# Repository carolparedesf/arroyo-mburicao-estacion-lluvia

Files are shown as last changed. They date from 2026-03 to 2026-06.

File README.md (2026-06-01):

# Sistema de adquisición y visualización de datos de sensores de lluvia
### Estaciones meteorológicas distribuidas — Arroyo Mburicao

---

## Descripción

Sistema de monitoreo pluviométrico distribuido a lo largo del arroyo Mburicao. Cada estación integra un sensor óptico de lluvia con comunicación RS485, una PCB propia basada en ESP32-S3 con componentes SMD, y transmisión de datos vía DTU con respaldo local en MicroSD. Los datos se visualizan en tiempo real a través de un dashboard web.

---

## Imágenes del hardware

| Render 3D | PCB | Placa soldada |
|---|---|---|
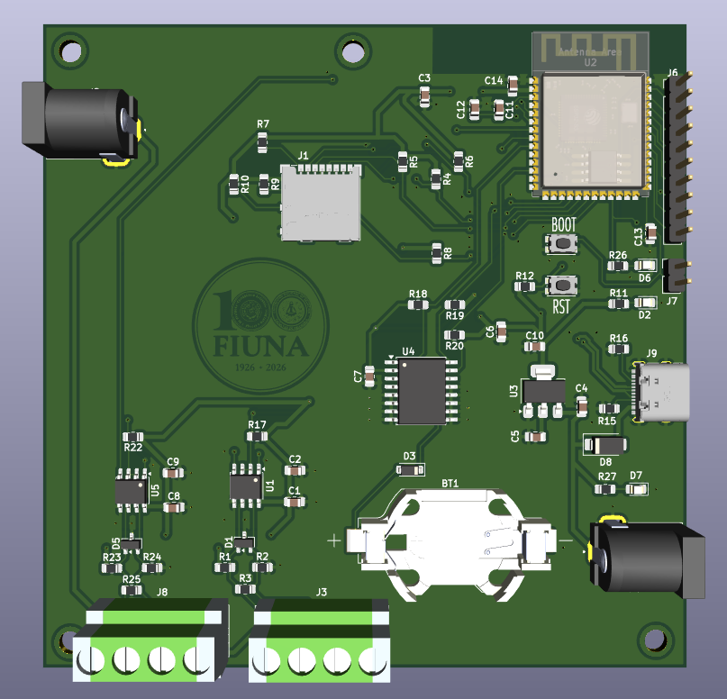
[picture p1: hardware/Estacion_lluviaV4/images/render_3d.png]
Render 3D
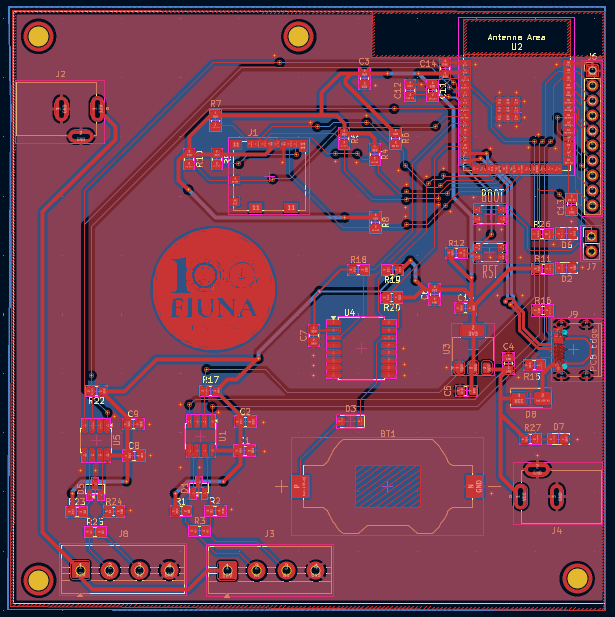
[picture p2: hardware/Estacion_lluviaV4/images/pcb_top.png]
PCB
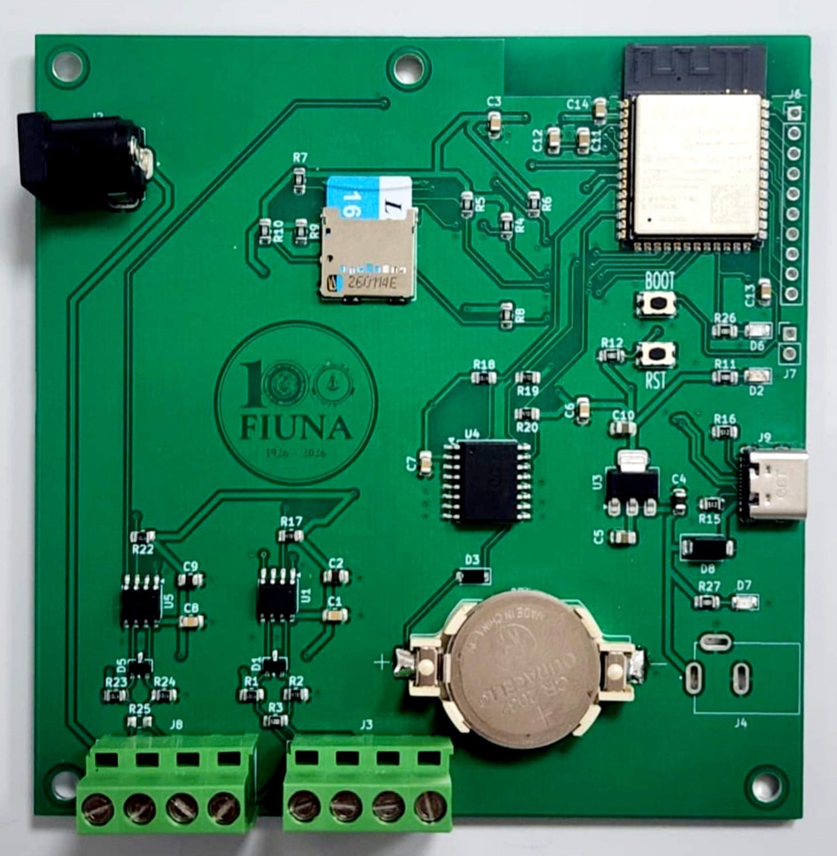
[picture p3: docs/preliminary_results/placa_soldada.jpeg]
Placa soldada
|  |  |  |

## Características principales

- Microcontrolador ESP32-S3 con componentes de montaje superficial (SMD)
- Sensor óptico de lluvia con interfaz RS485 / Modbus RTU
- Transmisión de datos vía DTU (RS485 canal 2)
- Almacenamiento local en MicroSD (`datalog.csv`) con cola de reintentos (`temp.csv`)
- RTC DS3231M para sincronización de slots de medición cada 60 segundos
- Alimentación con reductor a 3.3V
- Caja para intemperie compatible con la estructura de la estación meteorológica
- Dashboard web en tiempo real

---

## Estructura del repositorio

```
arroyo-mburicao-estacion-lluvia/
│
├── hardware/
│   └── Estacion_lluviaV4/
│       ├── BOM/                           # Lista de materiales
│       ├── images/                        # Renders 3D y fotos del PCB
│       ├── planos/                        # Planos técnicos 2D con cotas
│       ├── step/                          # Modelos 3D STEP
│       ├── Estacion_lluviaV4.kicad_pcb    # PCB
│       ├── Estacion_lluviaV4.kicad_sch    # Esquemático principal
│       ├── conector_USB.kicad_sch         # Sub-esquemático USB
│       ├── DS3231.kicad_sch               # Sub-esquemático RTC
│       ├── esp32_modulo.kicad_sch         # Sub-esquemático ESP32-S3
│       ├── sd_to_esp32.kicad_sch          # Sub-esquemático MicroSD
│       ├── ttl_to_rs485.kicad_sch         # Sub-esquemático RS485
│       └── vcc_to_3v3.kicad_sch           # Sub-esquemático alimentación
│
├── software/
│   ├── esp32s3_lluvia/                    # Proyecto principal ESP-IDF
│   │   ├── main/                          # Loop principal y pipeline
│   │   ├── components/                    # Drivers por módulo
│   │   │   ├── config/                    # Configuración de pines
│   │   │   ├── rtc/                       # Driver DS3231M (I2C)
│   │   │   ├── sdcard/                    # MicroSD (SPI + FAT)
│   │   │   ├── modbus_rtu/                # Modbus RTU (RS485 canal 1)
│   │   │   ├── dtu/                       # DTU (RS485 canal 2)
│   │   │   └── rs485/                     # Driver RS485 genérico
│   │   ├── CMakeLists.txt
│   │   └── sdkconfig                      # Configuración del proyecto
│   │
│   └── tests/                             # Pruebas aisladas por componente
│       ├── test_led/                      # Prueba LED debug
│       ├── test_rtc/                      # Prueba DS3231M
│       ├── test_sdcard/                   # Prueba MicroSD
│       └── test_modbus/                   # Prueba sensor lluvia Modbus RTU
│
├── mechanical/
│   ├── caja_tapa/                         # Modelo de la caja para intemperie
│   ├── ensamblaje/                        # Ensamblaje completo
│   └── soporte_sensor/                    # Estructura soporte del sensor
│
├── dashboard/
│   └── README.md                          # Link al repositorio del dashboard
│
└── docs/
    ├── report/                            # Informes de proceso y final
    └── photos/                            # Fotos del prototipo
```
---

## Hardware

### Diagrama de bloques

```
Sensor de lluvia (RS485/Modbus RTU)
            │
            ▼
        ESP32-S3
            ├── RTC DS3231M  (I2C)
            ├── MicroSD      (SPI)
            ├── RS485 canal 1 → Sensor de lluvia
            └── RS485 canal 2 → DTU → Base de datos en la nube
```

### Versiones del PCB

| Versión | Fecha | Estado |
|---|---|---|
| v1.0 | — | Fabricación inicial |
| v2.0 | — | Fabricación inicial |
| v3.0 | — | Fabricación inicial |
| v4.0 | — | En desarrollo |

Los archivos de fabricación se encuentran en `hardware/Estacion_lluviaV4/planos/`.

---

## Software

El código fuente del ESP32-S3 está desarrollado en **ESP-IDF (CMake)** e incluye drivers para RS485, Modbus RTU, DTU, RTC DS3231M y MicroSD.

| Módulo | Descripción |
|---|---|
| `esp32s3_lluvia` | Pipeline completo de medición y transmisión |
| `tests/test_led` | Prueba de LED de debug |
| `tests/test_rtc` | Prueba del RTC DS3231M |
| `tests/test_sdcard` | Prueba de MicroSD |
| `tests/test_modbus` | Prueba del sensor de lluvia vía Modbus RTU |

Ver descripción completa del flujo de operación en [`software/esp32s3_lluvia/README.md`](software/esp32s3_lluvia/README.md).

---

## Dashboard

El dashboard de visualización en línea está desarrollado en Next.js y desplegado en Vercel.

- 🔗 Repositorio: [hydromet-dashboard](https://github.com/carolparedesf/hydromet-dashboard)
- 🌐 Demo en vivo: [hydromet-dashboard.vercel.app](https://hydromet-dashboard.vercel.app)

---

## Costos

Ver lista de materiales completa en [`hardware/Estacion_lluviaV4/BOM/BOM_Estacion_lluviaV4.xlsx`](hardware/Estacion_lluviaV4/BOM/BOM_Estacion_lluviaV4.xlsx).

---

## Resultados

Las mediciones, pruebas y gráficas obtenidas se encuentran en [`docs/preiminary_results/`](docs/results_preiminary/).

---

## Equipo

| Integrante | Contacto |
|---|---|
| Victoria Paredes | carolparedesf@fiuna.edu.py |
| Francisco Gonzalez | frgonzalez@fiuna.edu.py  |
| Melissa Olmedo |  meliolmedo@fiuna.edu.py |

**Institución:** Universidad Nacional de Asunción — Facultad de Ingeniería
**Cátedra:** Proyecto 3 y 4

---

## Licencia

- Hardware: [CERN-OHL-P v2](LICENSE)
- Firmware: MIT
- Dashboard: MIT

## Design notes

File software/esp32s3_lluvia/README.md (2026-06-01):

|# Firmware ESP32-S3 — Estación de Lluvia

Firmware desarrollado en **ESP-IDF v6.1** para el ESP32-S3-WROOM-1.
Captura lluvia acumulada vía Modbus RTU, la almacena en MicroSD y la envía al servidor mediante DTU/RS485.

---

## Hardware

| Componente | Interfaz | GPIOs |
|---|---|---|
| Sensor de lluvia | RS485 / Modbus RTU | TX:IO1, RX:IO2, DE/RE:IO4 |
| DTU / Modem | RS485 | TX:IO5, RX:IO6, DE/RE:IO7 |
| RTC DS3231M | I2C | SDA:IO8, SCL:IO9, SQW:IO16 |
| MicroSD | SPI | CS:IO10, MOSI:IO11, CLK:IO12, MISO:IO13, DET:IO15 |
| LED debug | GPIO | IO21 |

---

## Estructura del proyecto
---
esp32s3_lluvia/
├── main/
│   ├── main.c              # Pipeline principal
│   └── CMakeLists.txt
├── components/
│   ├── config/             # Pines y parámetros centralizados (rs485_config.h)
│   ├── rtc/                # Driver DS3231 por I2C
│   ├── sdcard/             # MicroSD vía SPI + FATFS
│   ├── modbus_rtu/         # Modbus RTU manual (CRC16, FC03, FC06)
│   ├── dtu/                # Comunicación con DTU por RS485
│   └── rs485/              # Driver RS485 genérico
├── CMakeLists.txt
└── sdkconfig
## Configuración rápida

| Parámetro | Valor | Archivo |
|---|---|---|
| Período de medición | 60 segundos | `main.c` → `MEASUREMENT_PERIOD_SEC` |
| Offset horario | UTC-3 (Paraguay) | `main.c` → `SERVER_TIME_OFFSET_SEC` |
| Slave ID sensor | 1 | `rs485_config.h` → `RAIN_SLAVE_ID` |
| Registro lluvia | 0x006F | `rs485_config.h` → `RAIN_REGISTER_ACCUMULATED` |
| Baudrate sensor | 9600 | `rs485_config.h` → `SENSOR_BAUD_RATE` |
| Baudrate DTU | 9600 | `rs485_config.h` → `DTU_BAUD_RATE` |

---

## Flujo de operación
### Secuencia de arranque
Al encender, el sistema inicializa todos los periféricos en orden:

1. **DS3231 RTC** (I2C) — referencia de tiempo para los slots de medición
2. **MicroSD** (SPI) — almacenamiento local de `datalog.csv` y `temp.csv`
3. **Modbus RTU** (UART1) — comunicación con el sensor de lluvia
4. **DTU** (UART2) — transmisión remota de datos

### Loop principal (cada 50 ms)

**Slot de medición (cada 60 s, sincronizado con RTC)**

1. Leer lluvia acumulada del sensor (Modbus FC03, registro `0x006F`)
2. Guardar lectura en `/datalog.csv` (siempre, como registro permanente)
3. Verificar cola pendiente en `/temp.csv`:
   - **Cola vacía** → intentar transmisión por DTU
     - Éxito → listo
     - Fallo → guardar en `/temp.csv`
   - **Cola con pendientes** → guardar en `/temp.csv` (DTU ocupado/no disponible)
4. Resetear registro de lluvia en el sensor (Modbus FC06)

**Entre slots de medición (cada 10 s)**

- Reintentar entradas pendientes en `/temp.csv` vía DTU
- Si tiene éxito → entrada eliminada de la cola

### Resumen del flujo de datos

```
Sensor de lluvia (RS485)
        │
        ▼
    ESP32-S3
        ├──→ /datalog.csv   (registro local permanente)
        └──→ DTU (RS485)
                 ├── OK   → base de datos en la nube
                 └── FAIL → /temp.csv → reintento cada 10s
```
---

## Archivos en MicroSD

| Archivo | Contenido |
|---|---|
| `/datalog.csv` | Registro histórico completo de mediciones |
| `/temp.csv` | Cola FIFO de mediciones pendientes de envío |

Formato CSV:
Timestamp,Lluvia_mm
2026-05-22 17:41:00,1.5
---

## Compilar y flashear

```bash
# Activar entorno IDF
get_idf

# Entrar al proyecto
cd placa/firmware/esp32s3_lluvia

# Compilar
idf.py build

# Flashear y monitorear
idf.py -p /dev/ttyACM0 flash monitor
```

---

## Dependencias IDF

- `driver`, `esp_driver_uart`, `esp_driver_gpio`, `esp_driver_i2c`
- `fatfs`, `sdmmc`, `esp_driver_sdspi`
- `freertos`, `log`, `esp_common`

---

*PCB fabricado en JLCPCB — ESP32-S3-WROOM-1 — Mayo 2025*

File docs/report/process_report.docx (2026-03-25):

1. Resumen ejecutivo

Este trabajo consiste en el diseño e implementación de un sistema de adquisición y visualización de datos provenientes de sensores de lluvia instalados en estaciones meteorológicas distribuidas a lo largo del arroyo Mburicao. La propuesta surge ante la necesidad de contar con información local y distribuida sobre precipitaciones, que permita un mejor monitoreo del comportamiento pluviométrico en la zona.

El sistema desarrollado se basa en un sensor óptico de lluvia con comunicación RS485, el cual es integrado a una placa de circuito impreso con componentes de montaje superficial, incluyendo un microcontrolador ESP32. La placa incorpora la etapa de alimentación para reducir el voltaje a 3,3V, el circuito de interfaz RS485 y los elementos necesarios para la transmisión de datos mediante conexión inalámbrica (Wifi y GSM) y almacenamiento local (MicroSD).

Además del diseño electrónico, el proyecto contempla el desarrollo de una interfaz gráfica que permite visualizar en línea los datos adquiridos. Se incluye también el diseño de una estructura mecánica de soporte para el sensor, así como la selección de una caja adecuada para intemperie que garantice la protección del sistema electrónico.

2. Abstract

This work consists of the design and implementation of a data acquisition and visualization system for rainfall sensors installed at meteorological stations distributed along the Mburicao stream. The proposal arises from the need for local and distributed rainfall information to allow for better monitoring of pluviometric behavior in the area.

The developed system is based on an optical rain sensor with RS485 communication, which is integrated into a printed circuit board (PCB) with surface-mount components, including an ESP32 microcontroller. The board incorporates a power stage to reduce the voltage to 3.3V, an RS485 interface circuit, and the necessary elements for data transmission via wireless connection (Wi-Fi and GSM) and local storage (MicroSD).

In addition to the electronic design, the project covers the development of a graphical interface that allows for the online visualization of the acquired data. It also includes the design of a mechanical support structure for the sensor, as well as the selection of a suitable weatherproof enclosure to ensure the protection of the electronic system.

3. Estado del arte

Buscar al menos 4 referencias de proyecto o trabajo lo más similar posible, ya sea en Revistas científicas, de Ciencias y Tecnología o Universitarias, en tesis, en otros trabajos de grado, en artículos científicos, en catálogos comerciales, sitios web respaldados, etc. Nacionales y/o internacionales.

No son válidas referencias de foros o videos de YouTube que NO pertenezcan a alguna universidad, empresa o asociación formal y reconocida.

Citar la referencia con el estilo IEEE, y hablar sobre cada una.

Las referencias pueden ser sobre una parte del proyecto o de su totalidad.

4. Descripción

Describir la propuesta del proyecto y el foco que tendrá, los cuales pueden ser:

- Resolver un problema existente
- Responder a una pregunta de investigación
- Crear un prototipo de producto comercial
- Proponer un proceso para resolver un problema o mejorar una situación existente.

Mencionar la motivación que llevó a elegir el tema.

5. Objetivos
  a. General

Obtener datos de sensores de lluvia de estaciones meteorológicas distribuidas a lo largo del arroyo Mburicao.

  b. Específicos

Desarrollar una PCB propia para almacenamiento de datos e interfaz entre el sensor de lluvia y una base de datos en línea

Utilizar una caja apropiada para intemperie como medio de protección para la PCB compatible con la estructura de la estación meteorológica

Desarrollar una interfaz gráfica que permita visualizar en linea los datos adquiridos

Construir la estructura soporte para el sensor de lluvia compatible con la estación meteorológica

6. Esquema general del proyecto

Diagrama en bloques de interconexión de las partes: computador, electrónica, interfaces, sensores actuadores. Indicar los tipos de comunicación entre los componentes del sistema y niveles de alimentación (3.3V, 5V, 12V, u otros).

Describir cada una de las partes.

También se pueden incluir diagrama de flujo de datos o de programa.

6.1. Product Breakdown Structure (Estructura de desglose del producto)

7. Diseños
  a. Electrónico

Placas, esquemas, pinout (mapeo de pines).

Descripciones. Explicar si se aplica algún sistema de control.

  b. Mecánico [OBLIGATORIO PARA PROYECTO 4]

Boceto de la mecánica, por partes. Sus piezas. Uniones. Articulaciones. Accionamientos. Rodamientos.

Descripciones de las partes.

Anexar dibujo técnico que contenga una lámina rotulada por pieza independiente. Vistas alámbricas en 2D con cotas.

  c. Interfaz [OBLIGATORIO PARA PROYECTO 4]

Captura de pantalla de la interfaz de usuario.

Descripciones. Explicar si se aplica algún sistema de control.

8. Costos
  a. Materiales y herramientas compradas/incremental

Una tabla con descripción de los ítems, cantidades y montos.

  b. Materiales y herramientas prestadas/existentes

Una tabla sin montos, solo con descripción y cantidad.

9. Resultados parciales y finales

De las pruebas realizadas. Debe contener datos numéricos de mediciones. Puede estar discriminado por sus partes: Mecánica, Electrónica, Interfaz de usuario.

Pruebas realizadas (funcionales, unitarias, de estrés, etc.). Resultados cuantificables (tablas, gráficas). Análisis de los resultados: ¿cumplió con los objetivos?

Guardar las pruebas y resultados obtenidos en una carpeta compartida.

10. Conclusiones y recomendaciones finales

Lecciones aprendidas, qué funcionó y qué no, lista de recomendaciones para alguien que quiera continuar su proyecto, y mejoras futuras

11. Bibliografía
12. Anexos

Alumno 1, número de teléfono, email Alumno 2, número de teléfono, email Alumno 3, número de teléfono, email

Proyecto MCT - 2026 SISTEMA DE ADQUISICIÓN Y VISUALIZACIÓN DE DATOS DE SENSORES DE LLUVIA PARA ESTACIONES METEOROLÓGICAS DISTRIBUIDAS A LO LARGO DEL ARROYO MBURICAO

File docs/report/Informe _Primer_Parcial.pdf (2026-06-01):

Proyecto MCT - 2026
SISTEMA DE ADQUISICIÓN Y VISUALIZACIÓN DE DATOS DE SENSORES DE LLUVIA PARA ESTACIONES METEOROLÓGICAS DISTRIBUIDAS A LO LARGO DEL ARROYO MBURICAO

### 1. Resumen ejecutivo

El presente trabajo describe el diseño e implementación de un sistema de adquisición y visualización de datos pluviométricos distribuidos a lo largo del arroyo Mburicao. El sistema integra un sensor óptico de lluvia con una PCB propia basada en el microcontrolador ESP32, con transmisión de datos vía GSM y almacenamiento local en MicroSD. Los datos recolectados son accesibles en línea mediante una interfaz gráfica, y servirán como base para el desarrollo futuro de modelos de predicción de lluvia en la zona.

### 2. Abstract

This work presents the design and implementation of a distributed rainfall data acquisition and visualization system deployed along the Mburicao stream. The system integrates an optical rain sensor with a custom-designed PCB based on the ESP32 microcontroller, enabling data transmission via GSM and local storage on a MicroSD card. The collected data is accessible online through a graphical interface and will serve as a foundation for the future development of rainfall prediction models in the area.

### 3. Estado del arte

[1] M. Aguilar, H. Velázquez, D. H. Stalder, A. Wehrle, J. Ojeda y L. B. L. Santos, "Machine Learning Models for Water Level Prediction in Rapid Urban Streams: Case of Mburicaó, Asunción, Paraguay," 2025 LI Latin American Computer Conference (CLEI), Valparaíso, Chile, 2025, pp. 1-8, doi: 10.1109/CLEI67442.2025.11420547.

Este trabajo presenta modelos de aprendizaje automático para la predicción del nivel de agua en el arroyo Mburicaó, Asunción, Paraguay. Los autores evalúan distintos modelos predictivos — incluyendo máquinas de soporte vectorial — utilizando datos meteorológicos y de nivel de agua en tiempo real. El trabajo es directamente relevante al presente proyecto, ya que el arroyo Mburicaó es el mismo cuerpo de agua monitoreado y evidencia la necesidad de contar con datos pluviométricos locales y distribuidos como los que provee el sistema desarrollado, los cuales pueden servir como insumo para este tipo de modelos predictivos.

[2] S. C. Santos, R. M. Firmino, D. M. F. Mattos et al., "An IoT rainfall monitoring application based on wireless communication technologies," 2020 IEEE International Conference on

Ivan David Arias Acosta, 0971695762, ivanarias@fiuna.edu.py
Francisco Ramón Gónzalez Galeano, 0971735147, frgonzalez@fiuna.edu.py Melissa Olmedo Britos, 0991404102, meliolmedo@fiuna.edu.py
Victoria Carolina Paredes Frutos, 0981440425, carolparedesf@fiuna.edu.py

Proyecto MCT - 2026
SISTEMA DE ADQUISICIÓN Y VISUALIZACIÓN DE DATOS DE SENSORES DE LLUVIA PARA ESTACIONES METEOROLÓGICAS DISTRIBUIDAS A LO LARGO DEL ARROYO MBURICAO
Internet | of | Things | (iThings), | 2020. | doi:
10.1109/iThings-GreenCom-CPSCom-SmartData-Cybermatics50389.2020.9244293.

Este trabajo presenta un sistema de monitoreo de lluvia basado en IoT con transmisión inalámbrica de datos, compartiendo con el presente proyecto el enfoque de adquisición remota de precipitaciones mediante sensores conectados a microcontroladores y comunicación inalámbrica hacia una plataforma en línea.

[3] A. Musarat, H. Ismail et al., "Internet of Things Based Rainfall Monitoring System in Intelligent Agricultural System," International Journal of Scientific and Engineering Studies (IJSES), vol. 6, no. 10, pp. 1–6, 2022.

Este trabajo desarrolla un sistema de monitoreo de lluvia basado en IoT para agricultura inteligente, integrando sensores de lluvia, RTC y módem para la transmisión de datos. Su arquitectura de hardware es similar a la del presente proyecto, incluyendo el uso de un RTC para marcado temporal y almacenamiento local de los datos adquiridos.

[4] F. Colli, M. Stagnaro et al., "Advanced Real-Time Monitoring of Rainfall Using IoT Sensor Networks," Sensors, vol. 21, no. 3, p. 1108, 2021. doi: 10.3390/s21031108.

Este artículo presenta una red distribuida de sensores de lluvia bajo el paradigma IoT, orientada al monitoreo en tiempo real de precipitaciones en zonas no cubiertas por estaciones meteorológicas tradicionales. Es relevante porque aborda el mismo problema de cobertura distribuida que motiva el presente proyecto, destacando la importancia de contar con estaciones locales para mejorar la precisión del monitoreo pluviométrico.

### 4. Descripción

Este trabajo consiste en el diseño e implementación de un sistema de adquisición y visualización de datos provenientes de sensores de lluvia instalados en estaciones meteorológicas distribuidas a lo largo del arroyo Mburicao. La propuesta surge ante la necesidad de contar con información local y distribuida sobre precipitaciones, que permita un mejor monitoreo del comportamiento pluviométrico en la zona.

El sistema desarrollado se basa en un sensor óptico de lluvia con comunicación RS485, el cual es integrado a una placa de circuito impreso con componentes de montaje superficial, incluyendo un microcontrolador ESP32. La placa incorpora la etapa de alimentación para

Ivan David Arias Acosta, 0971695762, ivanarias@fiuna.edu.py
Francisco Ramón Gónzalez Galeano, 0971735147, frgonzalez@fiuna.edu.py

Proyecto MCT - 2026
SISTEMA DE ADQUISICIÓN Y VISUALIZACIÓN DE DATOS DE SENSORES DE LLUVIA PARA ESTACIONES METEOROLÓGICAS DISTRIBUIDAS A LO LARGO DEL ARROYO MBURICAO

reducir el voltaje a 3,3V, el circuito de interfaz RS485 y los elementos necesarios para la transmisión de datos mediante conexión inalámbrica (Wifi y GSM) y almacenamiento local (MicroSD).

Además del diseño electrónico, el proyecto contempla el desarrollo de una interfaz gráfica que permite visualizar en línea los datos adquiridos. Se incluye también el diseño de una estructura mecánica de soporte para el sensor, así como la selección de una caja adecuada para intemperie que garantice la protección del sistema electrónico.

### 5. Objetivos

a. General

Obtener datos de sensores de lluvia de estaciones meteorológicas distribuidas a lo largo del arroyo Mburicaó.

b. Específicos
- Desarrollar una PCB propia para almacenamiento de datos e interfaz entre el sensor de lluvia y una base de datos en línea.
- Utilizar una caja apropiada para intemperie como medio de protección para la PCB compatible con la estructura de la estación meteorológica.
- Desarrollar una interfaz gráfica que permita visualizar en línea los datos adquiridos
- Construir la estructura soporte para el sensor de lluvia compatible con la estación meteorológica.

### 6. Esquema general del proyecto

El sistema se compone de una etapa de adquisición de datos distribuida en campo y una etapa de visualización remota. La interconexión entre los bloques se ilustra en el diagrama en bloques de la Figura 1, donde se distinguen los componentes integrados en la placa SMD, los periféricos externos y la infraestructura remota.

Tipos de comunicación y niveles de alimentación

La red eléctrica de 220V alimenta la UPS, la cual entrega 5V al regulador AMS1117-3.3 y 12V directamente al sensor de precipitación y al módulo GSM. El regulador reduce la tensión a 3,3V para alimentar todos los componentes de la placa SMD. La comunicación

Ivan David Arias Acosta, 0971695762, ivanarias@fiuna.edu.py
Francisco Ramón Gónzalez Galeano, 0971735147, frgonzalez@fiuna.edu.py

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

entre el ESP32 y los transceptores SP3485EN se realiza mediante UART a 3,3V, siendo estos los encargados de convertir la señal al protocolo diferencial RS485. El RTC DS3231M se comunica con el ESP32 mediante I2C y la MicroSD mediante SPI, ambos a 3,3V.

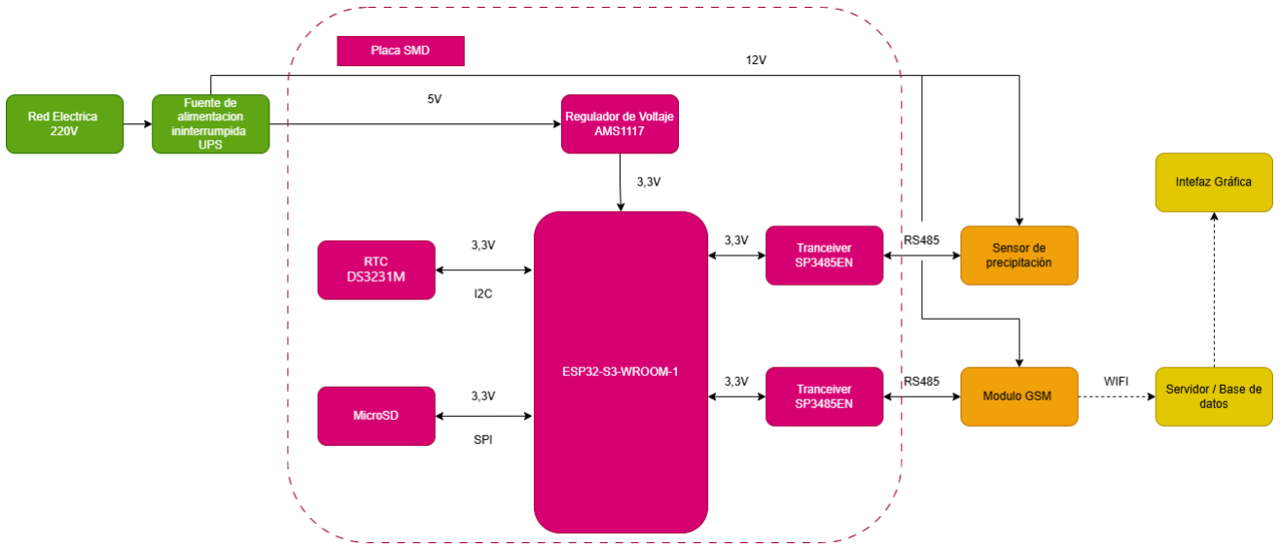
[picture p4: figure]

Figura 1: Diagrama en bloques del sistema

Descripción de cada bloque

Red eléctrica (220V): Fuente de alimentación principal que provee tensión a la UPS.

UPS: Garantiza la continuidad operativa ante cortes de energía. Entrega 5V a la placa SMD y 12V al sensor y al módulo GSM.

Placa SMD: Placa de circuito impreso con componentes de montaje superficial desarrollada en este proyecto. Integra el regulador de voltaje, el microcontrolador, los transceptores RS485, el RTC y la MicroSD.

Regulador AMS1117-3.3: Reduce los 5V de la UPS a 3,3V para alimentar los componentes de la placa.

Microcontrolador ESP32-S3-WROOM-1: Núcleo del sistema. Gestiona la adquisición de datos del sensor, el almacenamiento local y la transmisión remota, coordinando la comunicación con todos los periféricos.

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

Transceptor SP3485EN #1: Convierte las señales UART del ESP32 al protocolo RS485 para la comunicación con el sensor de precipitación.

Sensor de precipitación: Sensor óptico infrarrojo con salida RS485 y resolución de 0,1 mm. Mide la intensidad de lluvia y transmite los datos al ESP32. Se alimenta a 12V.

RTC DS3231M: Reloj de tiempo real de alta precisión que provee la marca temporal a cada registro de datos mediante I2C.

MicroSD: Almacenamiento local de los datos adquiridos mediante SPI. Actúa como respaldo ante pérdidas de conectividad.

Transceptor SP3485EN #2: Convierte las señales UART del ESP32 al protocolo RS485 para la comunicación con el módulo GSM.

Módulo GSM / DTU GPRS: Recibe los datos del ESP32 vía RS485 y los transmite mediante GPRS hacia el servidor remoto. Se alimenta a 12V.

Servidor / Base de datos: Recibe y almacena los datos enviados por el módulo GSM para su posterior visualización.

Interfaz gráfica: Dashboard web que permite visualizar en línea los datos de todas las estaciones meteorológicas.

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

### 6.1. Product Breakdown Structure (Estructura de desglose del producto)

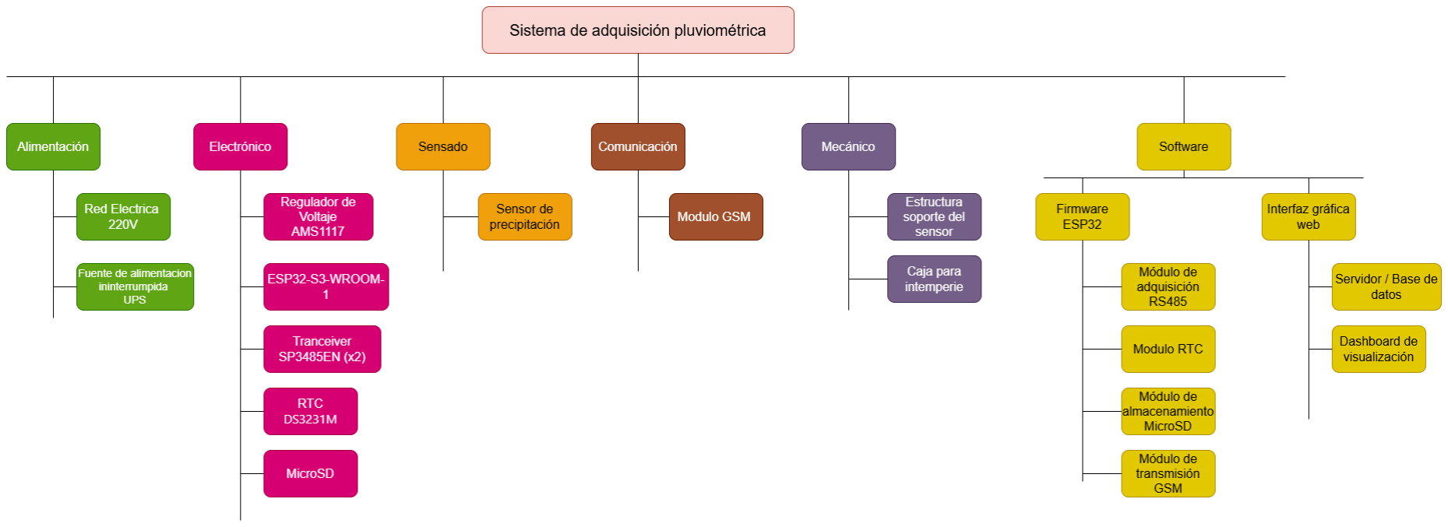
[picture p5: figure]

Figura 2: Estructura de desglose del producto

### 7. Diseños

a. Electrónico

Etapa de alimentación

Recibe 12V desde la UPS a través del conector de tornillo J3. La tensión es distribuida directamente al sensor de precipitación y al módulo GSM, y reducida a 3,3V mediante el regulador lineal AMS1117-3.3 (U3) para alimentar los componentes de la placa. Cuenta con capacitores de filtro de 10µF a la entrada y 22µF a la salida. La distribución de 12V hacia periféricos externos se realiza a través del conector J8.

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

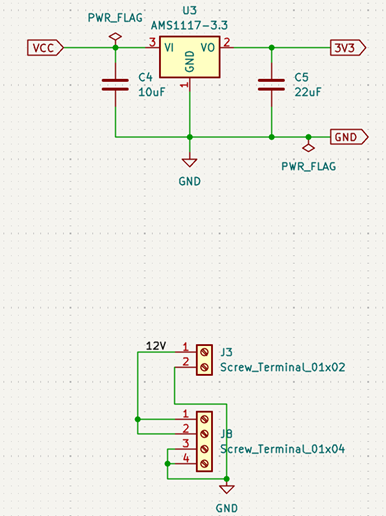
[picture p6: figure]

Figura 3: Circuito de alimentación del sistema

Microcontrolador ESP32-S3-WROOM-1 (U2)

Núcleo del sistema. Funciona a 3,3V y gestiona la comunicación con todos los periféricos. Incorpora un circuito de reset con resistencia de pull-up de 10kΩ y capacitor de 1µF, pulsador de reset manual (SW1) y pulsador de modo de programación (SW2 - BOOT). Cuenta con tres LEDs indicadores de estado: rojo (alimentación), verde (3,3V) y azul (GPIO21, controlado por firmware). La placa expone un conector de expansión de 20 pines (J6) con acceso a las señales principales del sistema.

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

Mapeo de pines:

GPIO (ESP32) | Componente conectado
GPIO1 | RO — RS485 canal #1
GPIO2 | DI — RS485 canal #1
GPIO4 | DE/RE — RS485 canal #1
GPIO5 | RO — RS485 canal #2
GPIO6 | DI — RS485 canal #2
GPIO7 | DE/RE — RS485 canal #2
GPIO17 | SDA — I2C
GPIO18 | SCL — I2C
GPIO16 | SQW — interrupción RTC
GPIO9 | SD CS
GPIO11 | SD MOSI
GPIO12 | SD CLK
GPIO13 | SD MISO
GPIO8 | SD DET
GPIO21 | LED azul

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

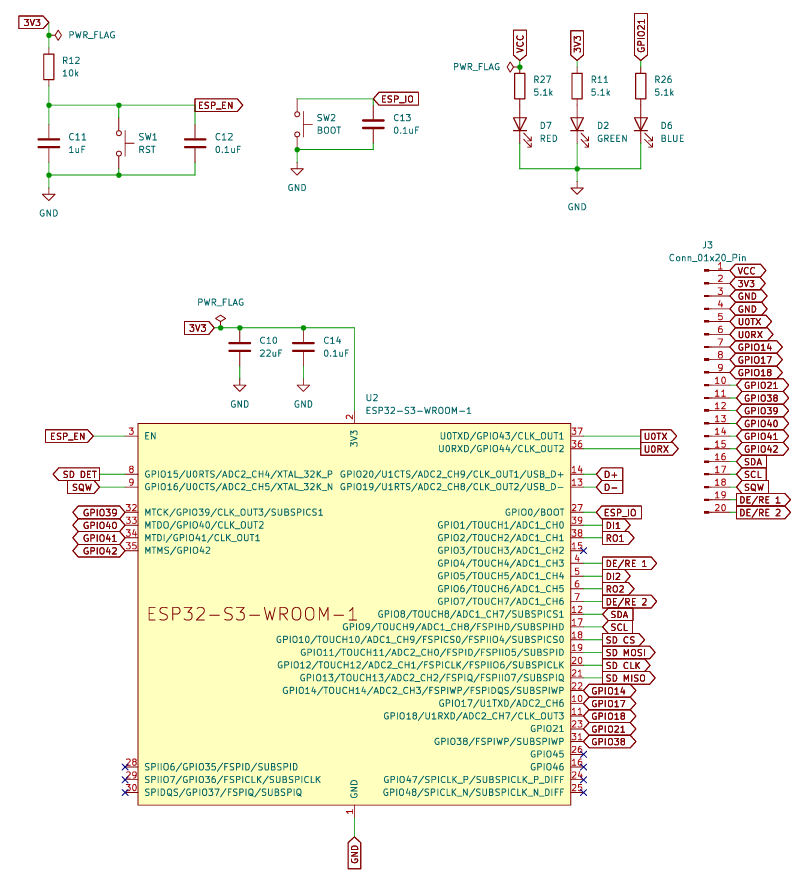
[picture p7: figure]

Figura 4: Pinout del ESP32 S3

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

Puerto USB-C (J9)

Permite la programación y depuración del ESP32 mediante las líneas D+ y D−. La tensión VBUS es conducida a través del diodo Schottky SS14 hacia el net VCC. Las resistencias de 5,1kΩ en las líneas CC1 y CC2 identifican el dispositivo como consumidor USB estándar.

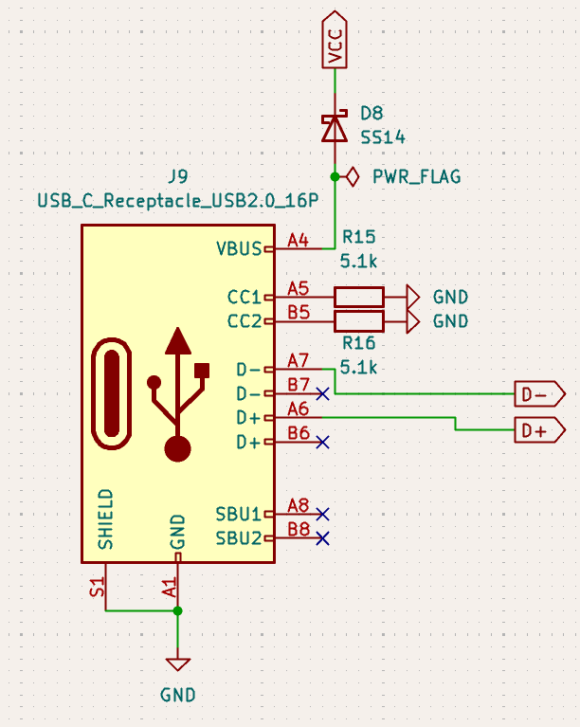
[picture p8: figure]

Figura 5: USB C utilizado

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

Transceptores RS485 — SP3485EN (U1 y U5)

Se integran dos canales RS485 independientes: el canal #1 para la comunicación con el sensor de precipitación (conector J4) y el canal #2 para la comunicación con el módulo GSM (conector J5). Cada canal incluye resistencias de polarización de 4,7kΩ en las líneas A y B, resistencia de terminación de 120Ω y protección contra transitorios mediante diodo TVS SM712. El control de dirección se realiza mediante las señales DE/RE del ESP32.

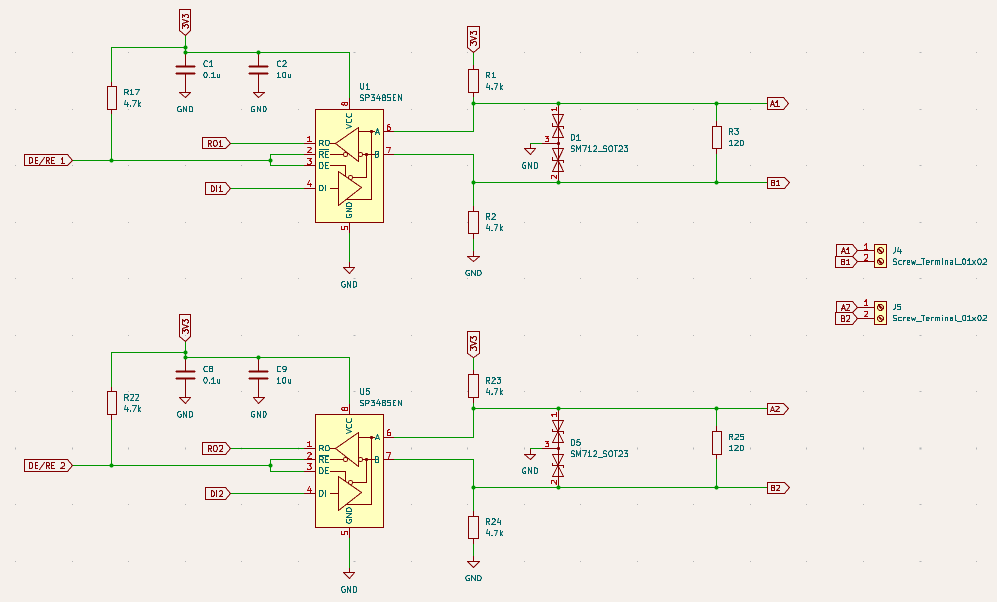
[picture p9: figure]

Figura 6:Transreceptores RS485

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

RTC DS3231M (U4)

Reloj de tiempo real de alta precisión con oscilador compensado por temperatura integrado. Se comunica con el ESP32 mediante I2C, con resistencias de pull-up de 4,7kΩ en las líneas SDA y SCL. Cuenta con batería de respaldo SMTU2032-LF conectada a través del diodo 1N4148, que mantiene el funcionamiento del reloj ante cortes de energía. La salida SQW se conecta al GPIO16 del ESP32 para generar interrupciones periódicas.

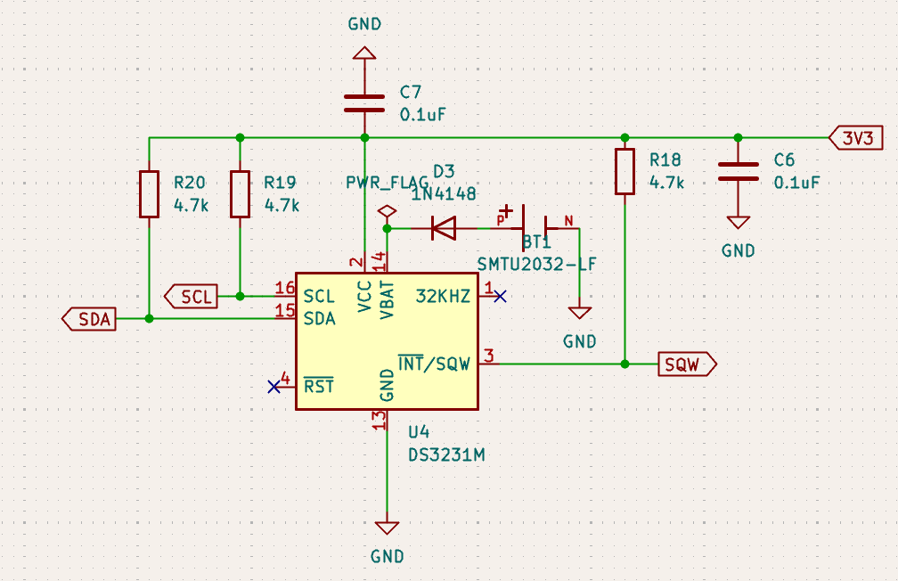
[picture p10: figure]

Figura 7:Reloj de tiempo real

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

Módulo MicroSD (J1)

Conectado al ESP32 mediante interfaz SPI. Todas las líneas de datos cuentan con resistencias de pull-up de 10kΩ y un pin de detección de tarjeta (SD DET) en GPIO8 que permite verificar por software la presencia de la tarjeta antes de realizar operaciones de lectura o escritura.

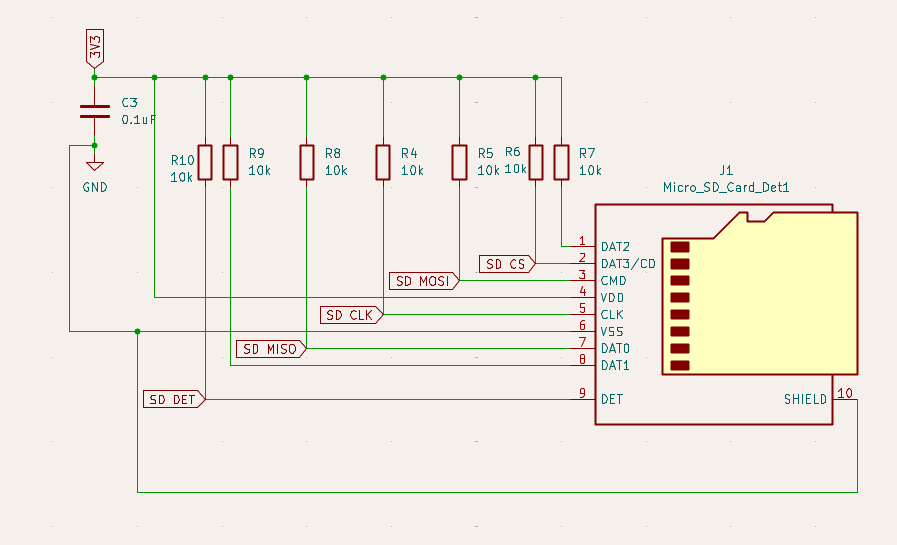
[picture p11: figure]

Figura 8: Módulo MicroSD

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

Proyecto MCT - 2026
SISTEMA DE ADQUISICIÓN Y VISUALIZACIÓN DE DATOS DE SENSORES DE LLUVIA PARA ESTACIONES METEOROLÓGICAS DISTRIBUIDAS A LO LARGO DEL ARROYO MBURICAO
b. Mecánico

El diseño tiene como objetivo principal albergar el sistema de adquisición de datos y garantizar el posicionamiento óptimo del sensor óptico de lluvia. La estructura se divide en tres partes principales: la caja, la tapa y el soporte del sensor.

El diseño de la caja se basa en la caja de paso con certificación ip65, lo que asegura un grado de protección para la electrónica interna. Sus dimensiones de base son de 310 mm x 210 mm y una profundidad de 110 mm, la parte superior se expande a 314 mm x 214 mm. El cuerpo de la caja integra un reborde perimetral que permite un ajuste por encastre con la tapa, lo que refuerza la hermeticidad del conjunto.

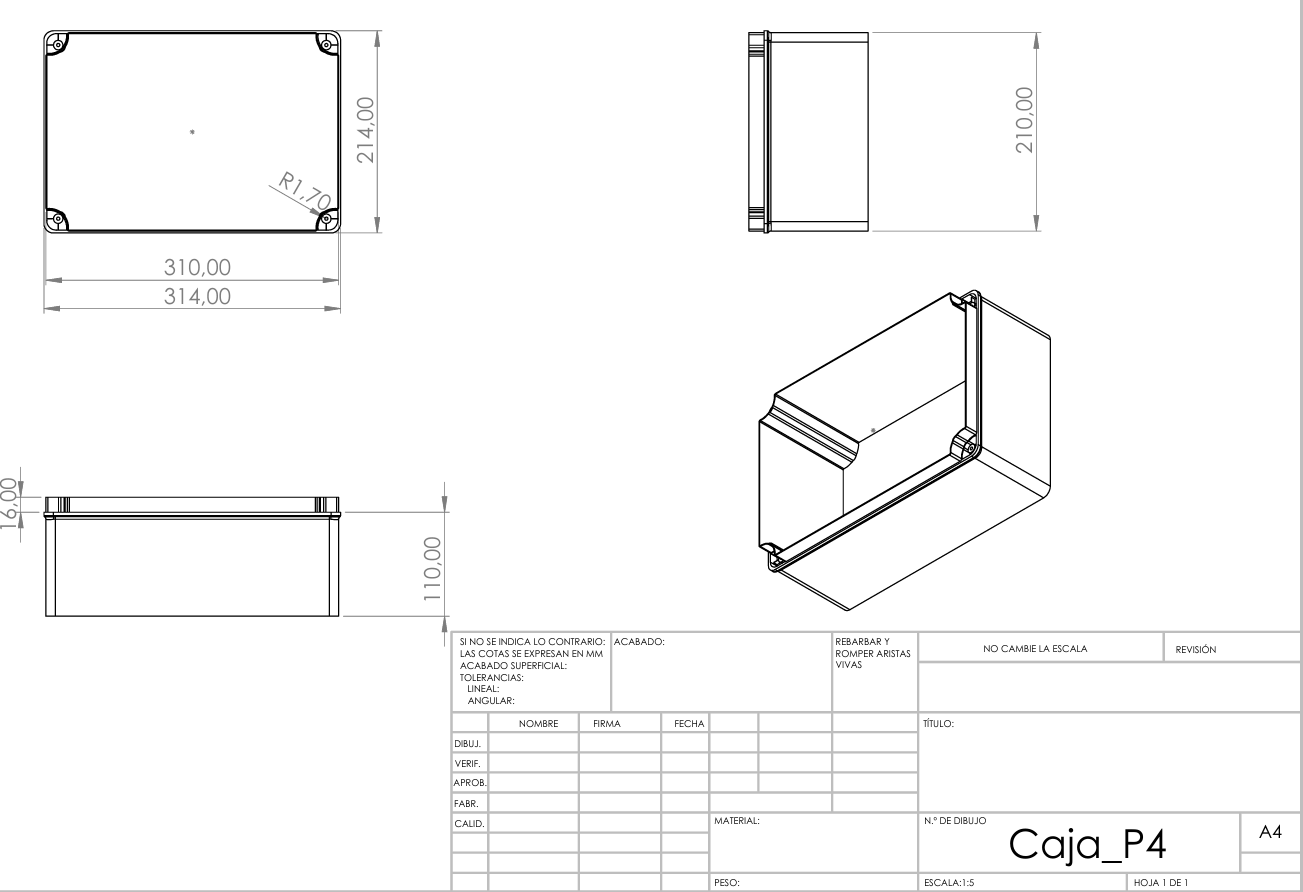
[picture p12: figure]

Figura 9: Diseño de Caja

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

La tapa cuenta con un espesor externo de 17 mm, y se fija mediante cuatro puntos de anclaje en las esquinas.

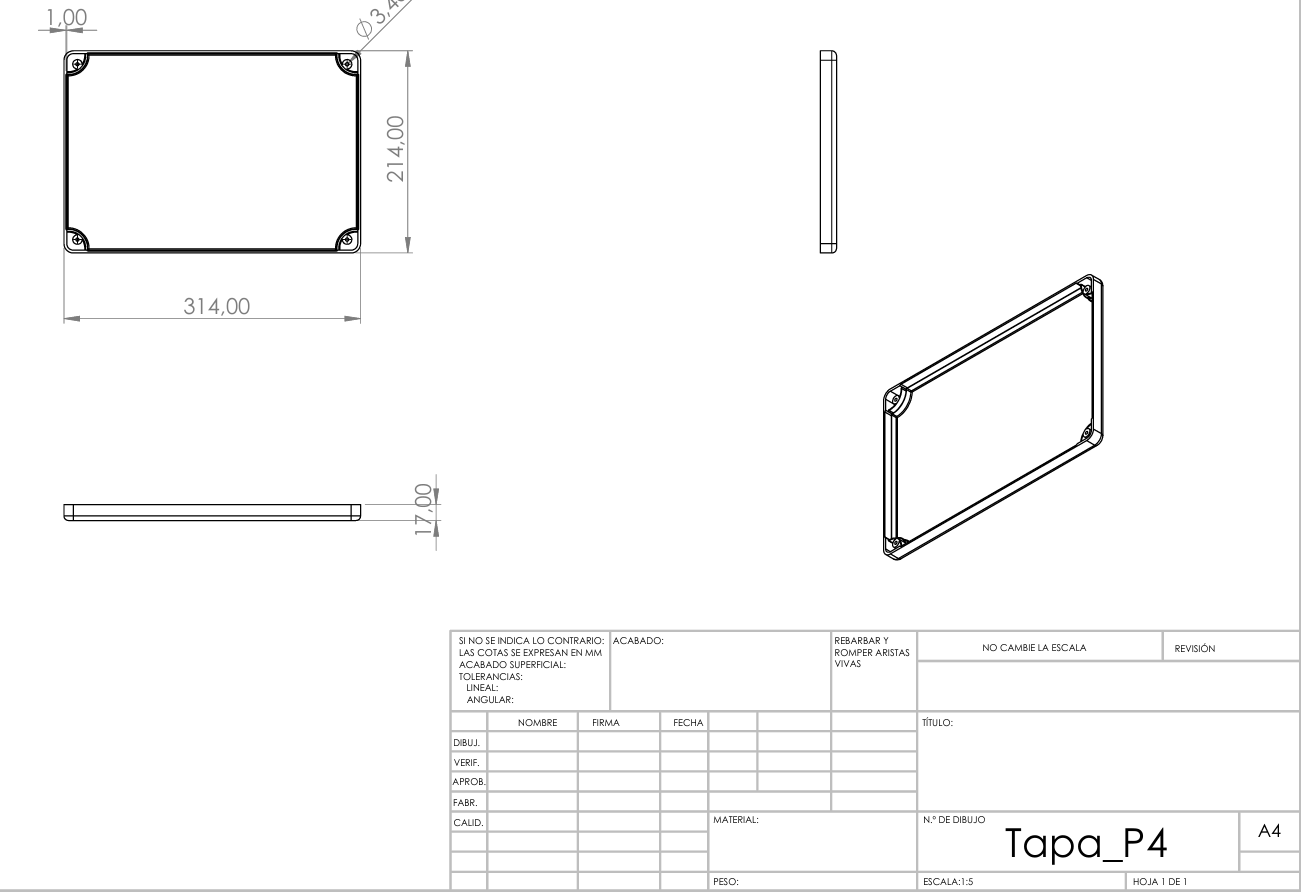
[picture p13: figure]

Figura 10: Diseño de Tapa

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

Para el soporte del sensor se ha diseñado una placa de montaje de 100 mm por 80 mm, este integra una inclinación de 15 grados, esta angulación es muy importante para los sensores de lluvia ópticos, ya que facilita el escurrimiento natural del agua sobre la cúpula del mismo, evitando lecturas falsas. La base del soporte presenta un calado circular de radio 39 mm, que coincide exactamente con el diámetro de la base del sensor, además, este se fija mediante dos orificios de 5 mm de diámetro alineados con los puntos de sujeción del sensor.

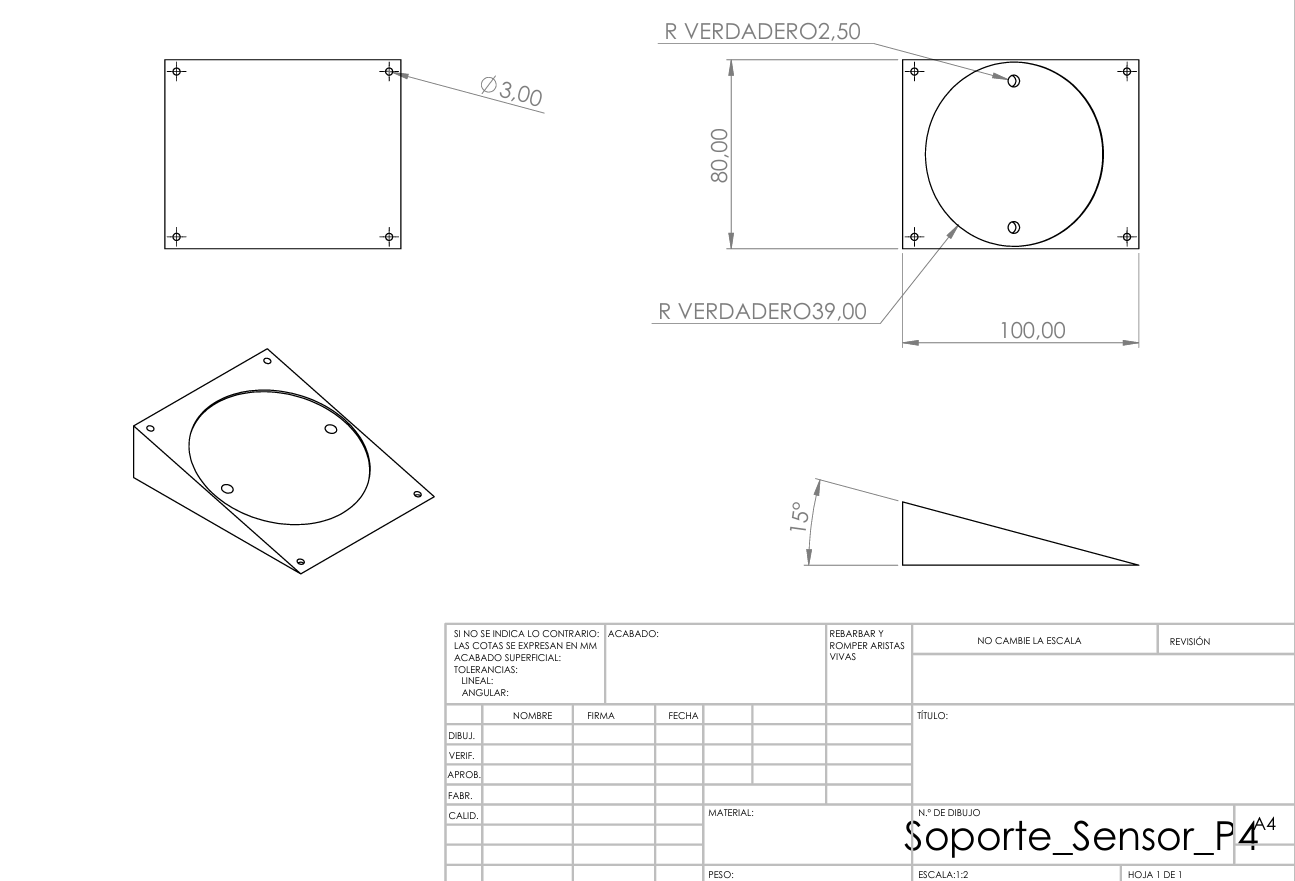
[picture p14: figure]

Figura 11: Diseño de Soporte

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

Proyecto MCT - 2026
SISTEMA DE ADQUISICIÓN Y VISUALIZACIÓN DE DATOS DE SENSORES DE LLUVIA PARA ESTACIONES METEOROLÓGICAS DISTRIBUIDAS A LO LARGO DEL ARROYO MBURICAO
c. Interfaz [OBLIGATORIO PARA PROYECTO 4]

Captura de pantalla de la interfaz de usuario.

Descripciones. Explicar si se aplica algún sistema de control.

### 8. Costos

a. Materiales y herramientas compradas/incremental
Componentes Mfr. | Descripción | Cantidad | Precio (USD) | Precio Total (USD)
SMLD12E3N1WT86 | LED azul SMD 0603 indicador | 1,00 | 0,87 | 0,87
RNAN0603BKE10K 0 | Resistencia 10kΩ 0603 pull-up/pull-down | 8,00 | 0,98 | 7,84
RNAN0603BKE4K7 0 | Resistencia 4.7kΩ 0603 para buses I2C/UART | 9,00 | 0,98 | 8,82
C0603J104K4RACT U | Capacitor cerámico 100nF 0603 | 8,00 | 0,20 | 1,6
RNAN0603BKE120 R | Resistencia 120Ω 0603 terminación CAN/RS485 | 2,00 | 0,98 | 1,96
ESP32-S3-WROOM -1-N16R8 | Módulo WiFi/Bluetooth MCU principal 16MB Flash | 1,00 | 6,71 | 6,71
C0805J224K5RACT U | Capacitor electrolítico 22µF 0805 filtrado de alimentación | 2,00 | 0,34 | 0,68
282856-2 | Bornera tornillo 2 pines 5.0mm conexión externa | 3,00 | 1,38 | 4,14
SMLD12E3N1WT86 | LED rojo SMD 0603 indicador estado | 1,00 | 0,69 | 0,69
SP3485EN-L/TR | Transceptor RS-485/RS-422 3.3V SOIC-8 | 2,00 | 0,80 | 1,6
SM712-02HTG | Diodo protección TVS para RS-485 7V/12V | 2,00 | 0,64 | 1,28
SMLD12E3N1WT86 | LED verde SMD 0603 indicador | 1,00 | 0,69 | 0,69

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

Proyecto MCT - 2026
SISTEMA DE ADQUISICIÓN Y VISUALIZACIÓN DE DATOS DE SENSORES DE LLUVIA PARA ESTACIONES METEOROLÓGICAS DISTRIBUIDAS A LO LARGO DEL ARROYO MBURICAO
| alimentación/estado
KMR223G LFG | Pulsador táctil SMD reset del sistema | 1,00 | 0,80 | 0,8
282856-4 | Bornera tornillo 4 pines 5.0mm alimentación/sensores | 1,00 | 2,58 | 2,58
KMR223G LFG | Pulsador táctil SMD modo bootloader/programación | 1,00 | 0,80 | 0,8
USB4930-00-A | Conector USB-C 2.0 16 pines alimentación/datos | 1,00 | 0,51 | 0,51
VS-MBRA140TRPB F | Diodo Schottky 1A 40V SMA protección polaridad | 1,00 | 0,24 | 0,24
104031-0811 | Slot tarjeta microSD con detección almacenamiento | 1,00 | 2,04 | 2,04
RNAN0603BKE5K1 0 | Resistencia 5.1kΩ 0603 para USB-C CC1/CC2 | 2,00 | 0,98 | 1,96
C0805X106K9RAC TU | Capacitor electrolítico 10µF 0805 filtrado bulk | 3,00 | 0,88 | 2,64
C0603X105J4RAC7 411 | Capacitor cerámico 1µF 0603 filtrado de señal | 1,00 | 0,49 | 0,49
RNAN0603BKE1K0 0 | Resistencia 1kΩ 0603 limitación corriente LED | 3,00 | 0,98 | 2,94
SMTU2032-C.TR | Soporte batería CR2032 SMT para RTC backup | 1,00 | 1,87 | 1,87
1N4148WQ-7-F | Diodo conmutación rápida SOD-123 protección | 1,00 | 0,13 | 0,13
DS3231M+ | RTC (reloj tiempo real) I2C alta precisión ±5ppm | 1,00 | 13,60 | 13,6
LDL1117S33R | Regulador LDO 3.3V SOT-223 alimentación del sistema | 1,00 | 0,74 | 0,74
TOTAL | | | | 68,22

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

Proyecto MCT - 2026
SISTEMA DE ADQUISICIÓN Y VISUALIZACIÓN DE DATOS DE SENSORES DE LLUVIA PARA ESTACIONES METEOROLÓGICAS DISTRIBUIDAS A LO LARGO DEL ARROYO MBURICAO
b. Materiales y herramientas prestadas/existentes
Componente | Descripción | Cantidad
Sensor óptico de lluvia RS485 | Sensor infrarrojo de pulso con salida RS485, resolución 0,1 mm, doble canal, alimentación 5-12V DC | 1
Módulo GSM / DTU GPRS | Unidad terminal de datos RS232/485 a GPRS con antena GSM externa, alimentación 12V | 1
Pin headers | Espadín 1x02 pines, paso 1.00mm, vertical | 1
Pin headers | Espadín 1x10 pines, paso 1.00mm, vertical | 1

### 9. Resultados parciales y finales

De las pruebas realizadas. Debe contener datos numéricos de mediciones. Puede estar discriminado por sus partes: Mecánica, Electrónica, Interfaz de usuario.

Pruebas realizadas (funcionales, unitarias, de estrés, etc.). Resultados cuantificables (tablas, gráficas). Análisis de los resultados: ¿cumplió con los objetivos?

Guardar las pruebas y resultados obtenidos en una carpeta compartida.

### 10. Conclusiones y recomendaciones finales

Lecciones aprendidas, qué funcionó y qué no, lista de recomendaciones para alguien que quiera continuar su proyecto, y mejoras futuras

### 11. Bibliografía 12. Anexos

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

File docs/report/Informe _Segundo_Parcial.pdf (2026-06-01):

Proyecto MCT - 2026
SISTEMA DE ADQUISICIÓN Y VISUALIZACIÓN DE DATOS DE SENSORES DE LLUVIA PARA ESTACIONES METEOROLÓGICAS DISTRIBUIDAS A LO LARGO DEL ARROYO MBURICAO

### 1. Resumen ejecutivo

El presente trabajo describe el diseño e implementación de un sistema de adquisición y visualización de datos pluviométricos distribuidos a lo largo del arroyo Mburicao. El sistema integra un sensor óptico de lluvia con una PCB propia basada en el microcontrolador ESP32, con transmisión de datos vía GSM y almacenamiento local en MicroSD. Los datos recolectados son accesibles en línea mediante una interfaz gráfica, y servirán como base para el desarrollo futuro de modelos de predicción de lluvia en la zona.

### 2. Abstract

This work presents the design and implementation of a distributed rainfall data acquisition and visualization system deployed along the Mburicao stream. The system integrates an optical rain sensor with a custom-designed PCB based on the ESP32 microcontroller, enabling data transmission via GSM and local storage on a MicroSD card. The collected data is accessible online through a graphical interface and will serve as a foundation for the future development of rainfall prediction models in the area.

### 3. Estado del arte

[1] M. Aguilar, H. Velázquez, D. H. Stalder, A. Wehrle, J. Ojeda y L. B. L. Santos, "Machine Learning Models for Water Level Prediction in Rapid Urban Streams: Case of Mburicaó, Asunción, Paraguay," 2025 LI Latin American Computer Conference (CLEI), Valparaíso, Chile, 2025, pp. 1-8, doi: 10.1109/CLEI67442.2025.11420547.

Este trabajo presenta modelos de aprendizaje automático para la predicción del nivel de agua en el arroyo Mburicaó, Asunción, Paraguay. Los autores evalúan distintos modelos predictivos — incluyendo máquinas de soporte vectorial — utilizando datos meteorológicos y de nivel de agua en tiempo real. El trabajo es directamente relevante al presente proyecto, ya que el arroyo Mburicaó es el mismo cuerpo de agua monitoreado y evidencia la necesidad de contar con datos pluviométricos locales y distribuidos como los que provee el sistema desarrollado, los cuales pueden servir como insumo para este tipo de modelos predictivos.

[2] S. C. Santos, R. M. Firmino, D. M. F. Mattos et al., "An IoT rainfall monitoring application based on wireless communication technologies," 2020 IEEE International Conference on

Ivan David Arias Acosta, 0971695762, ivanarias@fiuna.edu.py
Francisco Ramón González Galeano, 0971735147, frgonzalez@fiuna.edu.py Melissa Olmedo Britos, 0991404102, meliolmedo@fiuna.edu.py
Victoria Carolina Paredes Frutos, 0981440425, carolparedesf@fiuna.edu.py

Proyecto MCT - 2026
SISTEMA DE ADQUISICIÓN Y VISUALIZACIÓN DE DATOS DE SENSORES DE LLUVIA PARA ESTACIONES METEOROLÓGICAS DISTRIBUIDAS A LO LARGO DEL ARROYO MBURICAO
Internet | of | Things | (iThings), | 2020. | doi:
10.1109/iThings-GreenCom-CPSCom-SmartData-Cybermatics50389.2020.9244293.

Este trabajo presenta un sistema de monitoreo de lluvia basado en IoT con transmisión inalámbrica de datos, compartiendo con el presente proyecto el enfoque de adquisición remota de precipitaciones mediante sensores conectados a microcontroladores y comunicación inalámbrica hacia una plataforma en línea.

[3] A. Musarat, H. Ismail et al., "Internet of Things Based Rainfall Monitoring System in Intelligent Agricultural System," International Journal of Scientific and Engineering Studies (IJSES), vol. 6, no. 10, pp. 1–6, 2022.

Este trabajo desarrolla un sistema de monitoreo de lluvia basado en IoT para agricultura inteligente, integrando sensores de lluvia, RTC y módem para la transmisión de datos. Su arquitectura de hardware es similar a la del presente proyecto, incluyendo el uso de un RTC para marcado temporal y almacenamiento local de los datos adquiridos.

[4] F. Colli, M. Stagnaro et al., "Advanced Real-Time Monitoring of Rainfall Using IoT Sensor Networks," Sensors, vol. 21, no. 3, p. 1108, 2021. doi: 10.3390/s21031108.

Este artículo presenta una red distribuida de sensores de lluvia bajo el paradigma IoT, orientada al monitoreo en tiempo real de precipitaciones en zonas no cubiertas por estaciones meteorológicas tradicionales. Es relevante porque aborda el mismo problema de cobertura distribuida que motiva el presente proyecto, destacando la importancia de contar con estaciones locales para mejorar la precisión del monitoreo pluviométrico.

### 4. Descripción

Este trabajo consiste en el diseño e implementación de un sistema de adquisición y visualización de datos provenientes de sensores de lluvia instalados en estaciones meteorológicas distribuidas a lo largo del arroyo Mburicao. La propuesta surge ante la necesidad de contar con información local y distribuida sobre precipitaciones, que permita un mejor monitoreo del comportamiento pluviométrico en la zona.

El sistema desarrollado se basa en un sensor óptico de lluvia con comunicación RS485, el cual es integrado a una placa de circuito impreso con componentes de montaje superficial, incluyendo un microcontrolador ESP32. La placa incorpora la etapa de alimentación para

Ivan David Arias Acosta, 0971695762, ivanarias@fiuna.edu.py
Francisco Ramón González Galeano, 0971735147, frgonzalez@fiuna.edu.py

Proyecto MCT - 2026
SISTEMA DE ADQUISICIÓN Y VISUALIZACIÓN DE DATOS DE SENSORES DE LLUVIA PARA ESTACIONES METEOROLÓGICAS DISTRIBUIDAS A LO LARGO DEL ARROYO MBURICAO

reducir el voltaje a 3,3V, el circuito de interfaz RS485 y los elementos necesarios para la transmisión de datos mediante conexión inalámbrica (Wifi y GSM) y almacenamiento local (MicroSD).

Además del diseño electrónico, el proyecto contempla el desarrollo de una interfaz gráfica que permite visualizar en línea los datos adquiridos. Se incluye también el diseño de una estructura mecánica de soporte para el sensor, así como la selección de una caja adecuada para intemperie que garantice la protección del sistema electrónico.

### 5. Objetivos

a. General

Obtener datos de sensores de lluvia de estaciones meteorológicas distribuidas a lo largo del arroyo Mburicaó.

b. Específicos
- Desarrollar una PCB propia para almacenamiento de datos e interfaz entre el sensor de lluvia y una base de datos en línea.
- Utilizar una caja apropiada para intemperie como medio de protección para la PCB compatible con la estructura de la estación meteorológica.
- Desarrollar una interfaz gráfica que permita visualizar en línea los datos adquiridos
- Construir la estructura soporte para el sensor de lluvia compatible con la estación meteorológica.

### 6. Esquema general del proyecto

El sistema se compone de una etapa de adquisición de datos distribuida en campo y una etapa de visualización remota. La interconexión entre los bloques se ilustra en el diagrama en bloques de la Figura 1, donde se distinguen los componentes integrados en la placa SMD, los periféricos externos y la infraestructura remota.

Tipos de comunicación y niveles de alimentación

La red eléctrica de 220V alimenta la UPS, la cual entrega 5V al regulador AMS1117-3.3 y 12V directamente al sensor de precipitación y al módulo GSM. El regulador reduce la tensión a 3,3V para alimentar todos los componentes de la placa SMD. La comunicación

Ivan David Arias Acosta, 0971695762, ivanarias@fiuna.edu.py
Francisco Ramón González Galeano, 0971735147, frgonzalez@fiuna.edu.py

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

entre el ESP32 y los transceptores SP3485EN se realiza mediante UART a 3,3V, siendo estos los encargados de convertir la señal al protocolo diferencial RS485. El RTC DS3231M se comunica con el ESP32 mediante I2C y la MicroSD mediante SPI, ambos a 3,3V.


Figura 1: Diagrama en bloques del sistema

Descripción de cada bloque

Red eléctrica (220V): Fuente de alimentación principal que provee tensión a la UPS.

UPS: Garantiza la continuidad operativa ante cortes de energía. Entrega 5V a la placa SMD y 12V al sensor y al módulo GSM.

Placa SMD: Placa de circuito impreso con componentes de montaje superficial desarrollada en este proyecto. Integra el regulador de voltaje, el microcontrolador, los transceptores RS485, el RTC y la MicroSD.

Regulador AMS1117-3.3: Reduce los 5V de la UPS a 3,3V para alimentar los componentes de la placa.

Microcontrolador ESP32-S3-WROOM-1: Núcleo del sistema. Gestiona la adquisición de datos del sensor, el almacenamiento local y la transmisión remota, coordinando la comunicación con todos los periféricos.

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

Transceptor SP3485EN #1: Convierte las señales UART del ESP32 al protocolo RS485 para la comunicación con el sensor de precipitación.

Sensor de precipitación: Sensor óptico infrarrojo con salida RS485 y resolución de 0,1 mm. Mide la intensidad de lluvia y transmite los datos al ESP32. Se alimenta a 12V.

RTC DS3231M: Reloj de tiempo real de alta precisión que provee la marca temporal a cada registro de datos mediante I2C.

MicroSD: Almacenamiento local de los datos adquiridos mediante SPI. Actúa como respaldo ante pérdidas de conectividad.

Transceptor SP3485EN #2: Convierte las señales UART del ESP32 al protocolo RS485 para la comunicación con el módulo GSM.

Módulo GSM / DTU GPRS: Recibe los datos del ESP32 vía RS485 y los transmite mediante GPRS hacia el servidor remoto. Se alimenta a 12V.

Servidor / Base de datos: Recibe y almacena los datos enviados por el módulo GSM para su posterior visualización.

Interfaz gráfica: Dashboard web que permite visualizar en línea los datos de todas las estaciones meteorológicas.

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

### 6.1. Product Breakdown Structure (Estructura de desglose del producto)


Figura 2: Estructura de desglose del producto

### 7. Diseños

a. Electrónico

Etapa de alimentación

Recibe 12V desde la UPS a través del conector de tornillo J3. La tensión es distribuida directamente al sensor de precipitación y al módulo GSM, y reducida a 3,3V mediante el regulador lineal AMS1117-3.3 (U3) para alimentar los componentes de la placa. Cuenta con capacitores de filtro de 10µF a la entrada y 22µF a la salida. La distribución de 12V hacia periféricos externos se realiza a través del conector J8.

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


Figura 3: Circuito de alimentación del sistema

Microcontrolador ESP32-S3-WROOM-1 (U2)

Núcleo del sistema. Funciona a 3,3V y gestiona la comunicación con todos los periféricos. Incorpora un circuito de reset con resistencia de pull-up de 10kΩ y capacitor de 1µF, pulsador de reset manual (SW1) y pulsador de modo de programación (SW2 - BOOT). Cuenta con tres LEDs indicadores de estado: rojo (alimentación), verde (3,3V) y azul (GPIO21, controlado por firmware). La placa expone un conector de expansión de 20 pines (J6) con acceso a las señales principales del sistema.

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

Mapeo de pines:

GPIO (ESP32) | Componente conectado
GPIO1 | RO — RS485 canal #1
GPIO2 | DI — RS485 canal #1
GPIO4 | DE/RE — RS485 canal #1
GPIO5 | RO — RS485 canal #2
GPIO6 | DI — RS485 canal #2
GPIO7 | DE/RE — RS485 canal #2
GPIO17 | SDA — I2C
GPIO18 | SCL — I2C
GPIO16 | SQW — interrupción RTC
GPIO9 | SD CS
GPIO11 | SD MOSI
GPIO12 | SD CLK
GPIO13 | SD MISO
GPIO8 | SD DET
GPIO21 | LED azul

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


Figura 4: Pinout del ESP32 S3

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

Puerto USB-C (J9)

Permite la programación y depuración del ESP32 mediante las líneas D+ y D−. La tensión VBUS es conducida a través del diodo Schottky SS14 hacia el net VCC. Las resistencias de 5,1kΩ en las líneas CC1 y CC2 identifican el dispositivo como consumidor USB estándar.


Figura 5: USB C utilizado

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

Transceptores RS485 — SP3485EN (U1 y U5)

Se integran dos canales RS485 independientes: el canal #1 para la comunicación con el sensor de precipitación (conector J4) y el canal #2 para la comunicación con el módulo GSM (conector J5). Cada canal incluye resistencias de polarización de 4,7kΩ en las líneas A y B, resistencia de terminación de 120Ω y protección contra transitorios mediante diodo TVS SM712. El control de dirección se realiza mediante las señales DE/RE del ESP32.


Figura 6:Transreceptores RS485

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

RTC DS3231M (U4)

Reloj de tiempo real de alta precisión con oscilador compensado por temperatura integrado. Se comunica con el ESP32 mediante I2C, con resistencias de pull-up de 4,7kΩ en las líneas SDA y SCL. Cuenta con batería de respaldo SMTU2032-LF conectada a través del diodo 1N4148, que mantiene el funcionamiento del reloj ante cortes de energía. La salida SQW se conecta al GPIO16 del ESP32 para generar interrupciones periódicas.


Figura 7:Reloj de tiempo real

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

Módulo MicroSD (J1)

Conectado al ESP32 mediante interfaz SPI. Todas las líneas de datos cuentan con resistencias de pull-up de 10kΩ y un pin de detección de tarjeta (SD DET) en GPIO8 que permite verificar por software la presencia de la tarjeta antes de realizar operaciones de lectura o escritura.


Figura 8: Módulo MicroSD

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

Proyecto MCT - 2026
SISTEMA DE ADQUISICIÓN Y VISUALIZACIÓN DE DATOS DE SENSORES DE LLUVIA PARA ESTACIONES METEOROLÓGICAS DISTRIBUIDAS A LO LARGO DEL ARROYO MBURICAO
b. Mecánico

El diseño tiene como objetivo principal albergar el sistema de adquisición de datos y garantizar el posicionamiento óptimo del sensor óptico de lluvia. La estructura se divide en tres partes principales: la caja, la tapa y el soporte del sensor.

El diseño de la caja se basa en la caja de paso con certificación ip65, lo que asegura un grado de protección para la electrónica interna. Sus dimensiones de base son de 310 mm x 210 mm y una profundidad de 110 mm, la parte superior se expande a 314 mm x 214 mm. El cuerpo de la caja integra un reborde perimetral que permite un ajuste por encastre con la tapa, lo que refuerza la hermeticidad del conjunto.


Figura 9: Diseño de Caja

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

La tapa cuenta con un espesor externo de 17 mm, y se fija mediante cuatro puntos de anclaje en las esquinas.


Figura 10: Diseño de Tapa

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

Para el soporte del sensor se ha diseñado una placa de montaje de 100 mm por 80 mm, este integra una inclinación de 15 grados, esta angulación es muy importante para los sensores de lluvia ópticos, ya que facilita el escurrimiento natural del agua sobre la cúpula del mismo, evitando lecturas falsas. La base del soporte presenta un calado circular de radio 39 mm, que coincide exactamente con el diámetro de la base del sensor, además, este se fija mediante dos orificios de 5 mm de diámetro alineados con los puntos de sujeción del sensor.


Figura 11: Diseño de Soporte

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

Proyecto MCT - 2026
SISTEMA DE ADQUISICIÓN Y VISUALIZACIÓN DE DATOS DE SENSORES DE LLUVIA PARA ESTACIONES METEOROLÓGICAS DISTRIBUIDAS A LO LARGO DEL ARROYO MBURICAO
c. Interfaz [OBLIGATORIO PARA PROYECTO 4]

Captura de pantalla de la interfaz de usuario.

Descripciones. Explicar si se aplica algún sistema de control.

### 8. Costos

a. Materiales y herramientas compradas/incremental
Componentes Mfr. | Descripción | Cantidad | Precio (USD) | Precio Total (USD)
SMLD12E3N1WT86 | LED azul SMD 0603 indicador | 1,00 | 0,87 | 0,87
RNAN0603BKE10K 0 | Resistencia 10kΩ 0603 pull-up/pull-down | 8,00 | 0,98 | 7,84
RNAN0603BKE4K7 0 | Resistencia 4.7kΩ 0603 para buses I2C/UART | 9,00 | 0,98 | 8,82
C0603J104K4RACT U | Capacitor cerámico 100nF 0603 | 8,00 | 0,20 | 1,6
RNAN0603BKE120 R | Resistencia 120Ω 0603 terminación CAN/RS485 | 2,00 | 0,98 | 1,96
ESP32-S3-WROOM -1-N16R8 | Módulo WiFi/Bluetooth MCU principal 16MB Flash | 1,00 | 6,71 | 6,71
C0805J224K5RACT U | Capacitor electrolítico 22µF 0805 filtrado de alimentación | 2,00 | 0,34 | 0,68
282856-2 | Bornera tornillo 2 pines 5.0mm conexión externa | 3,00 | 1,38 | 4,14
SMLD12E3N1WT86 | LED rojo SMD 0603 indicador estado | 1,00 | 0,69 | 0,69
SP3485EN-L/TR | Transceptor RS-485/RS-422 3.3V SOIC-8 | 2,00 | 0,80 | 1,6
SM712-02HTG | Diodo protección TVS para RS-485 7V/12V | 2,00 | 0,64 | 1,28
SMLD12E3N1WT86 | LED verde SMD 0603 indicador | 1,00 | 0,69 | 0,69

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

Proyecto MCT - 2026
SISTEMA DE ADQUISICIÓN Y VISUALIZACIÓN DE DATOS DE SENSORES DE LLUVIA PARA ESTACIONES METEOROLÓGICAS DISTRIBUIDAS A LO LARGO DEL ARROYO MBURICAO
| alimentación/estado
KMR223G LFG | Pulsador táctil SMD reset del sistema | 1,00 | 0,80 | 0,8
282856-4 | Bornera tornillo 4 pines 5.0mm alimentación/sensores | 1,00 | 2,58 | 2,58
KMR223G LFG | Pulsador táctil SMD modo bootloader/programación | 1,00 | 0,80 | 0,8
USB4930-00-A | Conector USB-C 2.0 16 pines alimentación/datos | 1,00 | 0,51 | 0,51
VS-MBRA140TRPB F | Diodo Schottky 1A 40V SMA protección polaridad | 1,00 | 0,24 | 0,24
104031-0811 | Slot tarjeta microSD con detección almacenamiento | 1,00 | 2,04 | 2,04
RNAN0603BKE5K1 0 | Resistencia 5.1kΩ 0603 para USB-C CC1/CC2 | 2,00 | 0,98 | 1,96
C0805X106K9RAC TU | Capacitor electrolítico 10µF 0805 filtrado bulk | 3,00 | 0,88 | 2,64
C0603X105J4RAC7 411 | Capacitor cerámico 1µF 0603 filtrado de señal | 1,00 | 0,49 | 0,49
RNAN0603BKE1K0 0 | Resistencia 1kΩ 0603 limitación corriente LED | 3,00 | 0,98 | 2,94
SMTU2032-C.TR | Soporte batería CR2032 SMT para RTC backup | 1,00 | 1,87 | 1,87
1N4148WQ-7-F | Diodo conmutación rápida SOD-123 protección | 1,00 | 0,13 | 0,13
DS3231M+ | RTC (reloj tiempo real) I2C alta precisión ±5ppm | 1,00 | 13,60 | 13,6
LDL1117S33R | Regulador LDO 3.3V SOT-223 alimentación del sistema | 1,00 | 0,74 | 0,74
TOTAL | | | | 68,22

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

Proyecto MCT - 2026
SISTEMA DE ADQUISICIÓN Y VISUALIZACIÓN DE DATOS DE SENSORES DE LLUVIA PARA ESTACIONES METEOROLÓGICAS DISTRIBUIDAS A LO LARGO DEL ARROYO MBURICAO
b. Materiales y herramientas prestadas/existentes
Componente | Descripción | Cantidad
Sensor óptico de lluvia RS485 | Sensor infrarrojo de pulso con salida RS485, resolución 0,1 mm, doble canal, alimentación 5-12V DC | 1
Módulo GSM / DTU GPRS | Unidad terminal de datos RS232/485 a GPRS con antena GSM externa, alimentación 12V | 1
Pin headers | Espadín 1x02 pines, paso 1.00mm, vertical | 1
Pin headers | Espadín 1x10 pines, paso 1.00mm, vertical | 1

### 9. Resultados parciales y finales

Procedimiento de montaje y horneado de la PCB

1. Se realiza la revisión y etiquetado de componentes a ser colocados en la placa. De esta manera se tienen las resistencias, capacitores, diodos, etc., ordenados y de acuerdo a los nombres asignados en la serigrafía, facilitando la colocación y evitando errores.
2. Una vez terminada la revisión y etiquetado, se procede a colocar la placa sobre una mesa y fijando alrededor de la misma otras tres placas que servirán de soporte fijo a la que se utilizará. Utilizando cinta de papel, se aseguran las placas de soporte a la mesa.
3. Ya colocadas las placas, se limpia con el alcohol isopropílico la superficie de la placa para eliminar suciedad e impurezas, para que el proceso sea uniforme. También se limpia el stencil con el mismo alcohol, ya colocada sobre la placa. Se fija a la misma.
4. Luego se coloca la solder paste Sn63Pb37 que viene en pote sobre la superficie del stencil y se procede a distribuir la pasta sobre la misma con una espátula de metal bajo un ángulo aproximado de 45° con la horizontal, de manera que la pasta ingrese a las cavidades del stencil justo sobre las pistas a soldar.
5. Una vez terminada la colocación de la pasta sobre la superficie, se retira el stencil y se realiza una inspección visual de las pistas (huellas) expuestas; en nuestro caso se utilizó un microscopio para la verificación de las huellas con la pasta sobre la misma.
6. Luego se colocan los componentes sobre las huellas, empezando por las más pequeñas, las resistencias, capacitores, diodos y luego el resto de los componentes a soldar.

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

Proyecto MCT - 2026
SISTEMA DE ADQUISICIÓN Y VISUALIZACIÓN DE DATOS DE SENSORES DE LLUVIA PARA ESTACIONES METEOROLÓGICAS DISTRIBUIDAS A LO LARGO DEL ARROYO MBURICAO
7. Una vez terminada la colocación de los componentes, se verifica que estos estén bien colocados y se procede a precalentar el horno.
8. Se realiza una lectura del manual del horno T962C infrarrojo, luego se sigue el procedimiento del mismo, apretando la tecla “s” para acceder al menú, luego “F4” para seleccionar el idioma inglés. A continuación, se aprieta la tecla “F3” para acceder a los perfiles de temperatura del dispositivo; en nuestro caso se utiliza el perfil de “wave 2” para Sn63Pb37 y luego se procede al precalentamiento. En la pantalla del dispositivo se observa la evolución de la temperatura vs. el tiempo y el perfil deseado.
9. Luego se colocan las placas dentro del horno y se repite el proceso del punto 8 para el calentamiento y soldado de las placas. Aproximadamente a los 10 minutos ya se completa el proceso de soldado y se retiran del horno las placas.
10. Se vuelve a verificar con el microscopio si existen cortos entre las huellas o si no se han soldado correctamente; luego de esta inspección se realizan correcciones de ser necesarias; en nuestro caso, a simple vista no se constataron huellas mal soldadas ni cortos entre las mismas, por lo que se da por terminado el proceso.

A continuación, algunas imágenes del proceso.

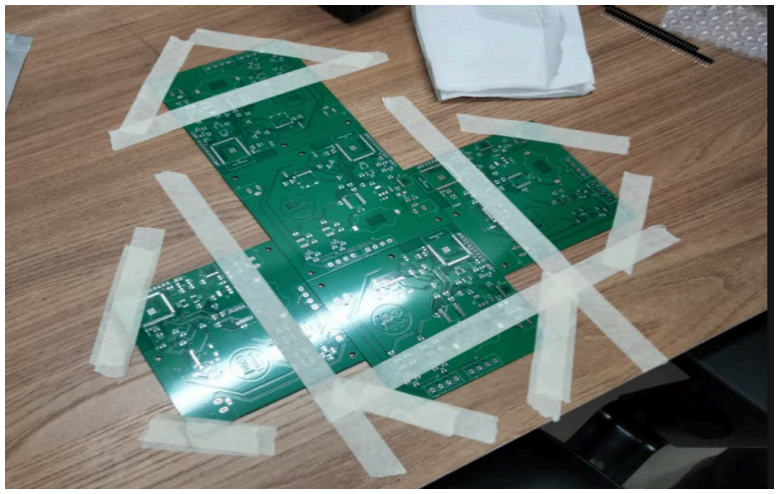
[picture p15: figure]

Figura 12. Colocación de placas.

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

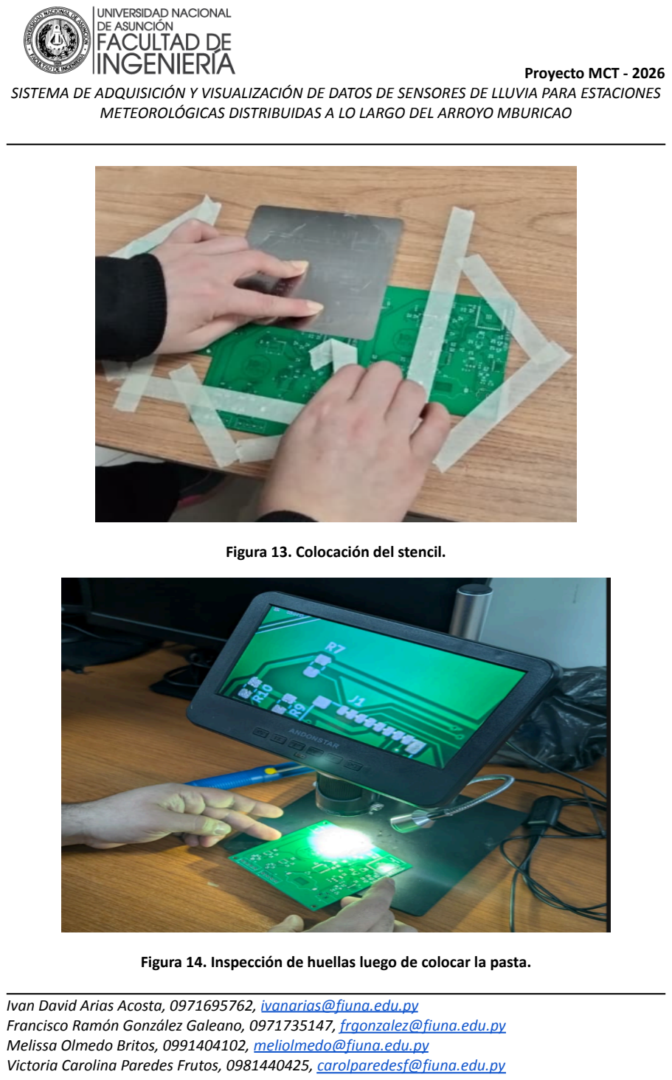
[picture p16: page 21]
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

Figura 13. Colocación del stencil.

Figura 14. Inspección de huellas luego de colocar la pasta.

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

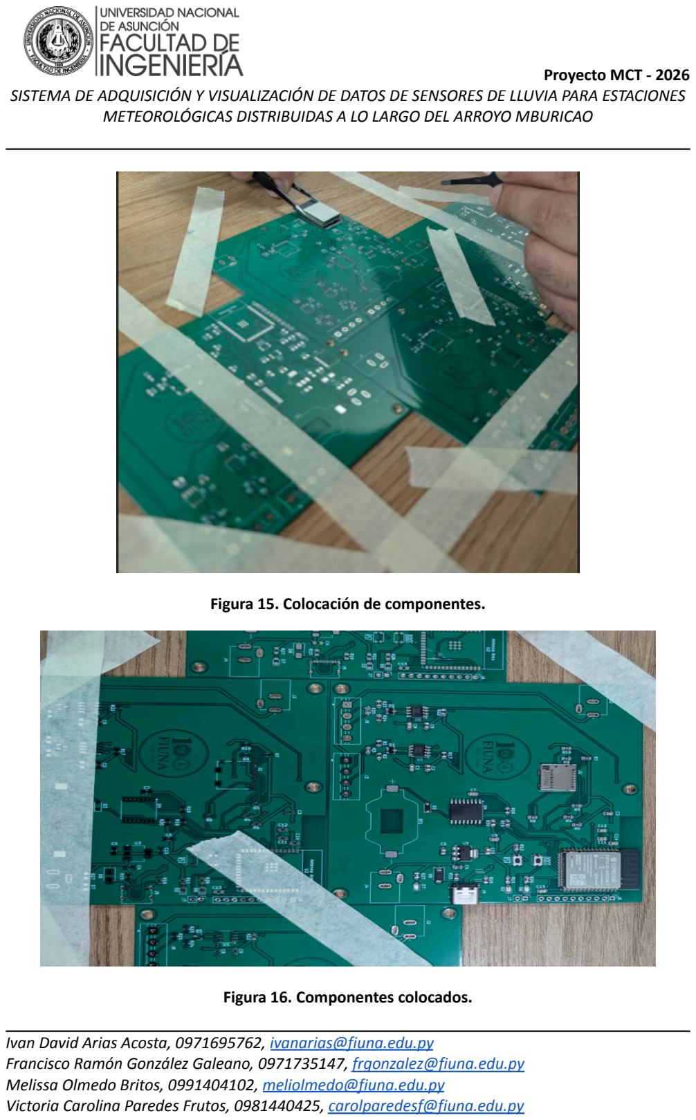
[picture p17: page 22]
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

Figura 15. Colocación de componentes.

Figura 16. Componentes colocados.

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

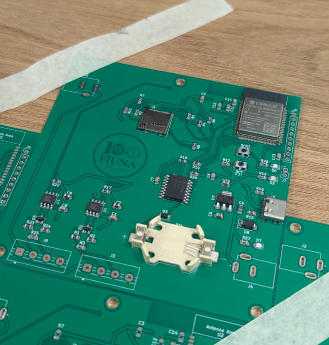
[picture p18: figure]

Figura 17. Placa con componentes a soldar en el T962C.

Pruebas de validación de placa

Con la placa ya totalmente soldada, se realizan pruebas de continuidad, primeramente buscando cortos entre los pines contiguos del ESP32, conector USB-C, IC del RTC, micro-SD holder, ICs del transceiver SP3485EN, líneas de tensión de 5V, 3V3 y GND. Estas pruebas fueron muy satisfactorias, pues no se constataron cortos en la placa.

Luego se procedió a la conexión con la computadora para pruebas de comunicación vía USB. Estas resultaron exitosas, validando así el par diferencial diseñado para el funcionamiento correcto de comunicación vía USB, así como el de la alimentación de 5V, 3V3. Se procede a programar la placa con un código debug de encendido de la LED conectada al GPIO21 de la ESP32, teniendo así tres LEDs conectadas en la placa: 5V, 3V3 y debug, como se observa en la figura 18.

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

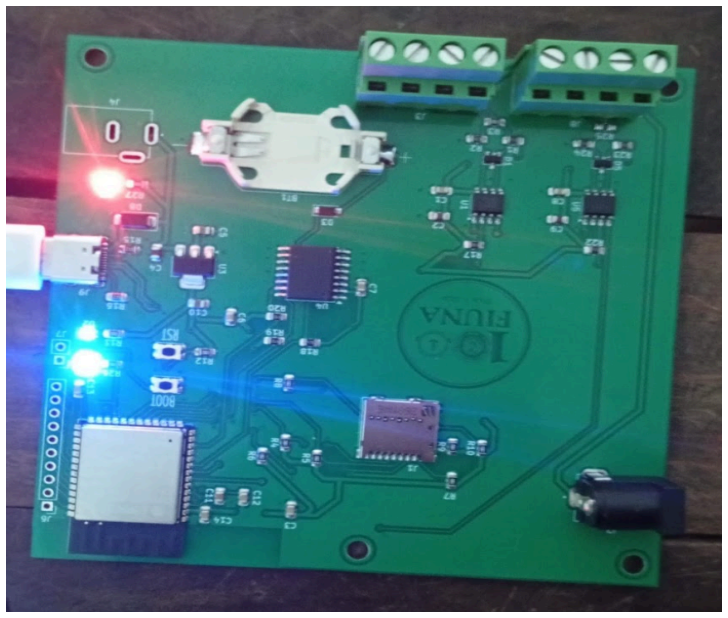
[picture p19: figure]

Figura 18. Prueba debug.

Programación

Con la placa ya probada y totalmente funcional, se procede a la parte de programación de la misma para la tarea de la estación.

Librerías y componentes de software utilizados

El firmware fue desarrollado íntegramente sobre el framework ESP-IDF v6.1 de Espressif Systems, utilizando el lenguaje C estándar con soporte de FreeRTOS para la gestión de tareas en tiempo real. El entorno de desarrollo empleado fue Visual Studio Code con compilación cruzada para la arquitectura del microcontrolador ESP32-S3. No se emplearon librerías de terceros; todos los controladores de hardware fueron implementados como componentes propios del proyecto, siguiendo la arquitectura modular de ESP-IDF.

Los componentes desarrollados son los siguientes:

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

config — Centraliza la definición de pines GPIO y parámetros de comunicación del sistema (baudrates, identificadores de esclavo Modbus, registros de lectura y factores de escala). Actúa como única fuente de verdad para la configuración de hardware.

rtc — Driver para el módulo RTC DS3231M mediante el protocolo I2C. Implementa inicialización del bus, lectura y escritura de fecha/hora en formato BCD, configuración de la salida de onda cuadrada a 1 Hz y lectura de temperatura interna del circuito.

sdcard — Controlador de almacenamiento en tarjeta MicroSD mediante SPI y el sistema de archivos FAT a través de la capa VFS de ESP-IDF. Provee operaciones de creación de archivos con cabecera, escritura de registros en modo append, lectura del primer registro de una cola FIFO y eliminación del mismo mediante reescritura de archivo auxiliar.

modbus_rtu — Implementación manual del protocolo Modbus RTU sobre RS485 half-duplex. Incluye generación y verificación de CRC16, construcción de tramas para las funciones FC03 (lectura de registros holding) y FC06 (escritura de registro único), control del pin DE/RE para conmutación entre transmisión y recepción, y conversión del valor raw a milímetros de lluvia.

dtu — Controlador de comunicación con el módulo DTU (Data Transmission Unit) mediante RS485. Gestiona el envío de payloads al servidor remoto y la recepción de respuestas, con verificación de éxito o error en la respuesta.

Algoritmo desarrollado

Se implementó un pipeline de adquisición, almacenamiento y transmisión de datos que opera en un ciclo continuo con un período de muestreo configurable. El algoritmo central se estructura de la siguiente manera:

Al arranque del sistema, se inicializan secuencialmente todos los periféricos: el RTC para sincronización temporal, la tarjeta MicroSD para almacenamiento persistente, el bus RS485 del sensor de lluvia y el bus RS485 del DTU. Se verifica la existencia de los archivos de registro histórico y cola de pendientes, creándolos con sus respectivas cabeceras en caso de no existir.

Durante la operación continua, el sistema evalúa en cada ciclo de control si se ha cumplido el intervalo de muestreo configurado, comparando el tiempo actual del RTC contra el último slot de medición registrado. Si no corresponde una nueva medición, el sistema verifica si existen

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

mediciones pendientes de envío en la cola FIFO; en caso afirmativo, reintenta el envío al servidor remoto. Si la cola está vacía, el ciclo concluye sin acción adicional.

Cuando se cumple el intervalo de muestreo, el sistema ejecuta la secuencia de medición: lee el registro de lluvia acumulada del sensor mediante Modbus RTU, registra el dato junto con su marca temporal en el archivo de historial local como respaldo permanente, y evalúa si existen envíos pendientes previos. Si la cola de pendientes no está vacía, la nueva medición se encola para preservar el orden cronológico de los datos. De lo contrario, se intenta el envío inmediato al servidor remoto. Ante una falla de comunicación, la medición se almacena en la cola FIFO para su posterior reenvío. Ante un envío exitoso, se reinicia el registro acumulado del sensor mediante escritura Modbus para iniciar un nuevo período de acumulación.

Flujo conceptual del algoritmo final

El flujo conceptual del algoritmo implementado se presenta en la figura adjunta. El diagrama describe el comportamiento lógico del sistema de forma independiente a la tecnología subyacente, mostrando las dos rutas de ejecución principales del bucle de control.

Cuando el intervalo de muestreo no se ha cumplido, el sistema evalúa si existen mediciones pendientes de envío. En caso afirmativo, reintenta el envío y, según el resultado, elimina el registro de la cola o la mantiene intacta para el siguiente ciclo. Cuando el intervalo de muestreo se cumple, el sistema lee el sensor de lluvia, registra la medición localmente como respaldo permanente, y evalúa si existen pendientes previos. De no haberlos, intenta el envío inmediato al servidor remoto; ante éxito reinicia el acumulado, ante falla encola la medición. En ambos casos el sistema retorna al bucle principal para iniciar un nuevo ciclo de control.

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

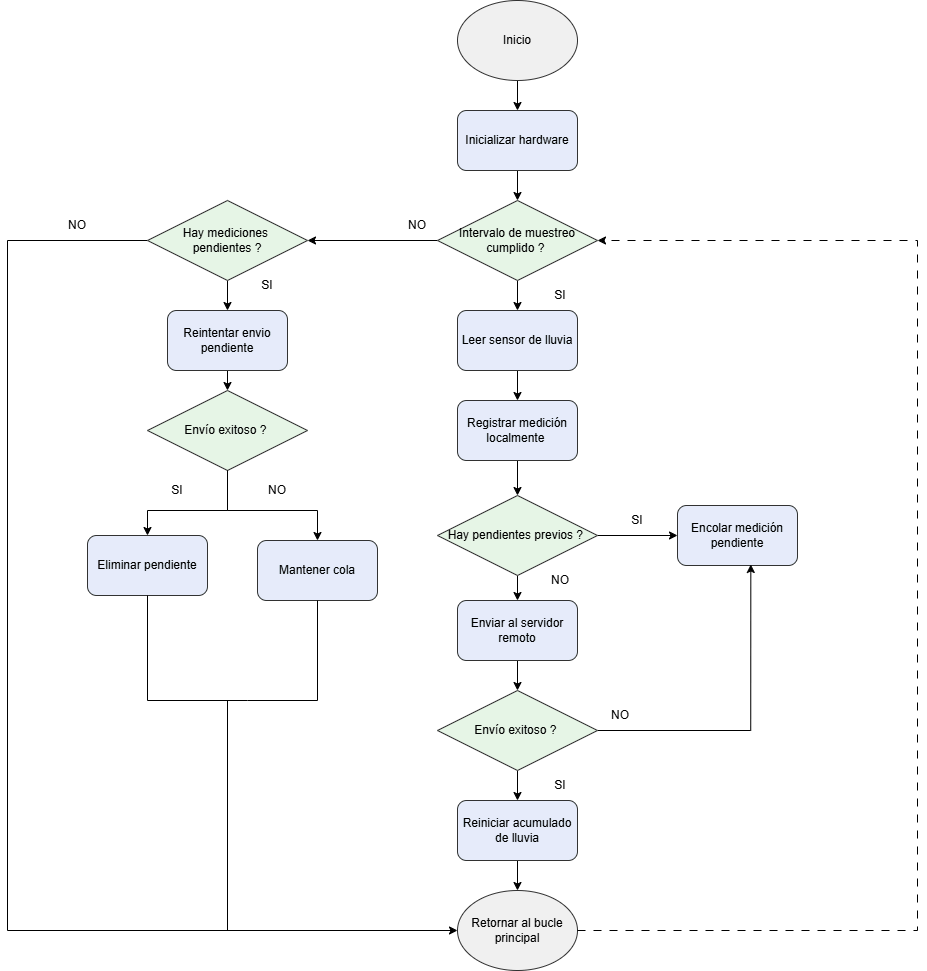
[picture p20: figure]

Figura 19. Diagrama de funcionamiento lógico del sistema.

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

Pruebas de sensores y actuadores

Se realiza la conexión del sensor con la placa para la prueba, como se muestra en la figura 20. Se conecta la salida de alimentación del UPS al conector de entrada de alimentación de los sensores en la placa. Luego se realizan las conexiones de VCC, A, B y GND del sensor a las borneras correspondientes; además, se conecta el osciloscopio para visualizar las señales de salida diferencial de A y B.

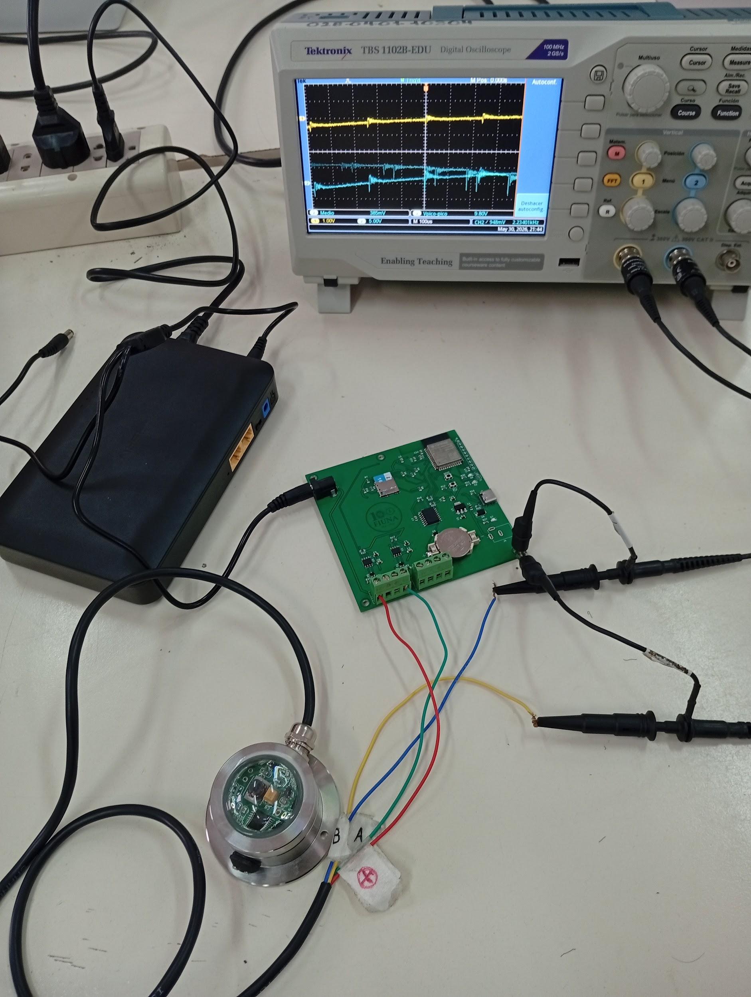
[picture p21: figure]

Figura 20. Conexión del sensor a placa y osciloscopio.

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

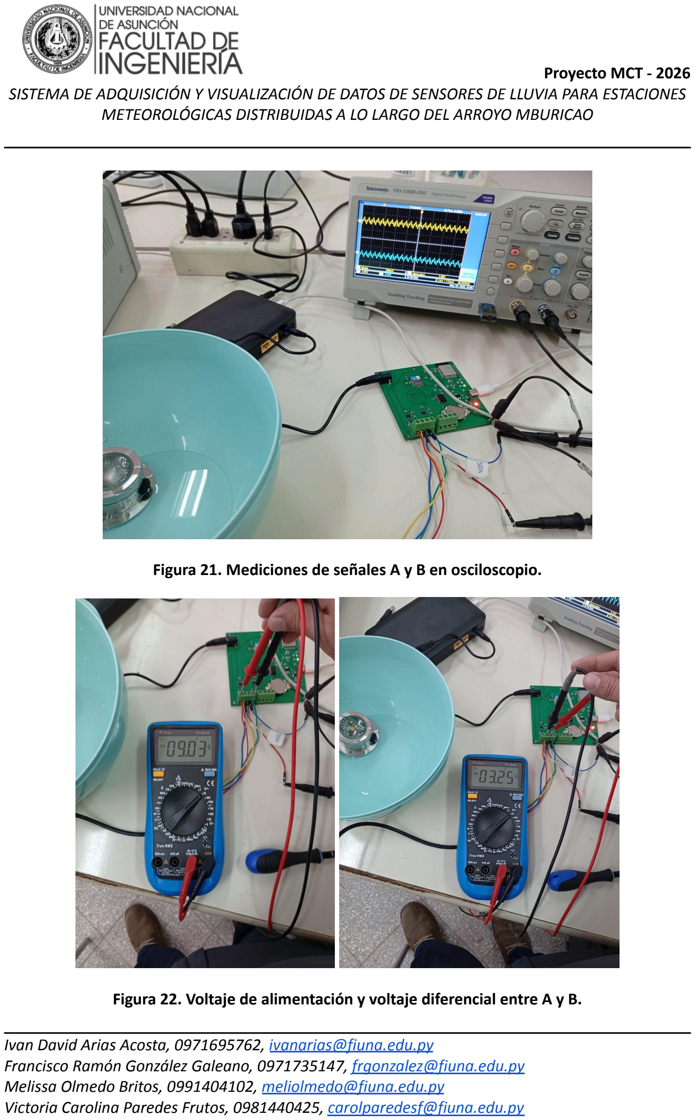
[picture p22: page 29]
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

Figura 21. Mediciones de señales A y B en osciloscopio.

Figura 22. Voltaje de alimentación y voltaje diferencial entre A y B.

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

Interfaz GUI

Dashboard de Monitoreo Hidrometeorológico: Sistema HydroMET Mburicaó

El dashboard de monitoreo presentado forma parte de un proyecto de investigación del Laboratorio de Mecánica y Energía de la FIUNA, a pesar de que para la materia solo se contempla la adquisición de de datos de lluvia el dashboard presentado, cuenta tanto con la visualización de datos de lluvia como de nivel de agua ya que la placa desarrollada funciona para ambos sensores conectados en un mismo bus de campo.

Arquitectura General

El sistema se compone de cinco capas funcionales:

Capa 1 : Campo Estaciones físicas que posteriormente serán instaladas a lo largo de la cuenca del Arroyo Mburicaó. Cada estación cuenta con sensores de nivel de agua y/o precipitación y un módulo de comunicación para la transmisión de datos.

Capa 2: Ingesta Servicio de procesamiento que recibe los datos provenientes de las estaciones, los valida, normaliza y carga en la base de datos centralizada en la nube.

Capa 3: Datos Los datos se almacenan en una base de datos PostgreSQL en la nube, estructurada para gestionar la información de las estaciones, los registros hidrometeorológicos y los archivos multimedia asociados a eventos de campo.

Capa 4: API Capa de servicios que expone los datos almacenados hacia el frontend y recibe datos entrantes desde los dispositivos de campo mediante interfaces REST.

Capa 5: Presentación Dashboard web accesible desde cualquier navegador o dispositivo móvil, que permite la visualización interactiva de los datos hidrometeorológicos en tiempo real mediante gráficos, mapas y tablas.

Tecnologías utilizadas

El frontend del sistema fue desarrollado con Next.js 14 y React, utilizando TailwindCSS para el diseño responsivo de la interfaz. La visualización de datos se implementó con Recharts para los gráficos de series temporales y análisis estadístico, y con Leaflet sobre mapas base de OpenStreetMap para la visualización geoespacial de las estaciones y los límites de la cuenca.

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

La base de datos utilizada es Supabase, una plataforma cloud basada en PostgreSQL que centraliza los registros hidrometeorológicos y el almacenamiento de archivos multimedia. El pipeline de ingesta de datos fue desarrollado en Python 3 con la librería Pandas para el procesamiento y normalización de los archivos CSV provenientes de las estaciones.

Para el despliegue de la aplicación se utilizó Vercel, plataforma de hosting cloud que permite el acceso público al dashboard desde cualquier dispositivo. El código fuente del proyecto se gestiona con Git y GitHub como sistema de control de versiones.

Funcionalidades del dashboard

El dashboard presenta los datos hidrometeorológicos a través de componentes visuales interactivos que incluyen series temporales de nivel y lluvia, gráficos de barras de acumulado diario, análisis de correlación entre variables y comparación entre estaciones. Cuenta con filtros de rango de fechas integrados y tarjetas de indicadores clave que muestran el nivel máximo histórico, el nivel promedio del período y la lluvia máxima registrada. El mapa interactivo permite visualizar la ubicación geográfica de las estaciones sobre la cartografía de la cuenca.

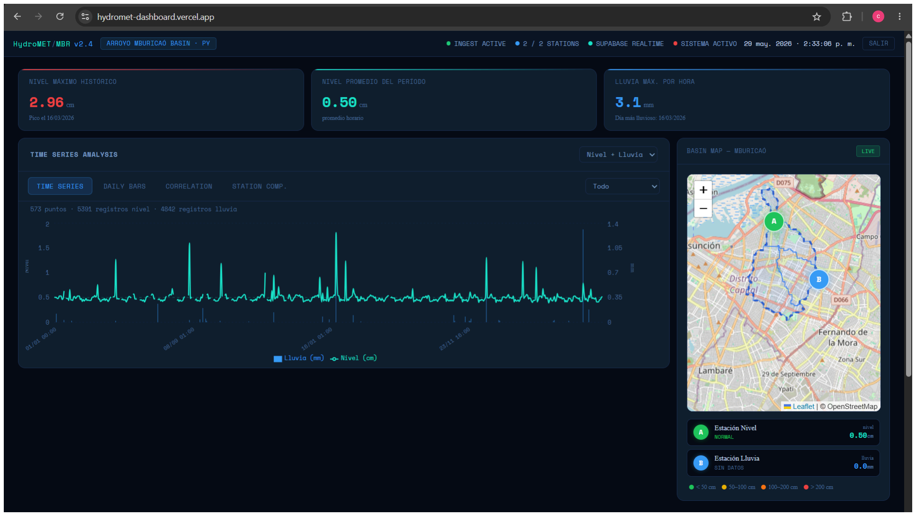
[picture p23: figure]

Figura 23. Dashboard de monitoreo.

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

El dashboard se encuentra disponible públicamente a través del siguiente enlace: https://hydromet-dashboard.vercel.app. El código fuente del proyecto se encuentra disponible en el repositorio de GitHub: https://github.com/carolparedesf/hydromet-dashboard.

Una vez terminado el trabajo se prevé la visualización en tiempo real de los datos, para ello está aún en proceso establecer una conexión segura entre el servidor local y la plataforma en nube.

Parte Mecánica

Para el proceso de montaje y disposición de los componentes del sistema, se contempla el montaje de la placa, la UPS y el módulo GPRS dentro de la caja de paso IP65. Con el fin de optimizar el espacio disponible y previendo el espacio que ocuparán el cableado y la antena del módulo, se diseñó un soporte interno a medida para la placa. Por otro lado, la antena del módulo se colocará en la parte superior de la caja, mientras que el sensor se instalará sobre un soporte externo diseñado específicamente para el mismo.

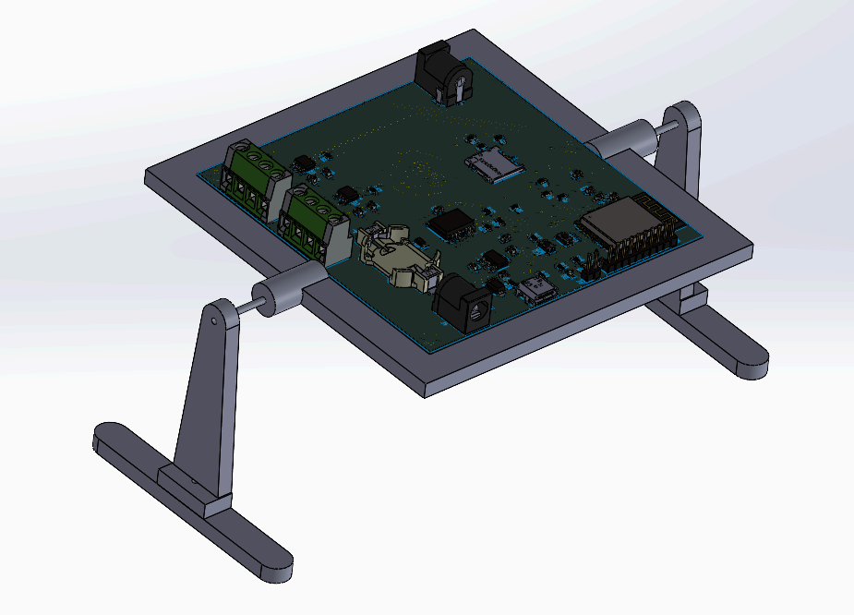
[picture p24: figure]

Figura 23. Diseño de soporte para placa.

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

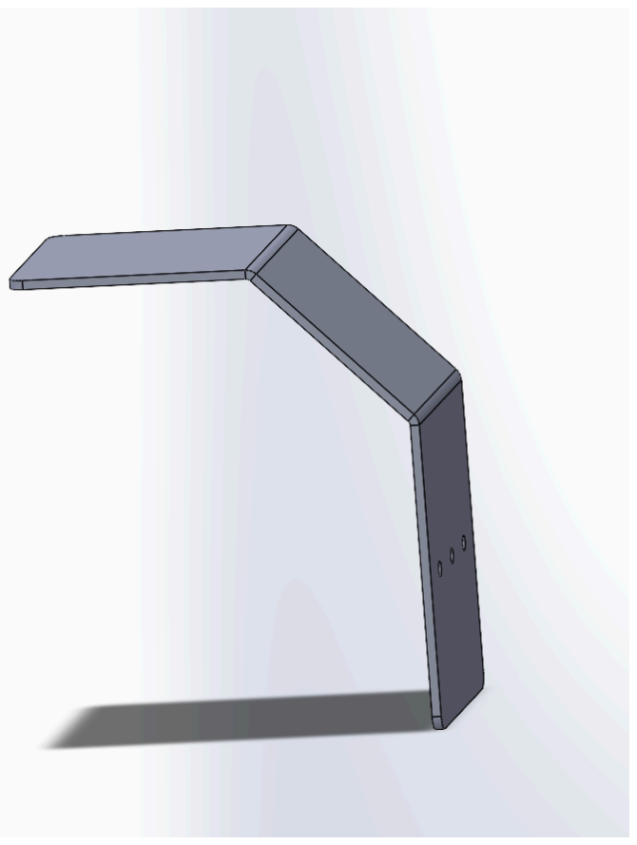
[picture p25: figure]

Figura 24. Diseño de soporte para sensor.

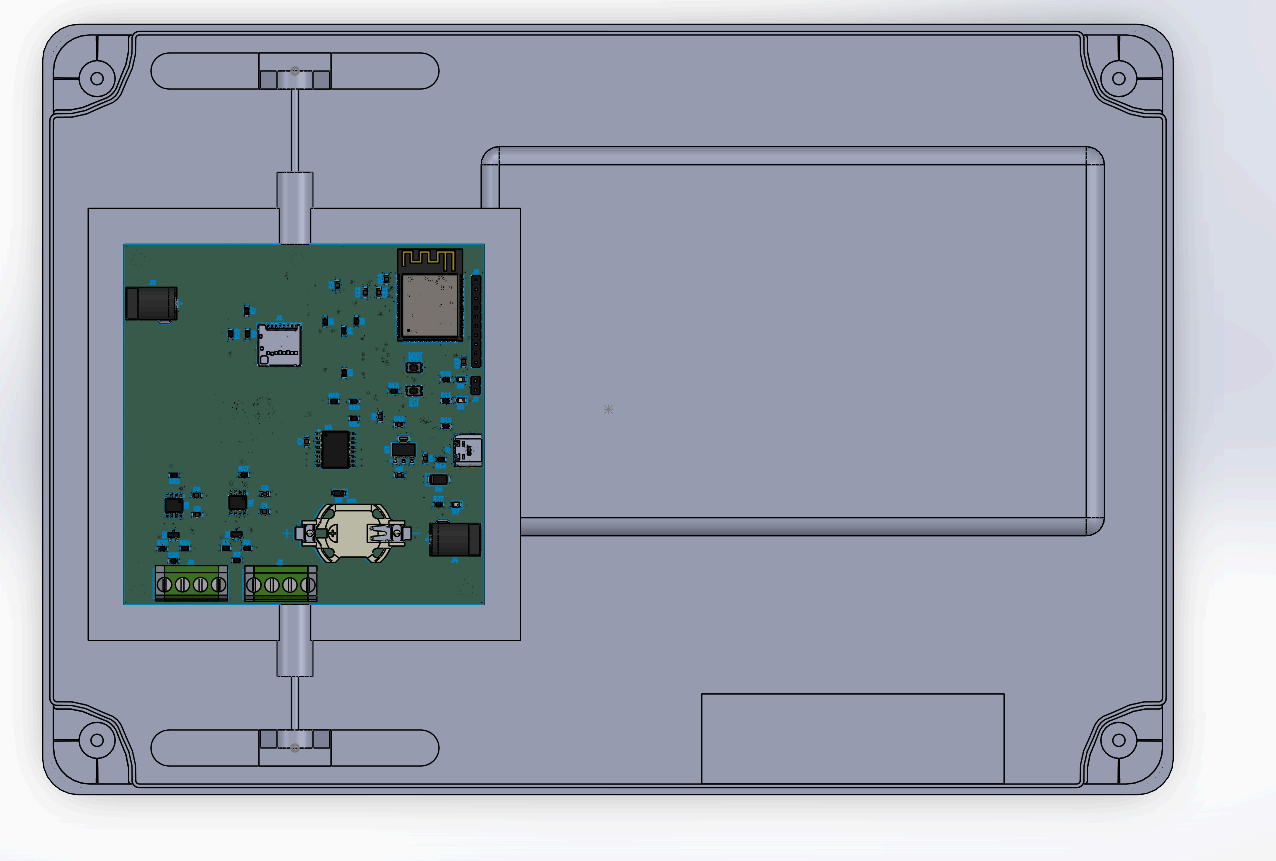
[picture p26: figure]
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

Figura 25. Ensamblaje de la estación.

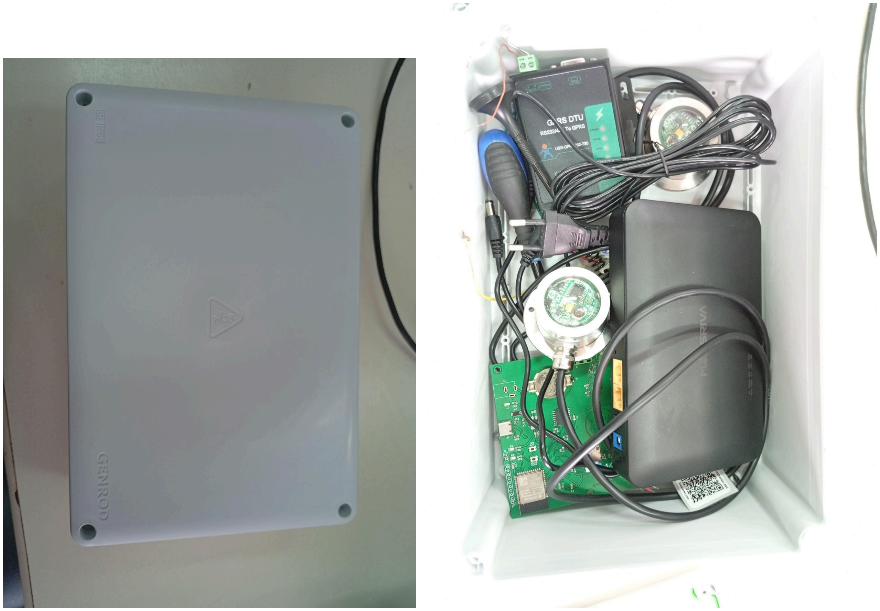
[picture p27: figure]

Figura 26. Caja contenedora.

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

### 10. Conclusiones y recomendaciones finales

El presente trabajo permitió diseñar e implementar una estación de adquisición de datos de precipitación basada en tecnologías IoT para su futura integración dentro de la red de monitoreo hidrometeorológico del Arroyo Mburicaó. El sistema desarrollado integra una placa electrónica propia basada en el microcontrolador ESP32-S3, almacenamiento local mediante tarjeta MicroSD, sincronización temporal mediante RTC, comunicación con sensores industriales con comunicación RS485 y transmisión remota de datos mediante un módulo DTU GPRS.

Los objetivos planteados al inicio del presente trabajo fueron cumplidos satisfactoriamente. Se logró el diseño esquemático y layout de una PCB de dos capas, considerando criterios de integridad de señal, alimentación y manufacturabilidad. Asimismo, se realizó la fabricación, ensamblaje y validación funcional de la placa, verificando el correcto funcionamiento de las líneas de alimentación, comunicación USB para programación y depuración, y la comunicación RS485 utilizada por el sensor de lluvia.

A nivel de software, se desarrolló un firmware modular utilizando ESP-IDF que implementa la adquisición periódica de datos, el almacenamiento persistente, gestiones de cola pendiente y de transmisión remota de la información con un formato compacto. Además, se desarrolló una interfaz web para la visualización de los datos, permitiendo la integración futura de múltiples estaciones distribuidas a lo largo de la cuenca e inclusive en otras locaciones.

Los resultados obtenidos demuestran la viabilidad de la solución para el monitoreo hidrometeorológico distribuido. Si bien aún quedan etapas de validación en campo y ensayos prolongados de funcionamiento, pues las pruebas presentadas corresponden a la validación funcional inicial del sistema. Las pruebas cuantitativas de largo plazo, calibración de sensores y evaluación en condiciones reales de operación no fueron desarrolladas hasta el momento, pero el sistema desarrollado constituye una base sólida para futuras implementaciones destinadas al monitoreo ambiental.

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

Lecciones aprendidas

Durante el desarrollo del proyecto se identificaron diversos aspectos técnicos relevantes. En primer lugar, se comprobó la importancia de considerar desde las etapas iniciales del diseño los requisitos de manufactura de la PCB, especialmente en lo referente al ruteo de señales diferenciales USB, desacoplo de alimentación y distribución de planos de tierra. También se aprendió sobre los procesos de montaje y horneado de la placa PCB, las herramientas y precauciones necesarias para la misma.

Asimismo, se observó que la integración entre hardware y software representa una de las etapas más críticas del desarrollo, requiriendo múltiples iteraciones de prueba para validar la comunicación entre sensores, buses industriales y dispositivos de almacenamiento.

Otro aspecto relevante fue la necesidad de implementar mecanismos de tolerancia a fallos en los sistemas de adquisición remota, debido a que la disponibilidad de la red de comunicación no puede garantizarse permanentemente en entornos de campo. Esto motivó la incorporación de almacenamiento local y mecanismos de retransmisión de datos.

Finalmente, se comprobó que la modularidad tanto del hardware como del firmware facilita significativamente las tareas de depuración, mantenimiento y futuras ampliaciones del sistema.

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

Recomendaciones para futuros desarrollos

Para futuros trabajos, se recomienda realizar campañas de validación en campo durante períodos prolongados y bajo diferentes condiciones climáticas, con el fin de evaluar el comportamiento del sistema en escenarios reales de operación.

Se recomienda además incorporar procedimientos formales de calibración y validación de los sensores mediante comparación con instrumentos de referencia certificados. Esto permitirá cuantificar el error de medición y mejorar la confiabilidad de los datos obtenidos.

Desde el punto de vista del desarrollo electrónico, se recomienda mantener la arquitectura modular implementada en este proyecto, facilitando la incorporación de nuevos sensores ambientales mediante el mismo bus de comunicación RS485. Asimismo, se sugiere documentar exhaustivamente las configuraciones de comunicación, direccionamiento Modbus y procedimientos de mantenimiento para simplificar futuras intervenciones sobre el sistema.

Finalmente, se recomienda continuar el desarrollo de la infraestructura de comunicaciones y de la plataforma web para lograr una integración completa de las estaciones de monitoreo dentro de una red hidrometeorológica distribuida.

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

### 11. Bibliografía

[1] M. Aguilar, H. Velázquez, D. H. Stalder, A. Wehrle, J. Ojeda y L. B. L. Santos, "Machine Learning Models for Water Level Prediction in Rapid Urban Streams: Case of Mburicaó, Asunción, Paraguay," 2025 LI Latin American Computer Conference (CLEI), Valparaíso, Chile, 2025, pp. 1-8, doi: 10.1109/CLEI67442.2025.11420547.
[2] S. C. Santos, R. M. Firmino, D. M. F. Mattos et al., "An IoT rainfall monitoring application based on wireless communication technologies," 2020 IEEE International Conference on
Internet | of | Things | (iThings), | 2020. | doi:
10.1109/iThings-GreenCom-CPSCom-SmartData-Cybermatics50389.2020.9244293.
[3] A. Musarat, H. Ismail et al., "Internet of Things Based Rainfall Monitoring System in Intelligent Agricultural System," International Journal of Scientific and Engineering Studies (IJSES), vol. 6, no. 10, pp. 1–6, 2022.
[4] F. Colli, M. Stagnaro et al., "Advanced Real-Time Monitoring of Rainfall Using IoT Sensor Networks," Sensors, vol. 21, no. 3, p. 1108, 2021. doi: 10.3390/s21031108.
[5] Espressif Systems, ESP32-S3-WROOM-1 / ESP32-S3-WROOM-1U Datasheet, Version 2.6, 2025.
https://documentation.espressif.com/esp32-s3-wroom-1_wroom-1u_datasheet_en.pdf.
[6] | Espressif | Systems, | ESP32-S3-DevKitC-1 | User | Guide.
https://docs.espressif.com/projects/esp-dev-kits/en/latest/esp32s3/esp32-s3-devkitc-1/.
[7] | Espressif | Systems, | ESP32-S3 | Hardware | Design | Guidelines.
https://docs.espressif.com/projects/esp-hardware-design-guidelines/en/latest/esp32s3/.
[8] Peterson, Z., "Routing Differential Pairs in a PCB Layout with Altium Designer," Altium
Resources, | 2018 | (actualizado | en | 2024).
https://resources.altium.com/p/routing-differential-pairs-altium-designer.
[9] Peterson, Z., "Routing Requirements for a USB Interface on a 2-Layer PCB," Altium
Resources, | 2021 | (actualizado | en | 2025).
https://resources.altium.com/p/routing-requirements-usb-20-2-layer-pcb.

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

### 12. Anexos

- Carpeta con fotos y videos de la estación: Anexos (https://drive.google.com/drive/folders/1nY6VeySgnKlgQACuuCmw7uL_CkgnpAoc?usp=sharing)

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

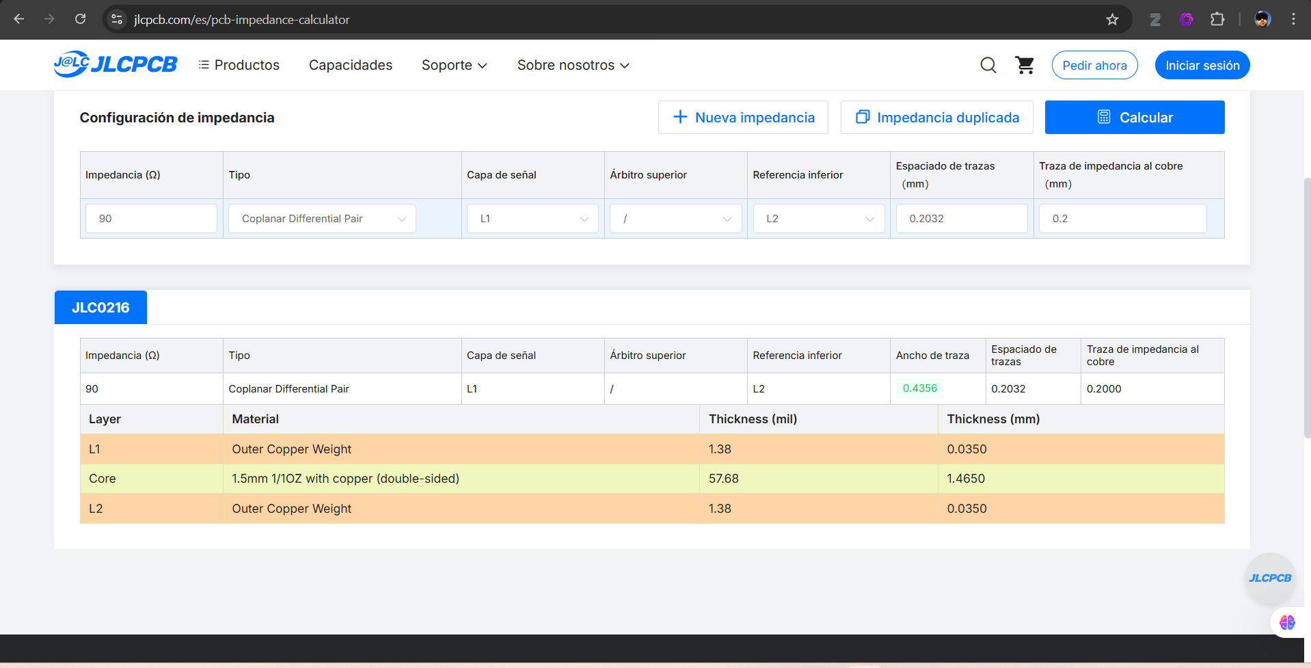
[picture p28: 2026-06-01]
hardware/Estacion_lluviaV4/images/parDiferencial.png

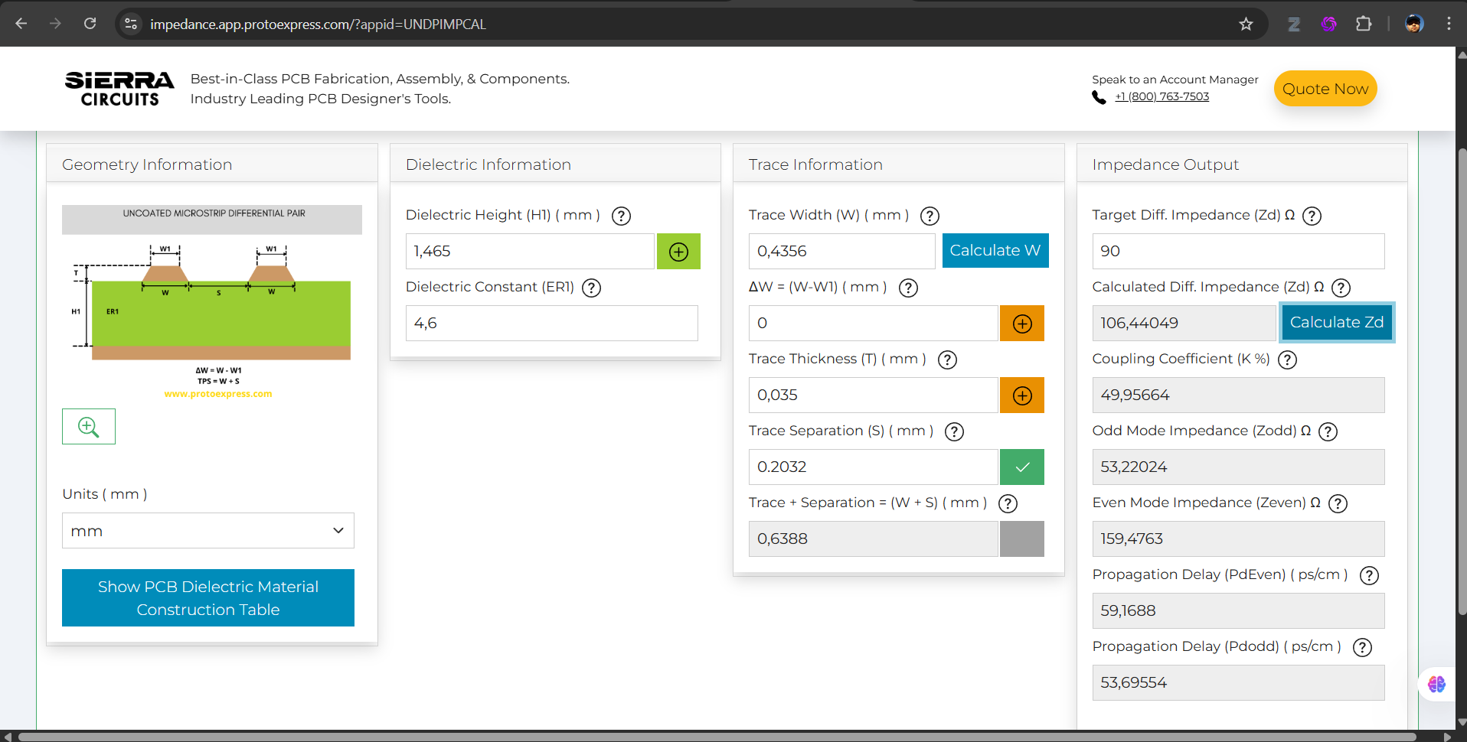
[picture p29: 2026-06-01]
hardware/Estacion_lluviaV4/images/parDiferencial2.png

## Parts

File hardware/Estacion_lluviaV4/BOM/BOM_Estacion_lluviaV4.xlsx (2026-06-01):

Id | Identificador | Identificación | Huella | Cantidad | URL pedido | Mfr. No | Obs
1 | D6 | BLUE | LED_0805_2012Metric_Pad1.15x1.40mm_HandSolder | 1 | https://mou.sr/4caFJC0 | LSM0805463V
2 | R4,R9,R12,R5,R8,R7,R10,R6 | 10k | R_0805_2012Metric_Pad1.20x1.40mm_HandSolder | 8 | https://mou.sr/4bZL6VQ | RE0805FRE1010KL
3 | R23,R19,R17,R22,R20,R18,R24,R1,R2 | 4.7k | R_0805_2012Metric_Pad1.20x1.40mm_HandSolder | 9 | https://mou.sr/3O9f3K0 | AT0805FRE074K7L
4 | C14,C7,C13,C3,C6,C12,C1,C8 | 0.1uF | C_0805_2012Metric_Pad1.18x1.45mm_HandSolder | 8 | https://mou.sr/3O7dfRJ | AS0805KKX7R9BB104
5 | R3,R25 | 0.12k | R_0805_2012Metric_Pad1.20x1.40mm_HandSolder | 2 | https://mou.sr/4vq4YJq | AF0805FR-07120RL | solo r3
6 | U2 | ESP32-S3-WROOM-1 | ESP32-S3-WROOM-1 | 1 | https://mou.sr/4vmADew | ESP32-S3-WROOM-1-N8R8
7 | C5,C10 | 22uF | C_0805_2012Metric_Pad1.18x1.45mm_HandSolder | 2 | https://mou.sr/4t9MpaY | CC0805MKX5R7BB226
8 | J3,J4,J5 | Screw_Terminal_01x02 | TerminalBlock_MaiXu_MX126-5.0-02P_1x02_P5.00mm | 3 | https://mou.sr/4vie9vi | 282856-2
9 | D7 | RED | LED_0805_2012Metric_Pad1.15x1.40mm_HandSolder | 1 | https://mou.sr/4cyCo0N | LSM0805412V
10 | U1,U5 | SP3485EN | SOIC-8_3.9x4.9mm_P1.27mm | 2 | https://mou.sr/4dETco8 | SP3485EN-L/TR
11 | D1,D5 | SM712_SOT23 | SOT-23 | 2 | https://mou.sr/3Q1NYsH | SM712-TP
12 | J7 | Conn_01x02_Pin | PinHeader_1x02_P1.00mm_Vertical | 1 | local | - | proveedor local
13 | D2 | GREEN | LED_0805_2012Metric_Pad1.15x1.40mm_HandSolder | 1 | https://mou.sr/4sqT539 | LSM0805452V
14 | SW1 | RST | SW_Push_1P1T_NO_CK_KMR2 | 1 | https://mou.sr/4srFPeF | KMR223G LFG
15 | J8 | Screw_Terminal_01x04 | TerminalBlock_MaiXu_MX126-5.0-04P_1x04_P5.00mm | 1 | https://mou.sr/3OypUx7 | 282856-4
16 | SW2 | BOOT | SW_Push_1P1T_NO_CK_KMR2 | 1 | https://mou.sr/4srFPeF | KMR223G LFG
17 | J9 | USB_C_Receptacle_USB2.0_16P | USB_C_Receptacle_Palconn_UTC16-G | 1 | https://mou.sr/4vrddFc | USB4930-00-A
18 | D8 | SS14 | D_SMA | 1 | https://mou.sr/4eaQiHI | VS-MBRA140TRPBF
19 | J1 | Micro_SD_Card_Det1 | microSD_HC_Molex_104031-0811 | 1 | https://mou.sr/41WAL70 | 104031-0811
20 | R15,R16 | 5.1k | R_0805_2012Metric_Pad1.20x1.40mm_HandSolder | 2 | https://mou.sr/47RTEvu | RC0805JR-105K1L
21 | C4,C9,C2 | 10uF | C_0805_2012Metric_Pad1.18x1.45mm_HandSolder | 3 | https://mou.sr/4tH0cWg | C0805X106K9RACTU
22 | C11 | 1uF | C_0805_2012Metric_Pad1.18x1.45mm_HandSolder | 1 | https://mou.sr/4t2ahx1 | C0805C105J4RAC7210
23 | R27,R26,R11 | 1k | R_0805_2012Metric_Pad1.20x1.40mm_HandSolder | 3 | https://mou.sr/3O9mlgQ | AC0805FR-131KL
24 | BT1 | SMTU2032-LF | BAT_SMTU2032-LF | 1 | https://mou.sr/4cb3Rpv | SMTU2032-C.TR
25 | D3 | 1N4148 | D_SOD-123 | 1 | https://mou.sr/4dESVBC | 1N4148W-HG3-08
26 | J6 | Conn_01x10_Pin | PinHeader_1x10_P1.00mm_Vertical | 1 | local | - | proveedor local
27 | U4 | DS3231M | SOIC-16W_7.5x10.3mm_P1.27mm | 1 | https://mou.sr/4mnJYPk | DS3231M+TRL
28 | U3 | AMS1117-3.3 | SOT-223-3_TabPin2 | 1 | https://mou.sr/41t8jcS | LDL1117S33R

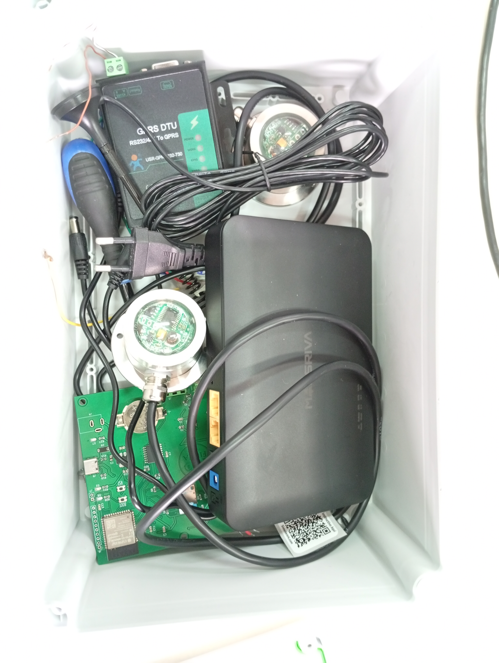
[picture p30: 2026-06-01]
docs/preliminary_results/Componentes_Estacion.jpg

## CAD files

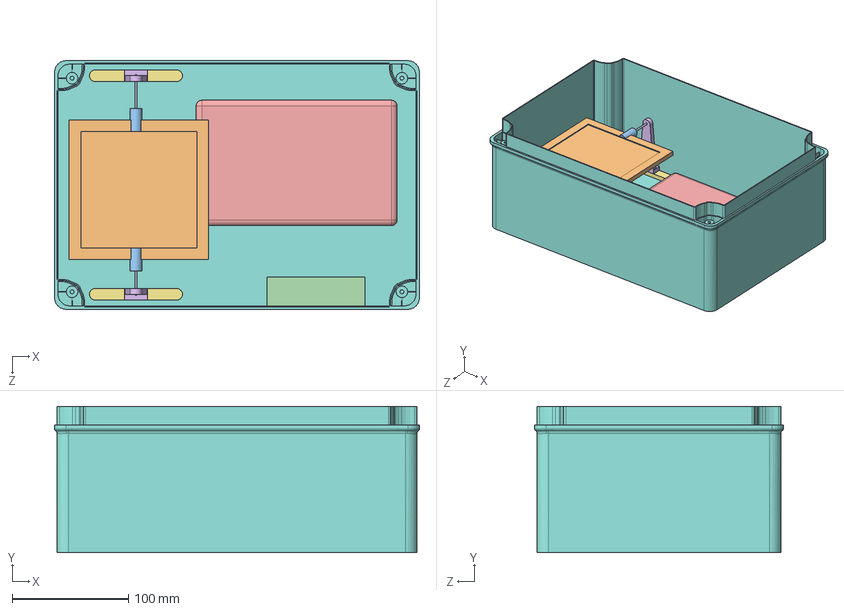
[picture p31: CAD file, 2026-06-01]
mechanical/ensamblaje/Ensamblaje.SLDASM
314.0 x 126.0 x 214.0 mm
Caja_P4
base x 2
soporte_lateral x 2
UPS
modem
Pieza4 x 2
base_placa
tornillo x 2

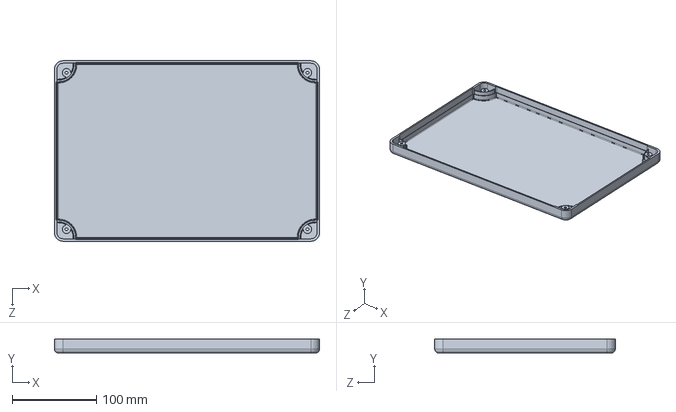
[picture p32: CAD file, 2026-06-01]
mechanical/caja_tapa/Tapa_P4.SLDPRT
314.0 x 17.0 x 214.0 mm

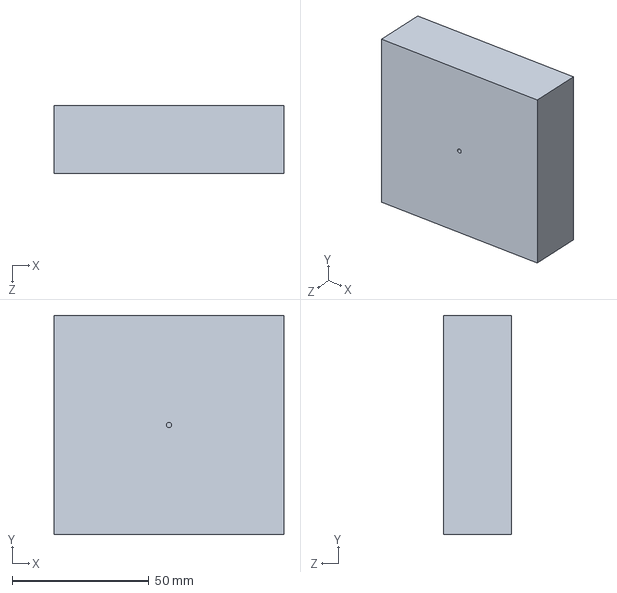
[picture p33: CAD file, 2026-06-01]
mechanical/ensamblaje/modem.SLDPRT
84.0 x 80.0 x 25.0 mm

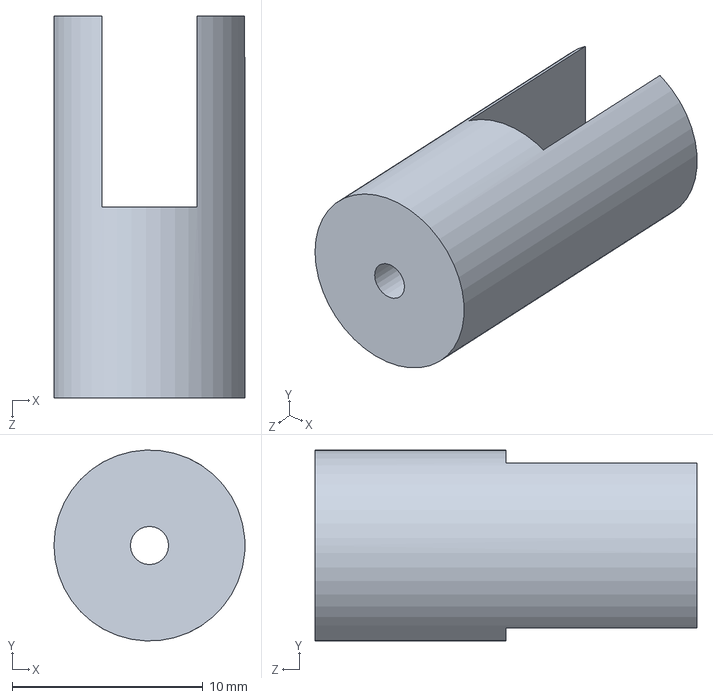
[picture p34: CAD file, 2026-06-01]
mechanical/ensamblaje/PCB holder/Pieza4.SLDPRT
10.0 x 9.99 x 20.0 mm

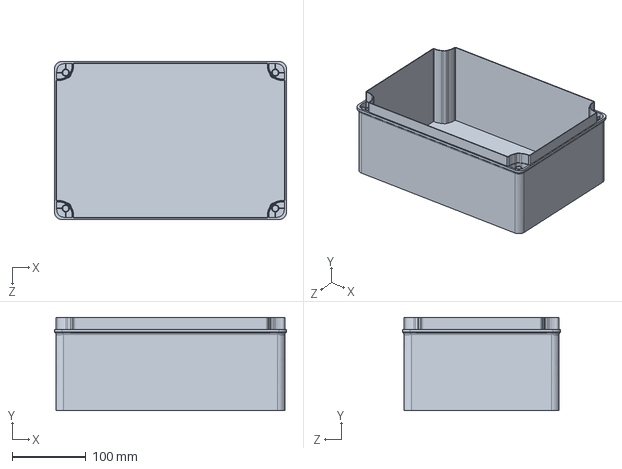
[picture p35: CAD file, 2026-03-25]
mechanical/modeloCaja.SLDPRT
314.0 x 126.0 x 214.0 mm

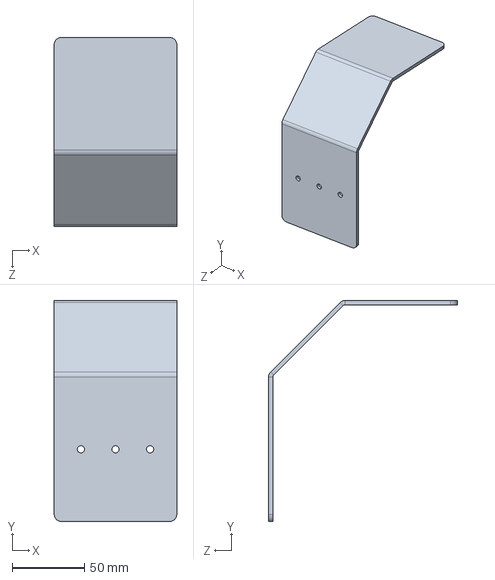
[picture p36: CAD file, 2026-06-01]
mechanical/soporte_sensor/Soporte_Sensor_P4_Actualizado.SLDPRT
85.0 x 153.0 x 131.0 mm

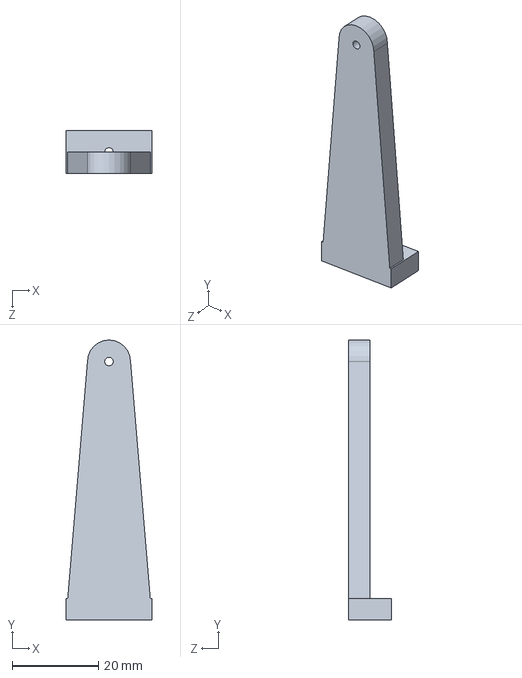
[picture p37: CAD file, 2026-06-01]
mechanical/ensamblaje/PCB holder/soporte_lateral.SLDPRT
20.0 x 65.0 x 10.0 mm

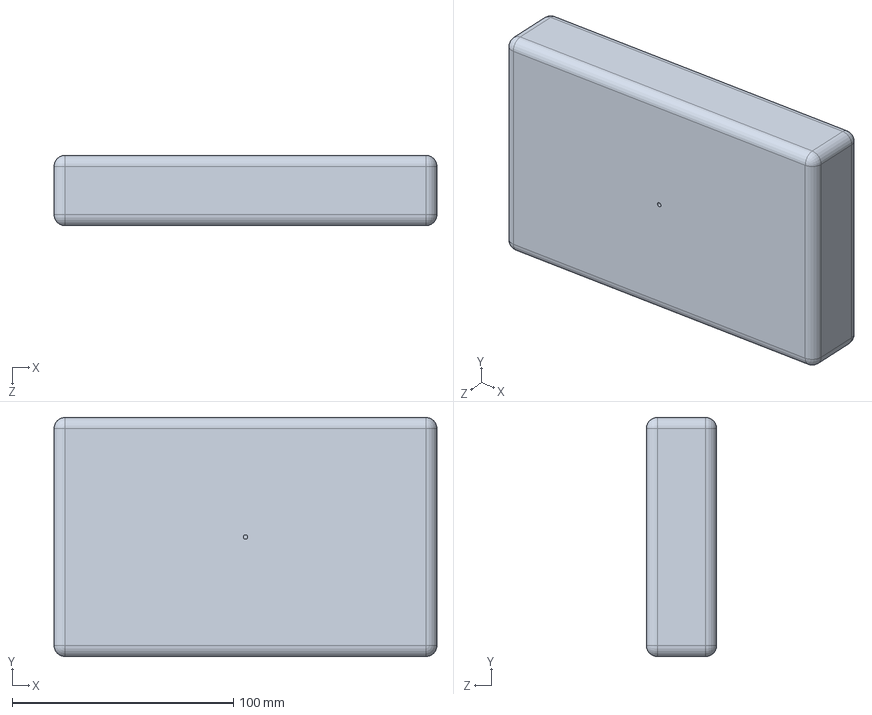
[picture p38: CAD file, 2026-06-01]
mechanical/ensamblaje/UPS.SLDPRT
173.0 x 108.0 x 31.8 mm

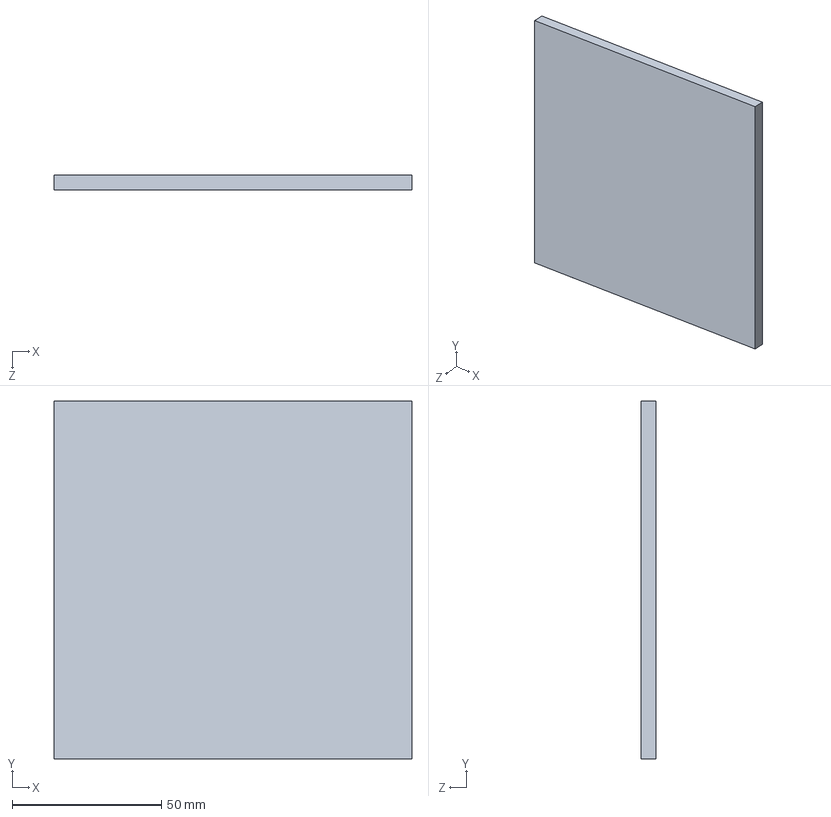
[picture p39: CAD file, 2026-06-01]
mechanical/ensamblaje/PCB holder/base_placa.SLDPRT
120.0 x 120.0 x 5.00 mm

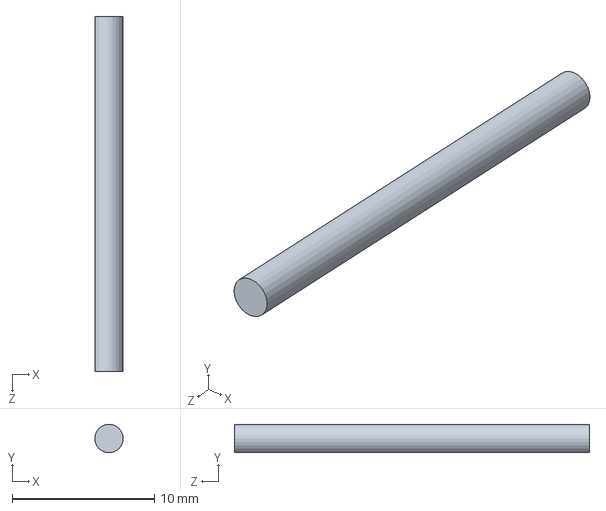
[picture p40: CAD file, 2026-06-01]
mechanical/ensamblaje/PCB holder/tornillo.SLDPRT
2.00 x 2.00 x 25.0 mm

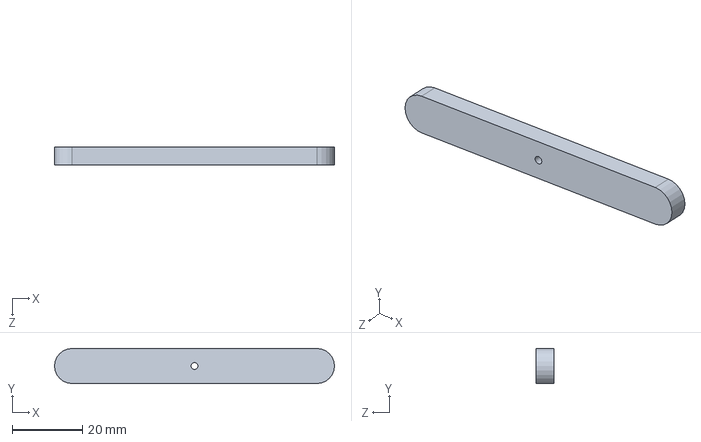
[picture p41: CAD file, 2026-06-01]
mechanical/ensamblaje/PCB holder/base.SLDPRT
80.0 x 10.0 x 5.00 mm

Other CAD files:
mechanical/caja_tapa/Caja_P4.SLDPRT
mechanical/ensamblaje/Caja_P4.SLDPRT

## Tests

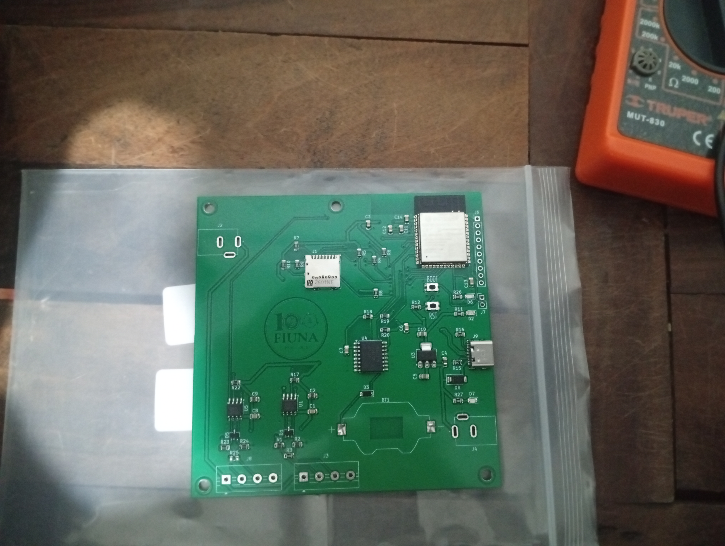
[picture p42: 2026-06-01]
docs/preliminary_results/placa_Estacion_lluvia.jpg

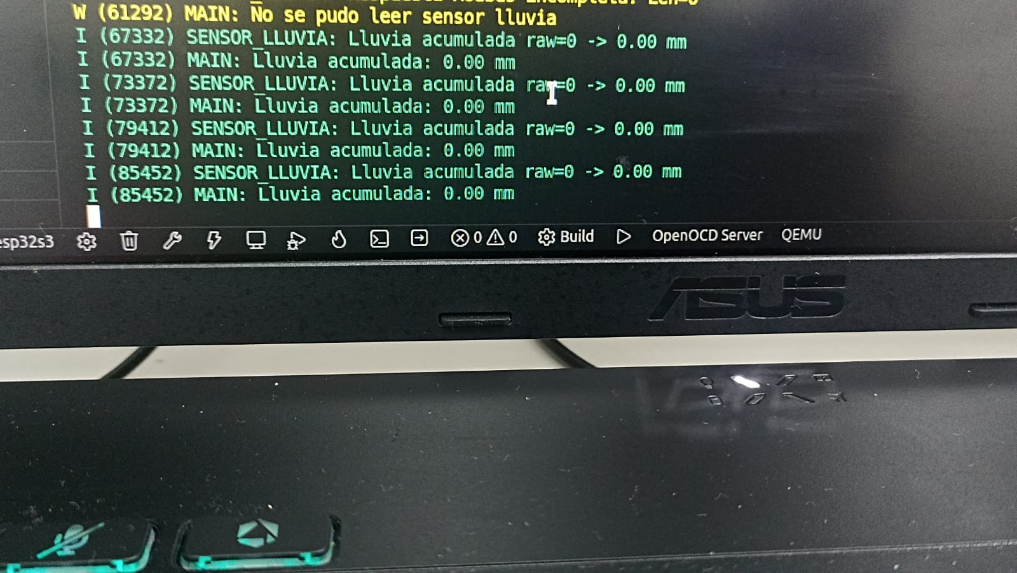
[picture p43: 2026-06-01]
docs/preliminary_results/Prueba_Sensor.jpg

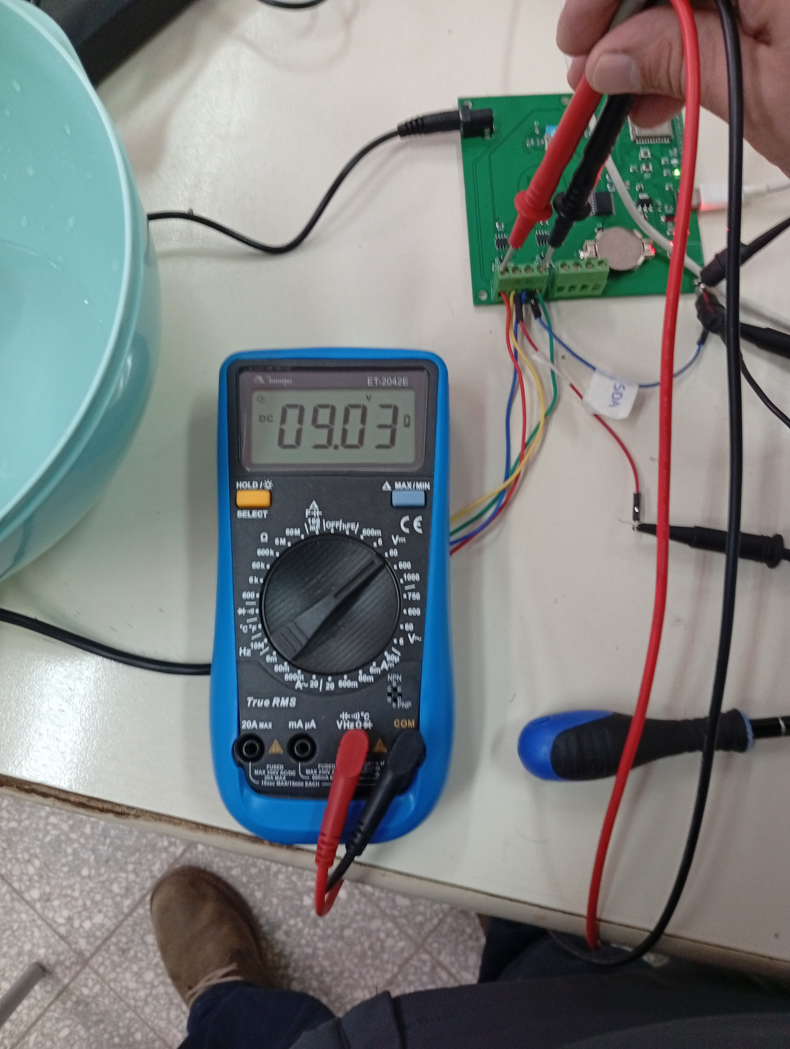
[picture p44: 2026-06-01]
docs/preliminary_results/Voltaje_Alimentacion_sensor.jpg

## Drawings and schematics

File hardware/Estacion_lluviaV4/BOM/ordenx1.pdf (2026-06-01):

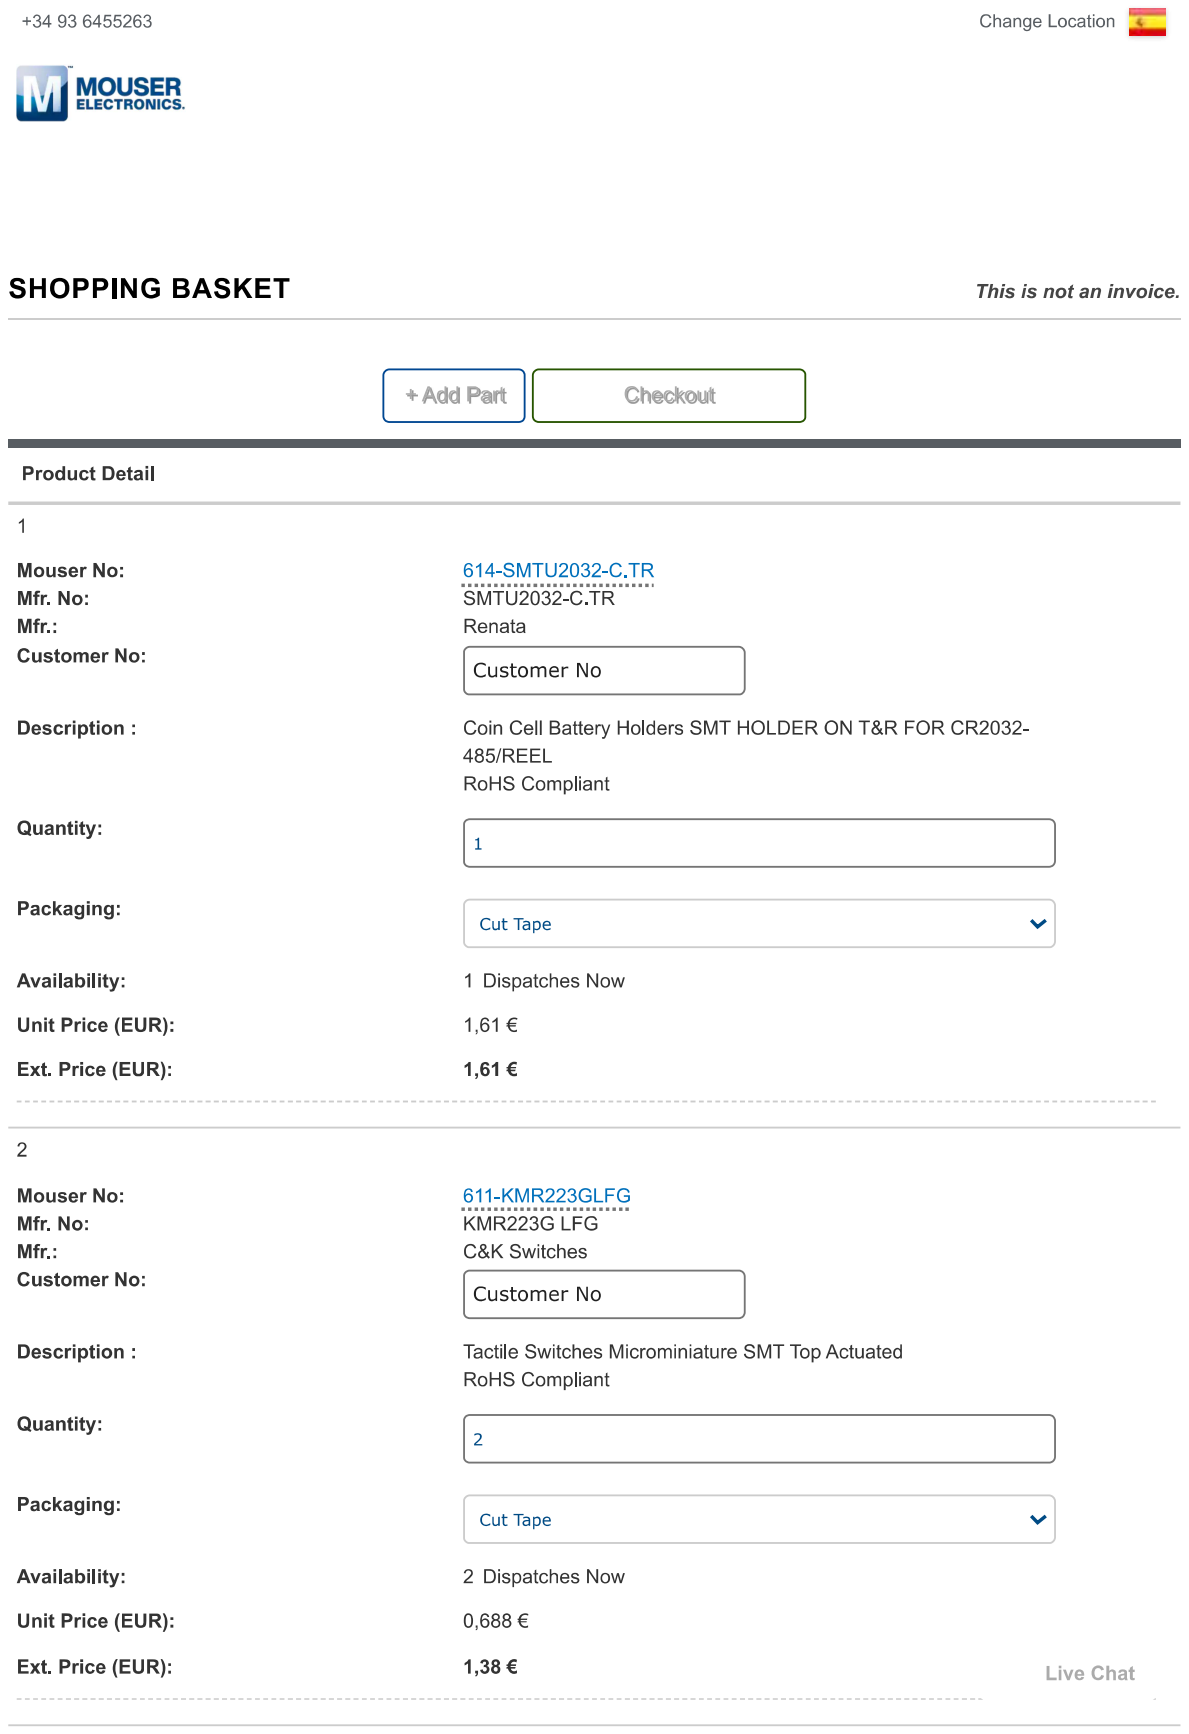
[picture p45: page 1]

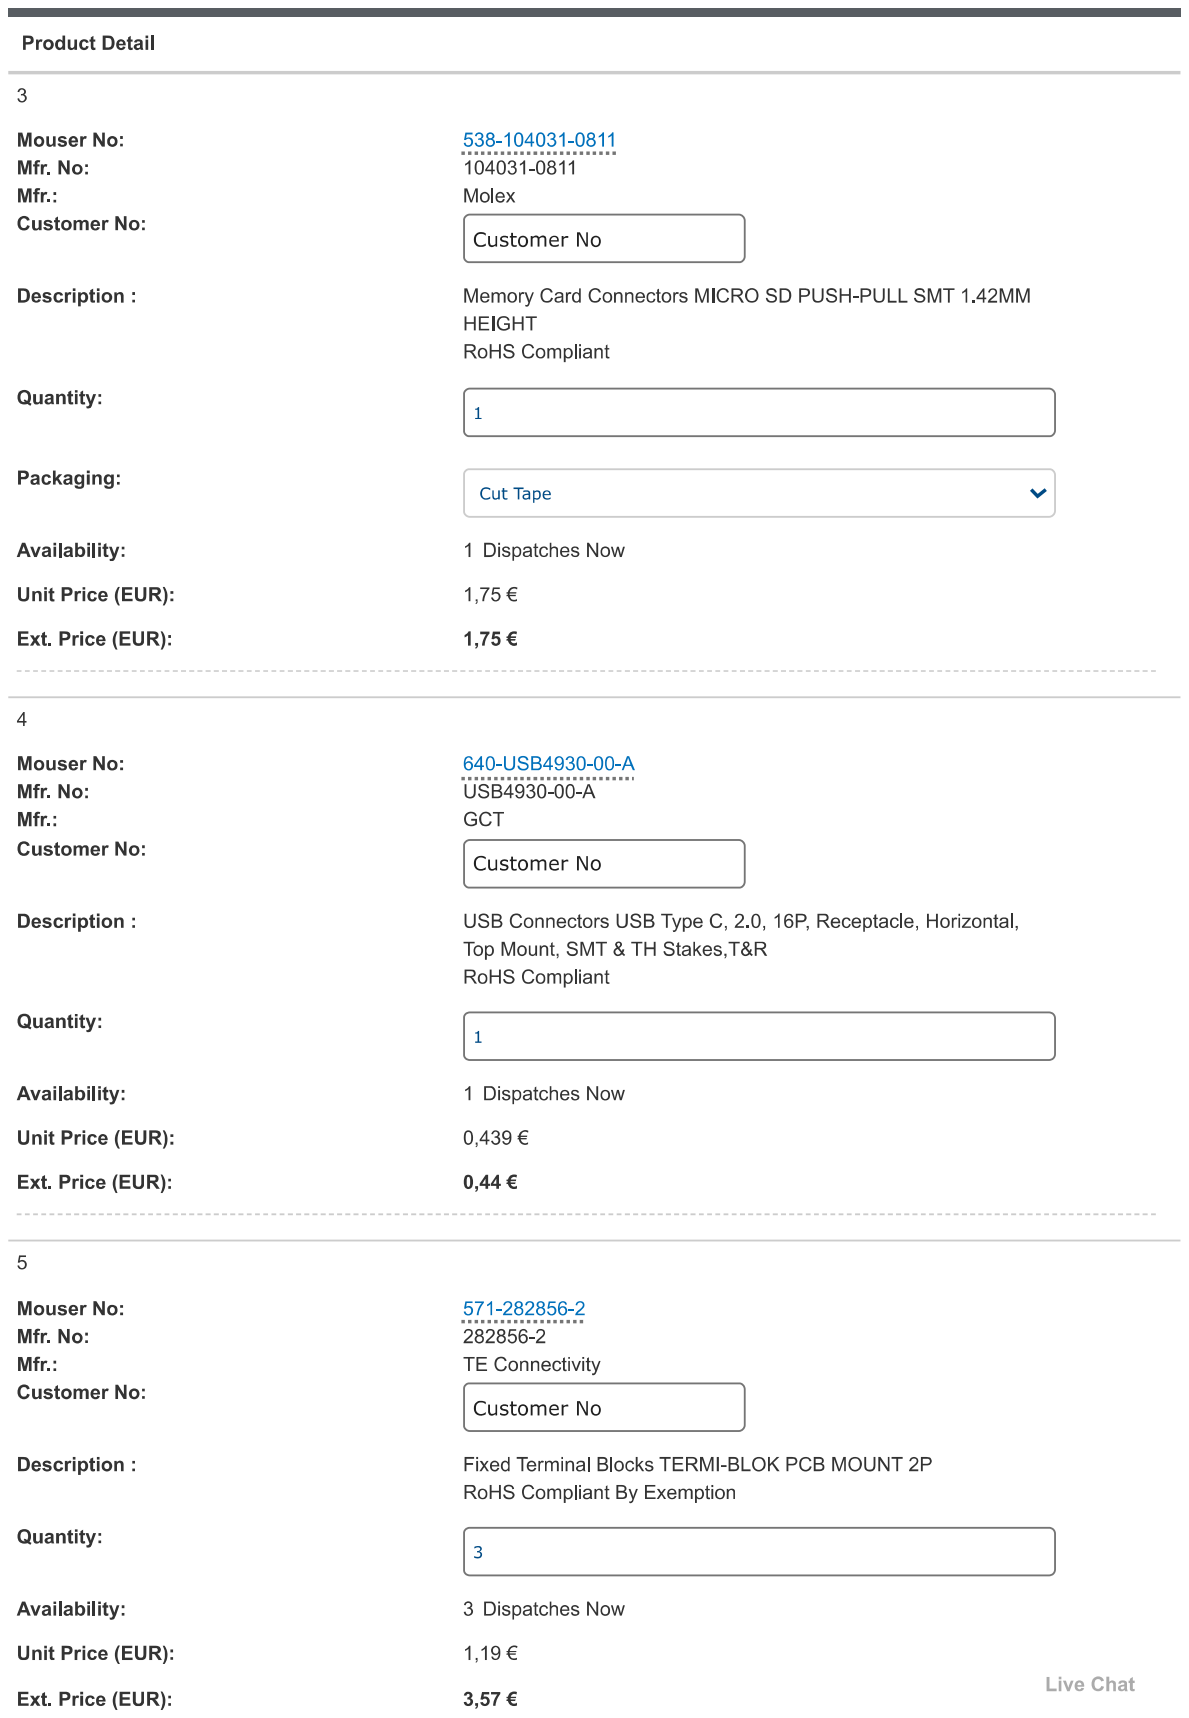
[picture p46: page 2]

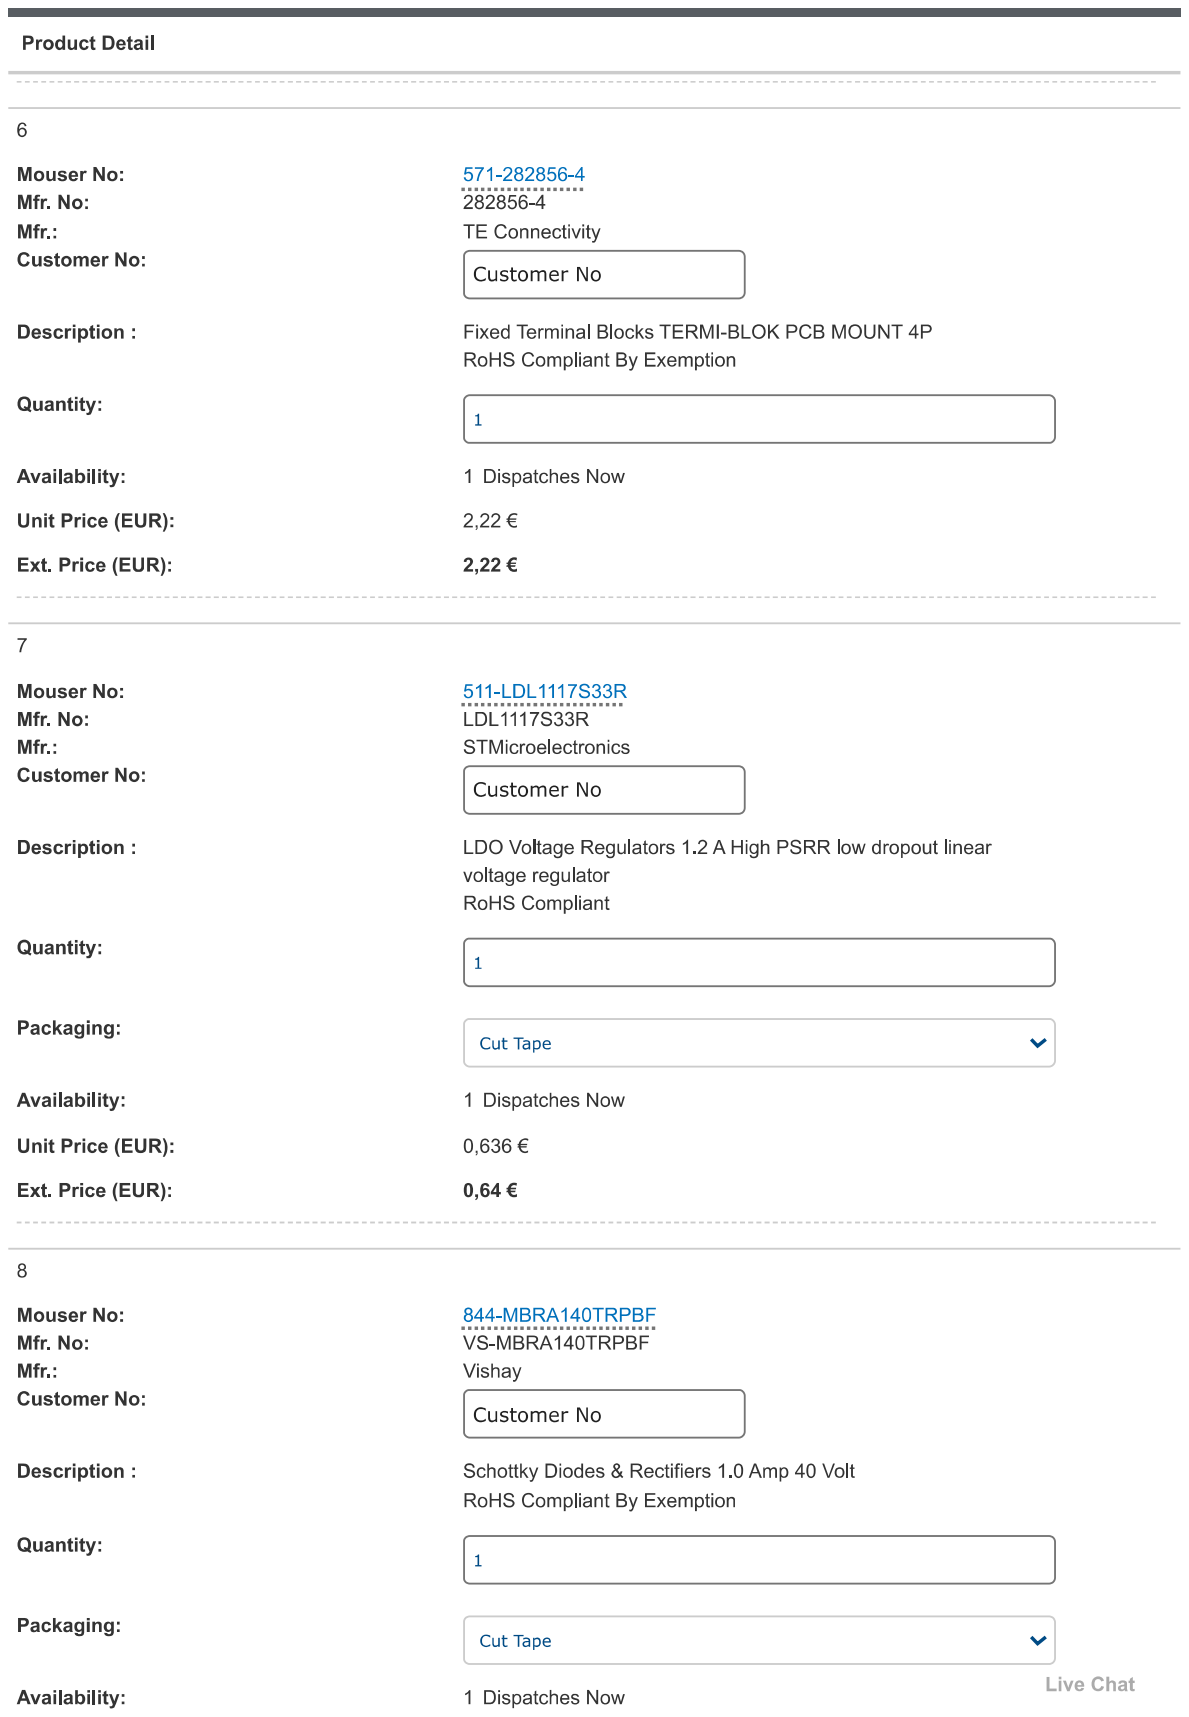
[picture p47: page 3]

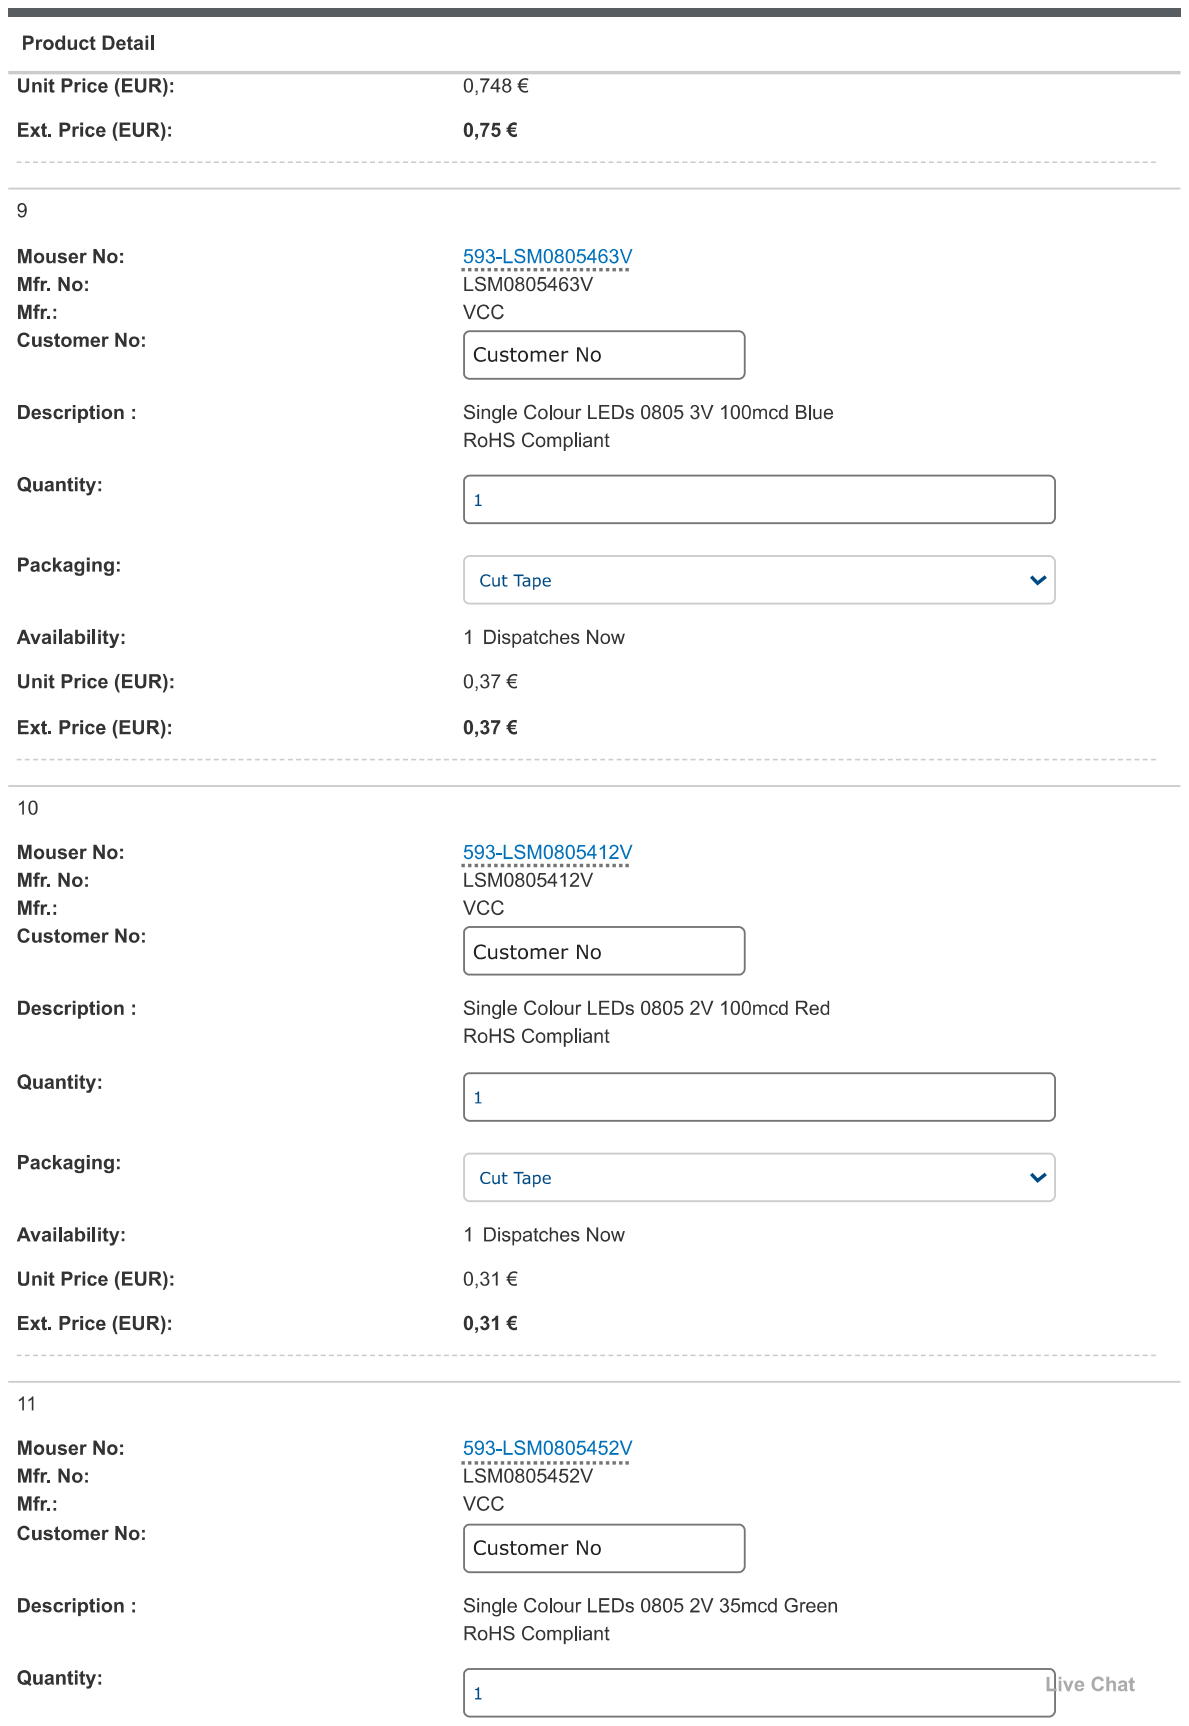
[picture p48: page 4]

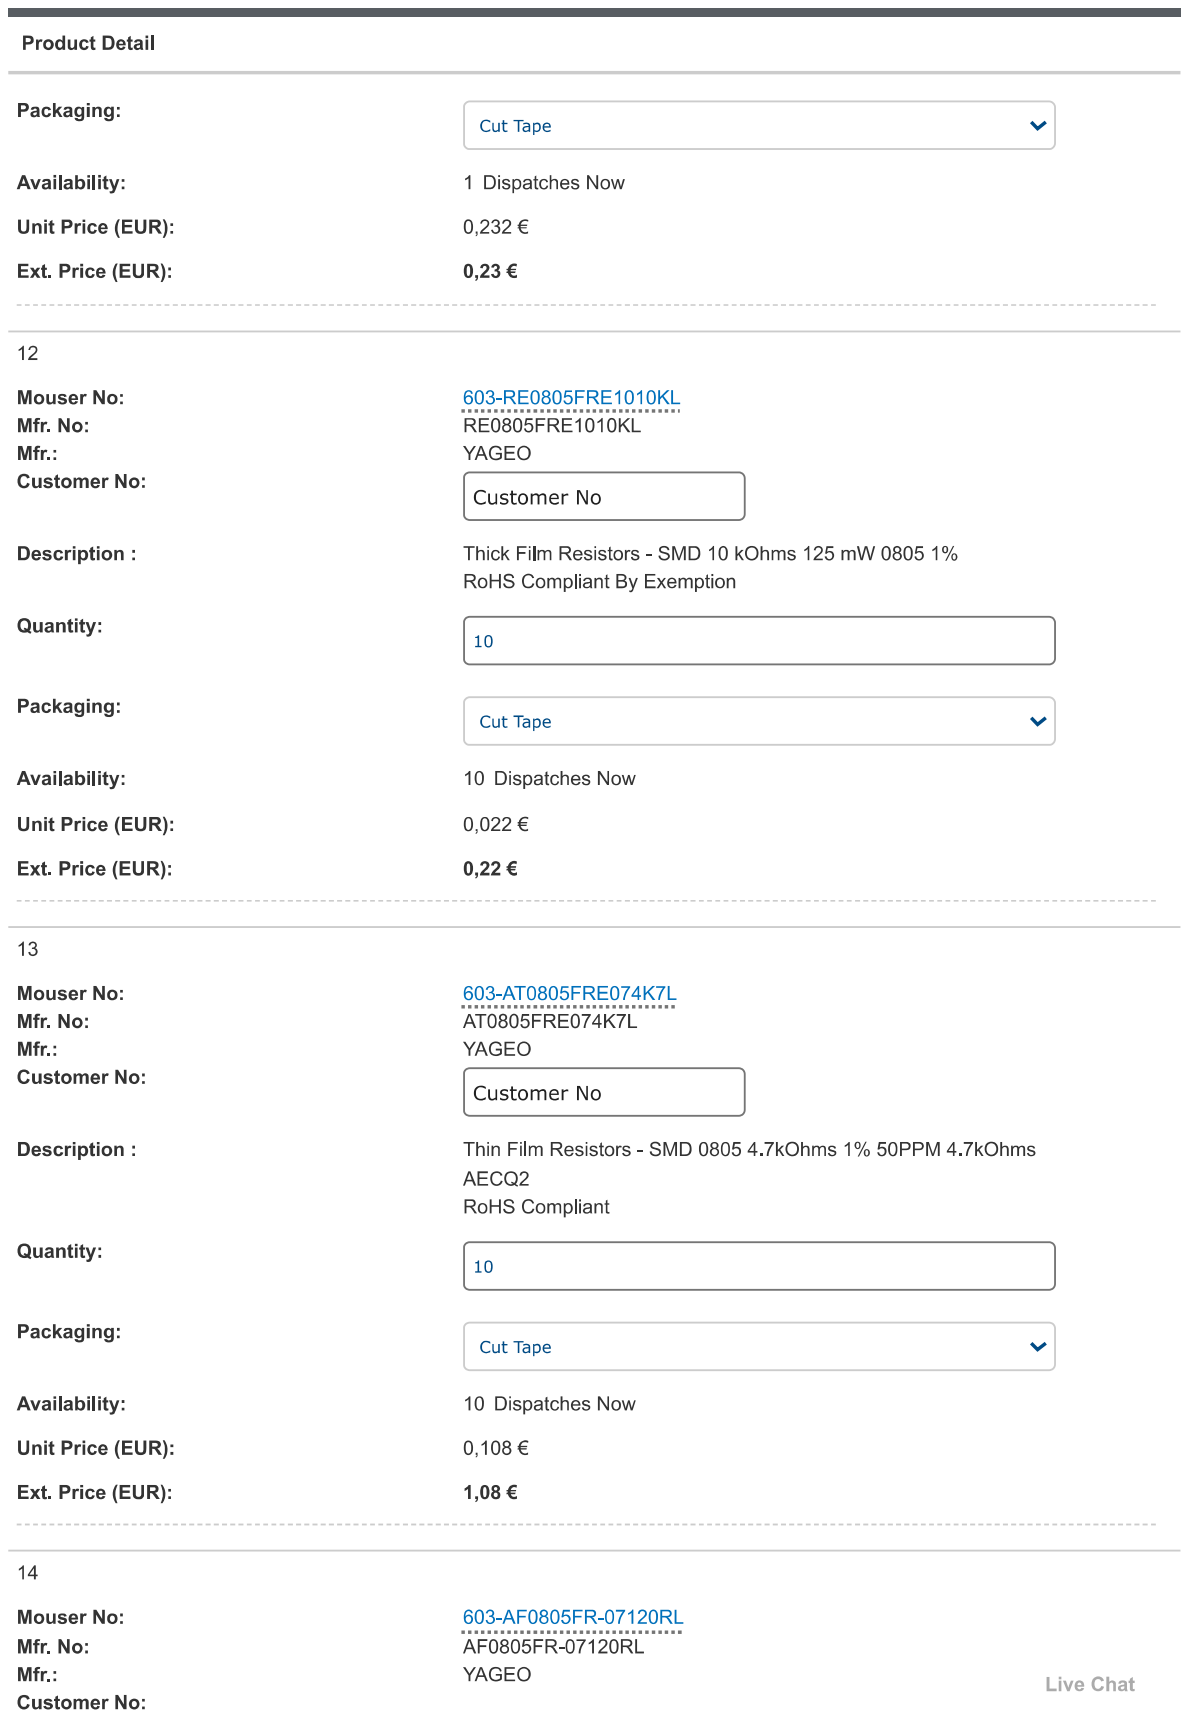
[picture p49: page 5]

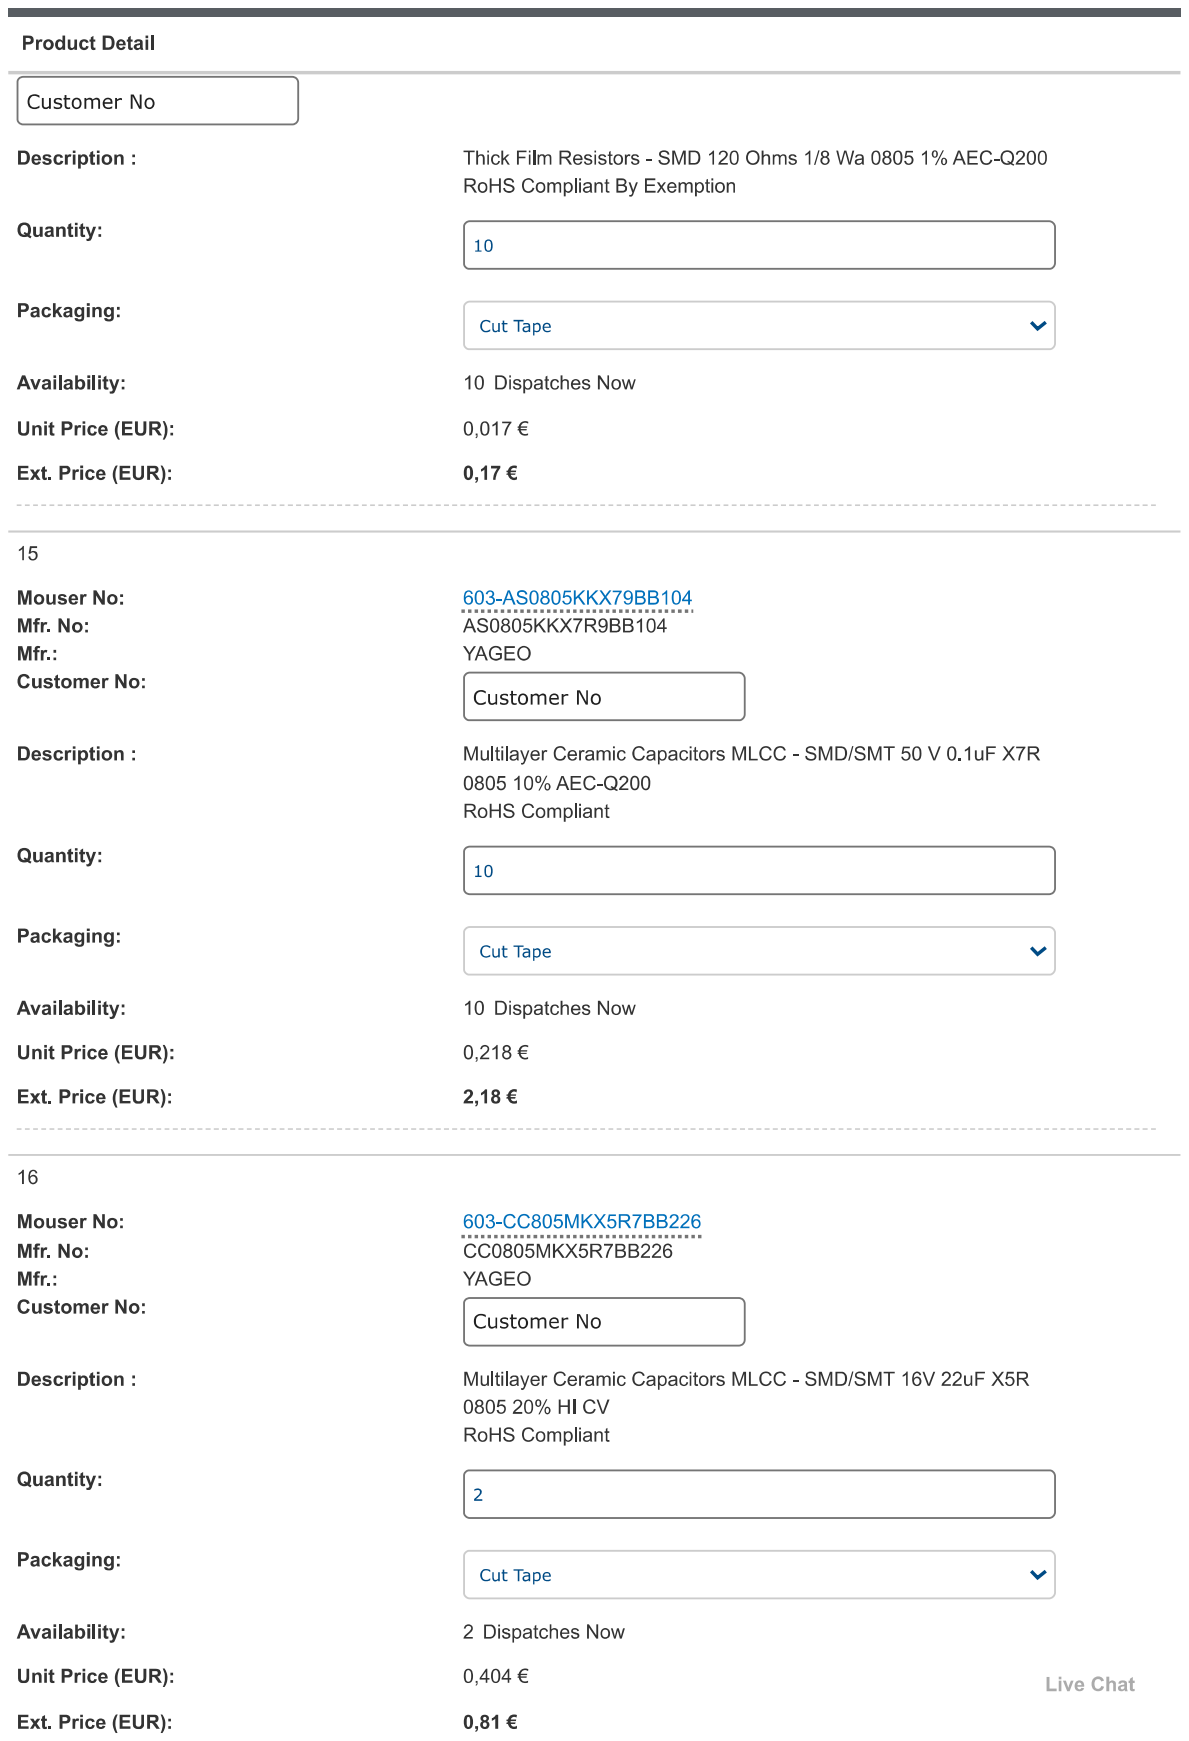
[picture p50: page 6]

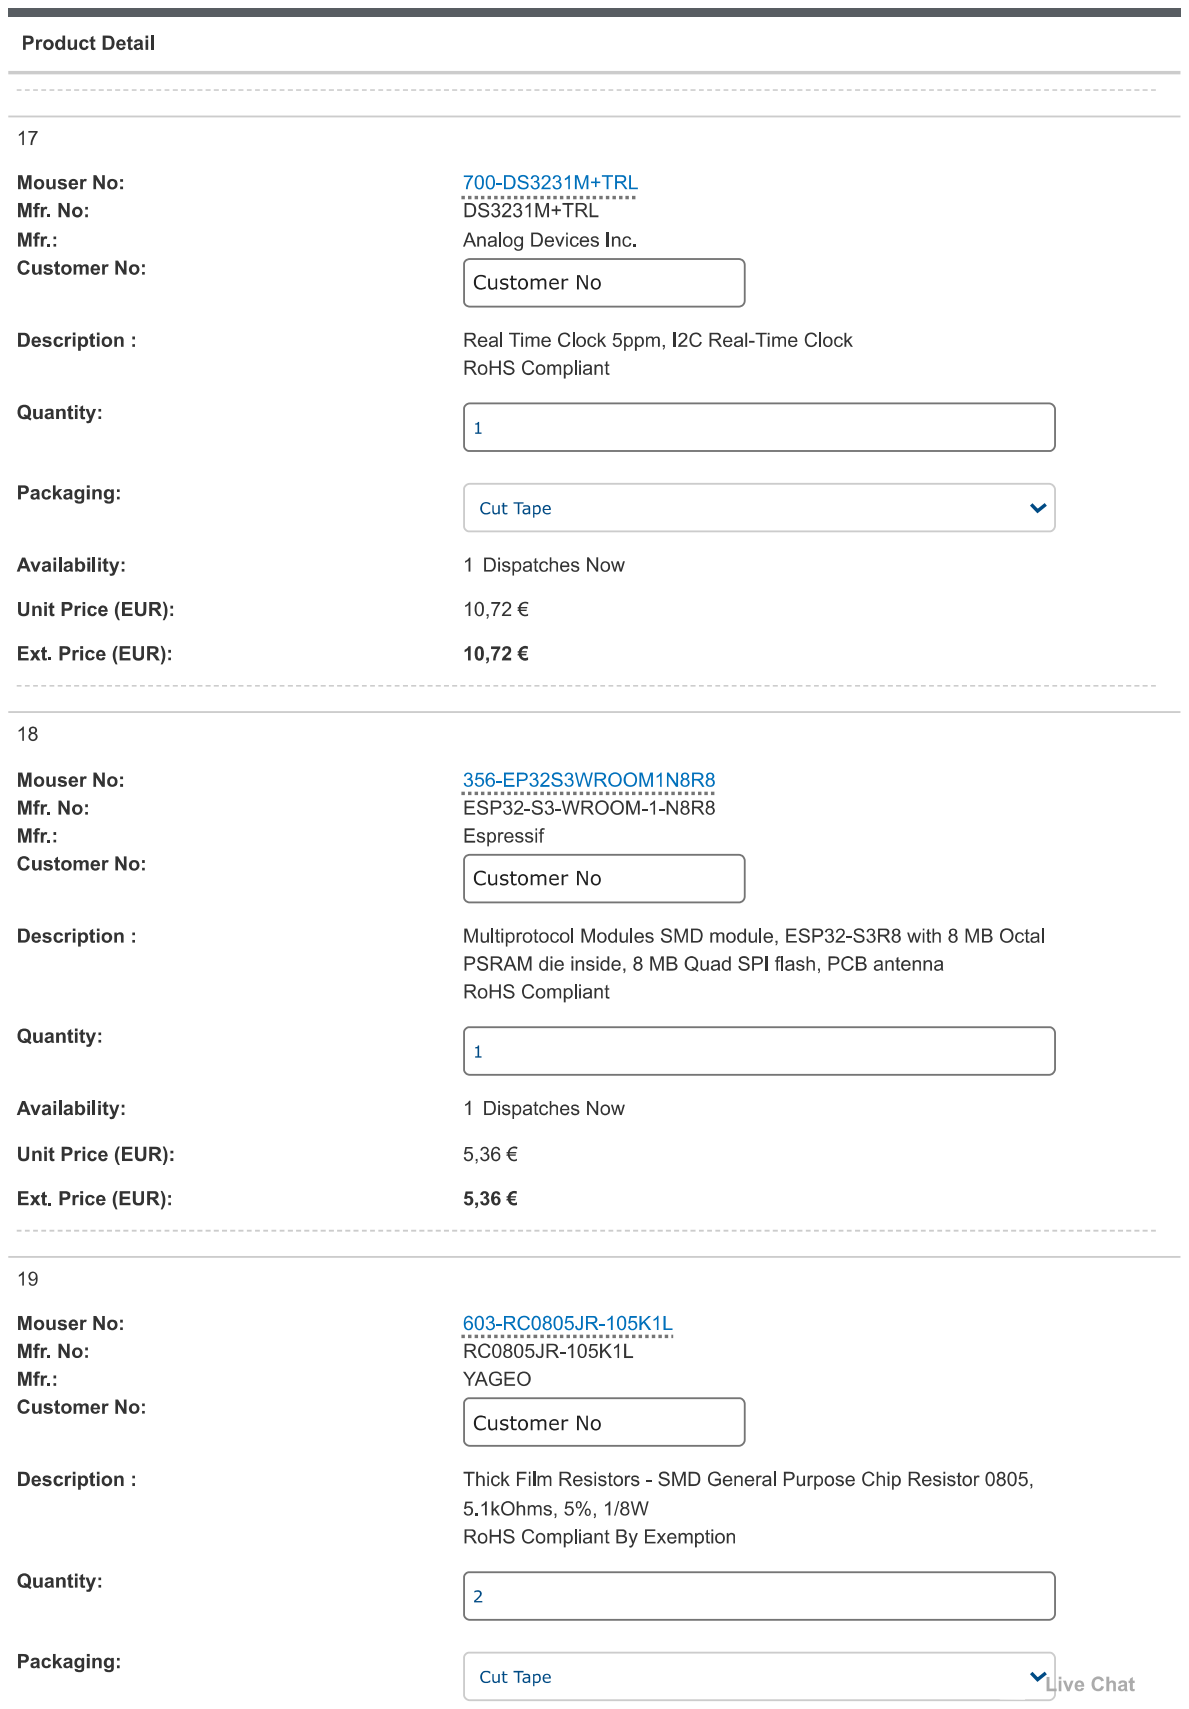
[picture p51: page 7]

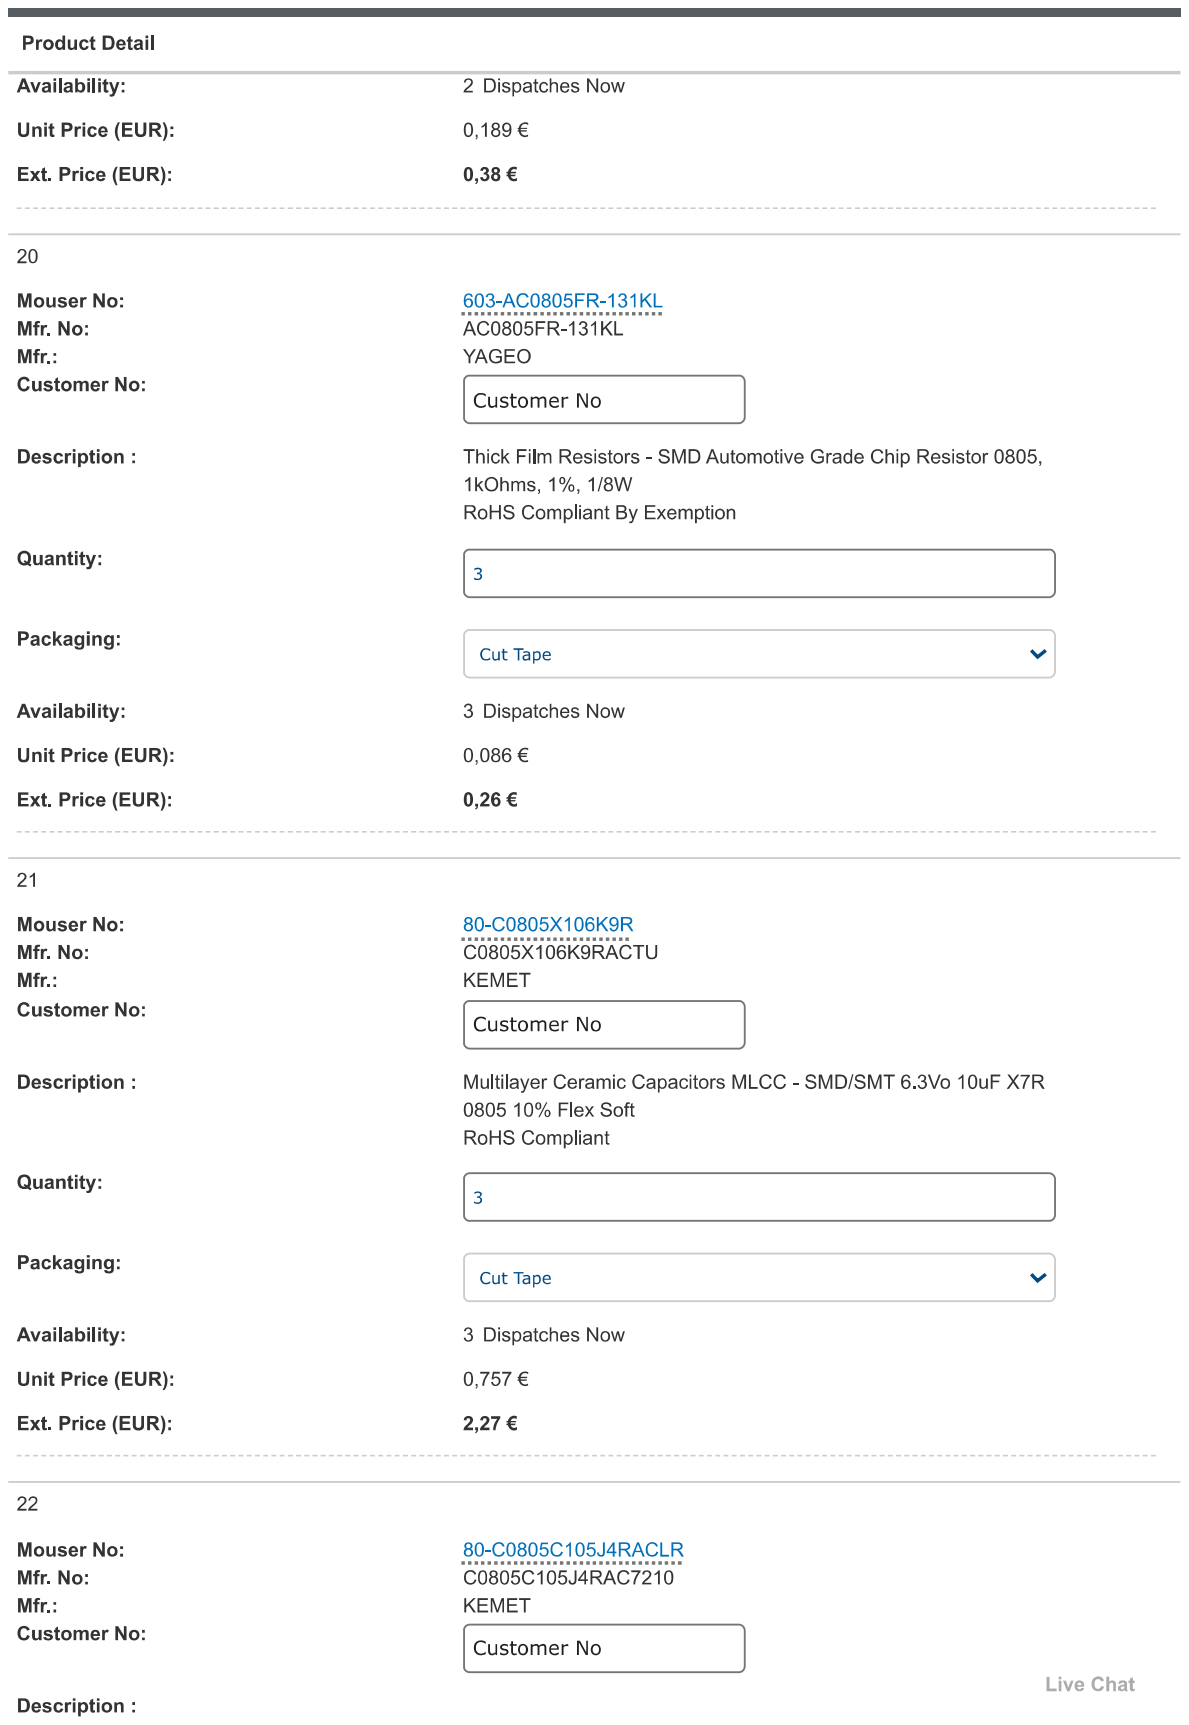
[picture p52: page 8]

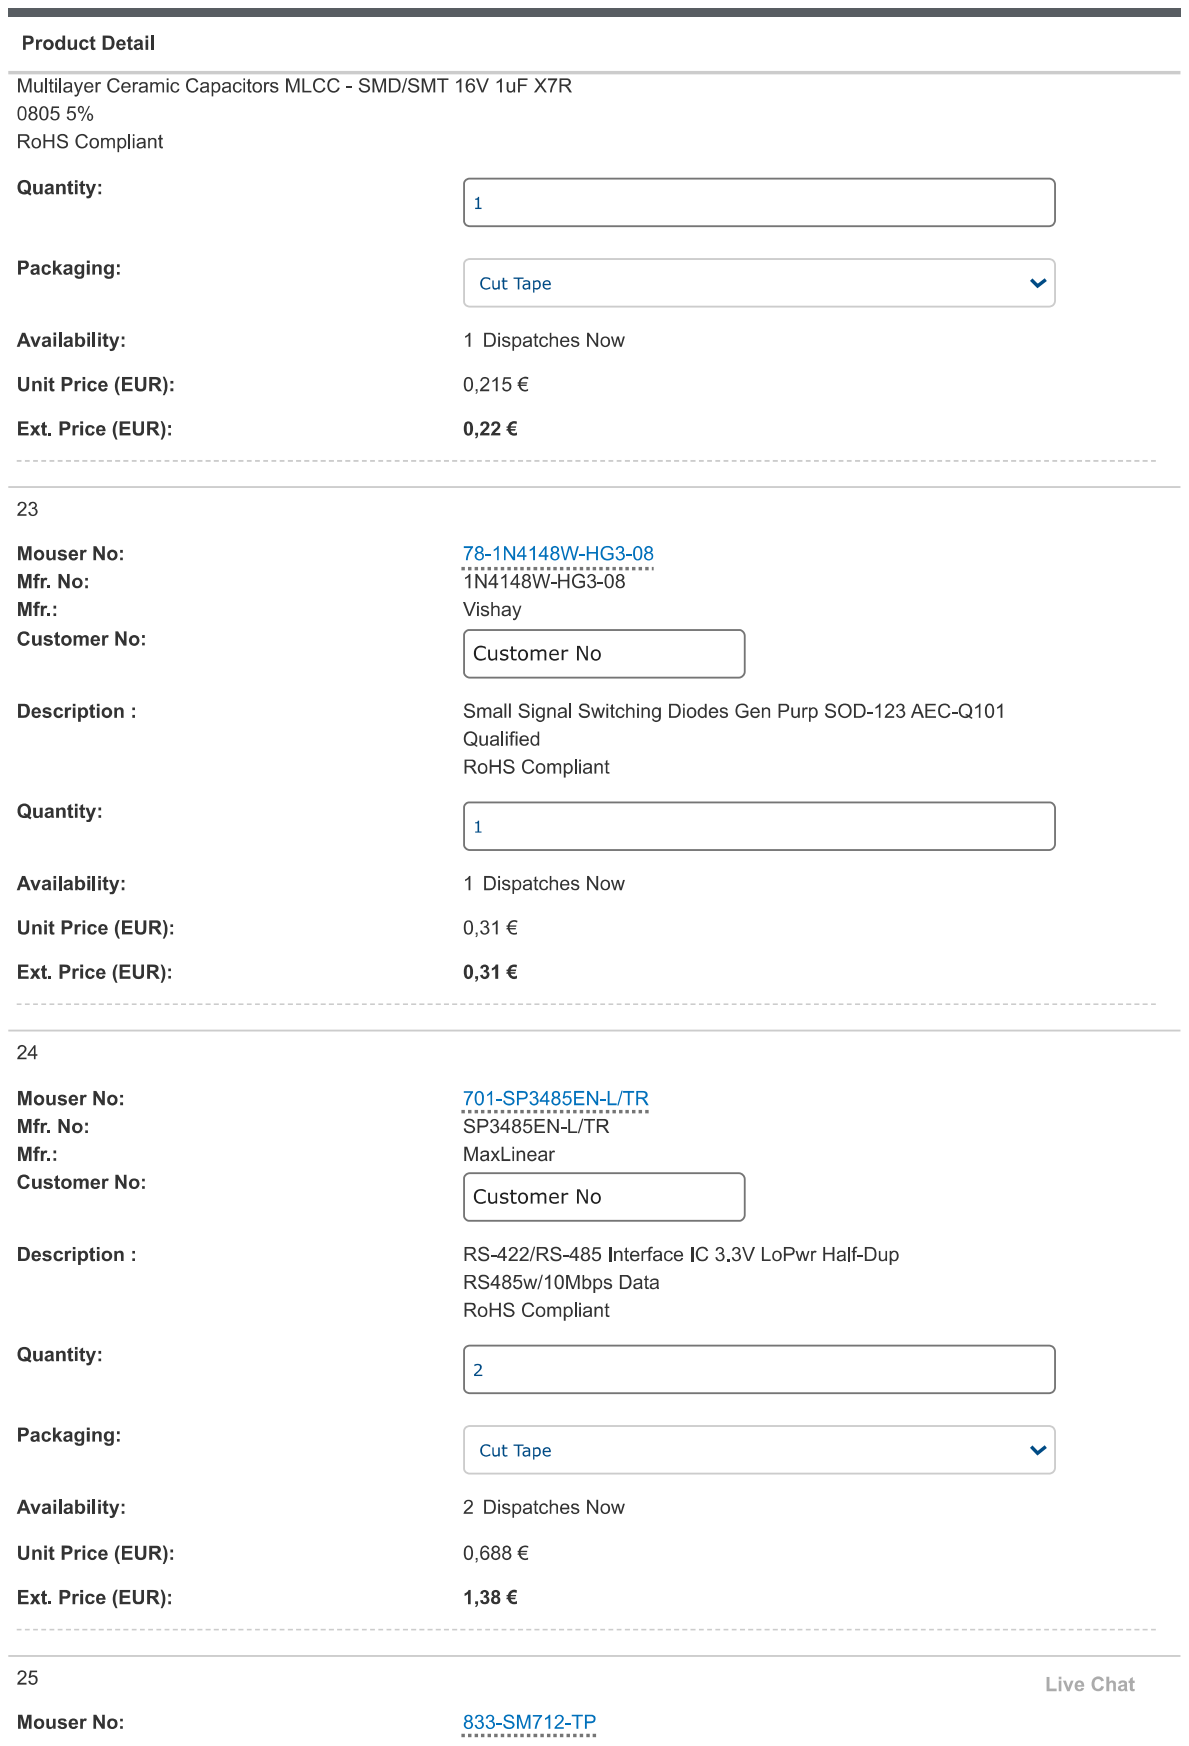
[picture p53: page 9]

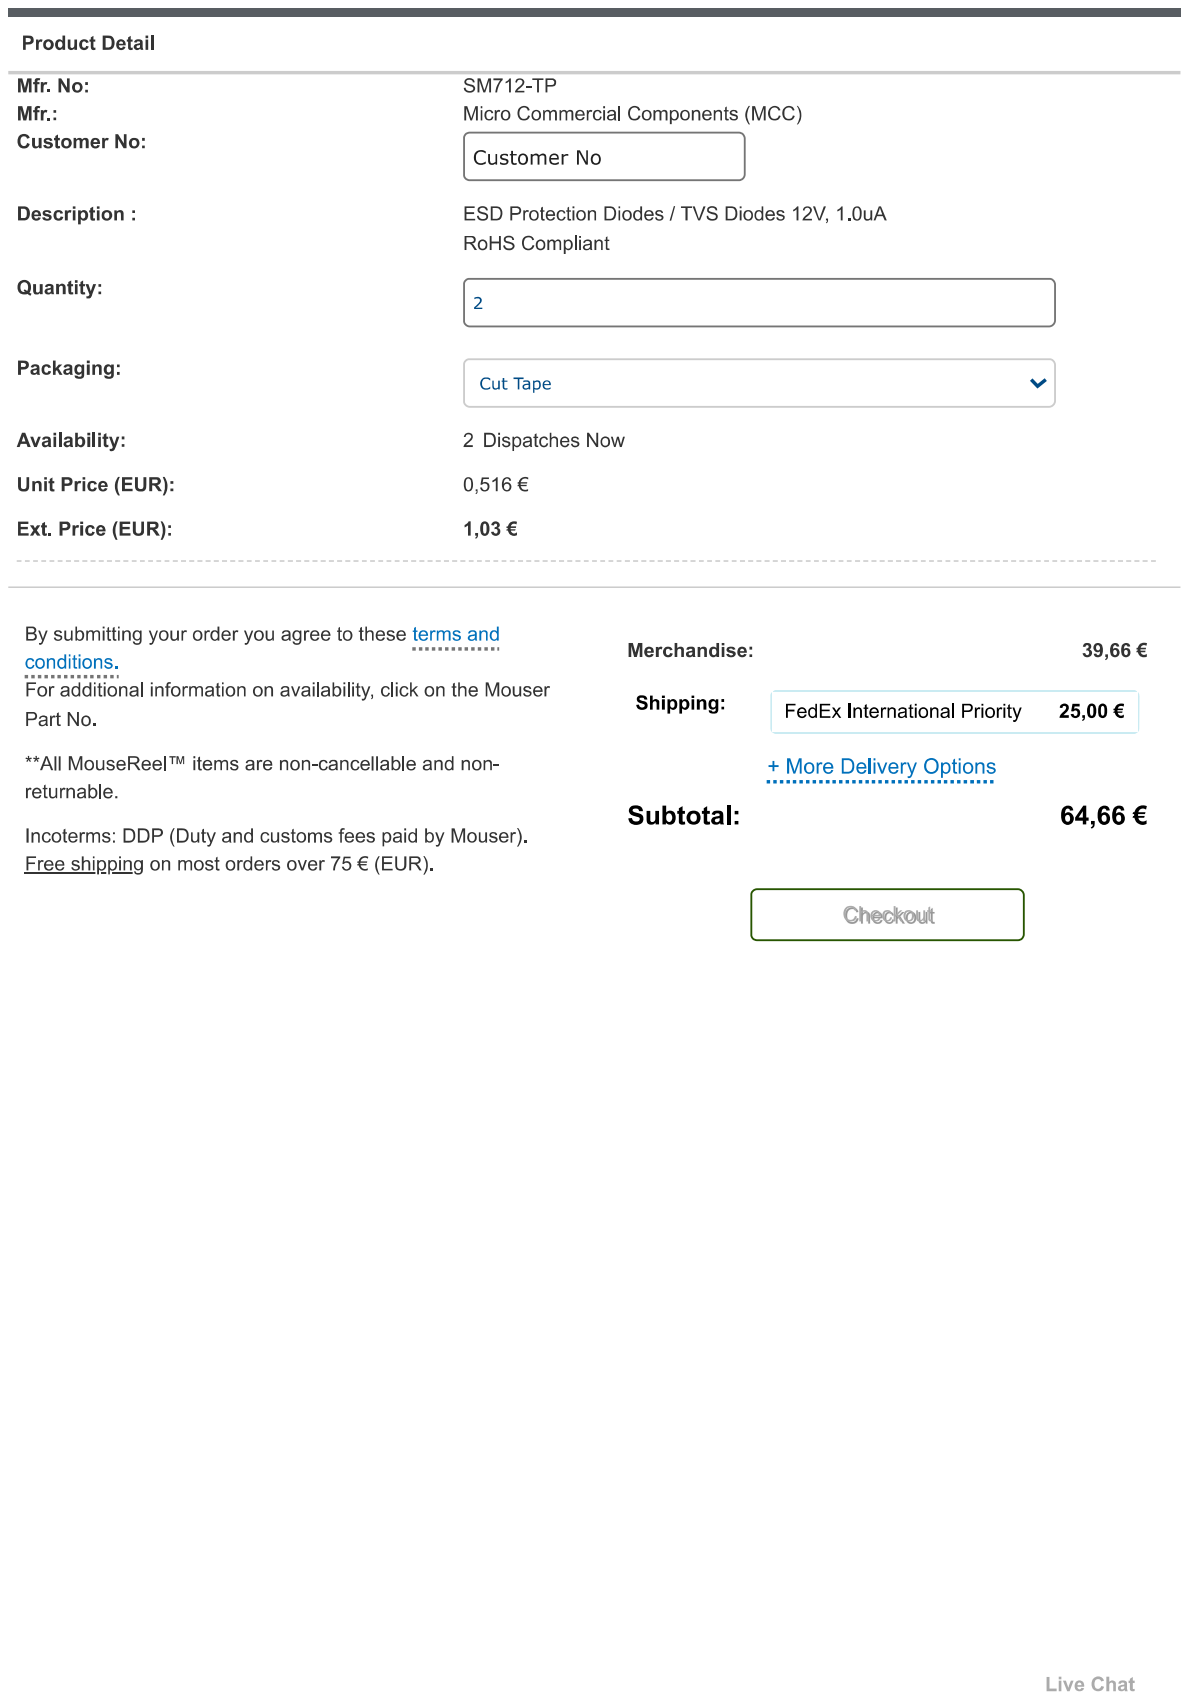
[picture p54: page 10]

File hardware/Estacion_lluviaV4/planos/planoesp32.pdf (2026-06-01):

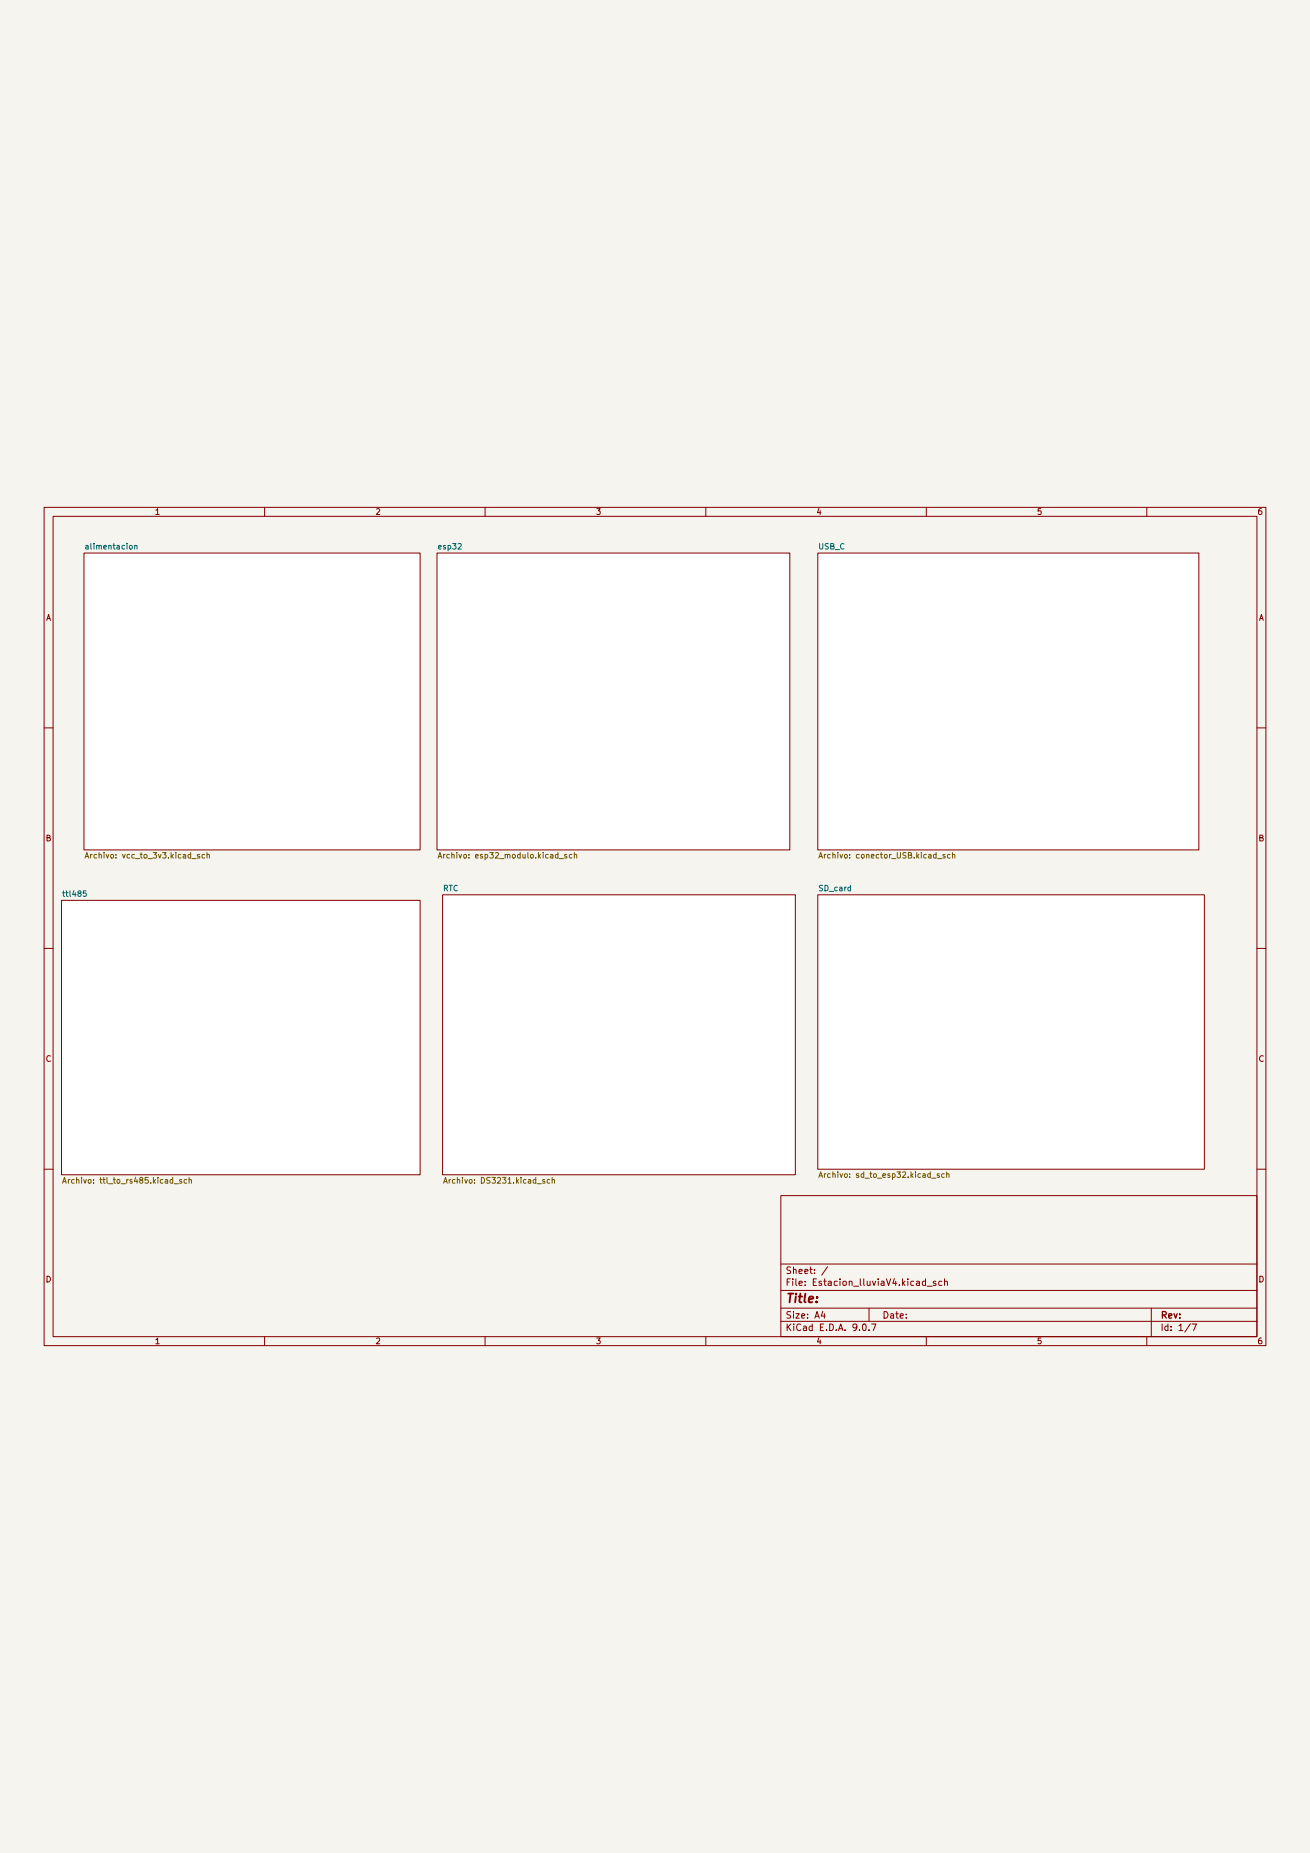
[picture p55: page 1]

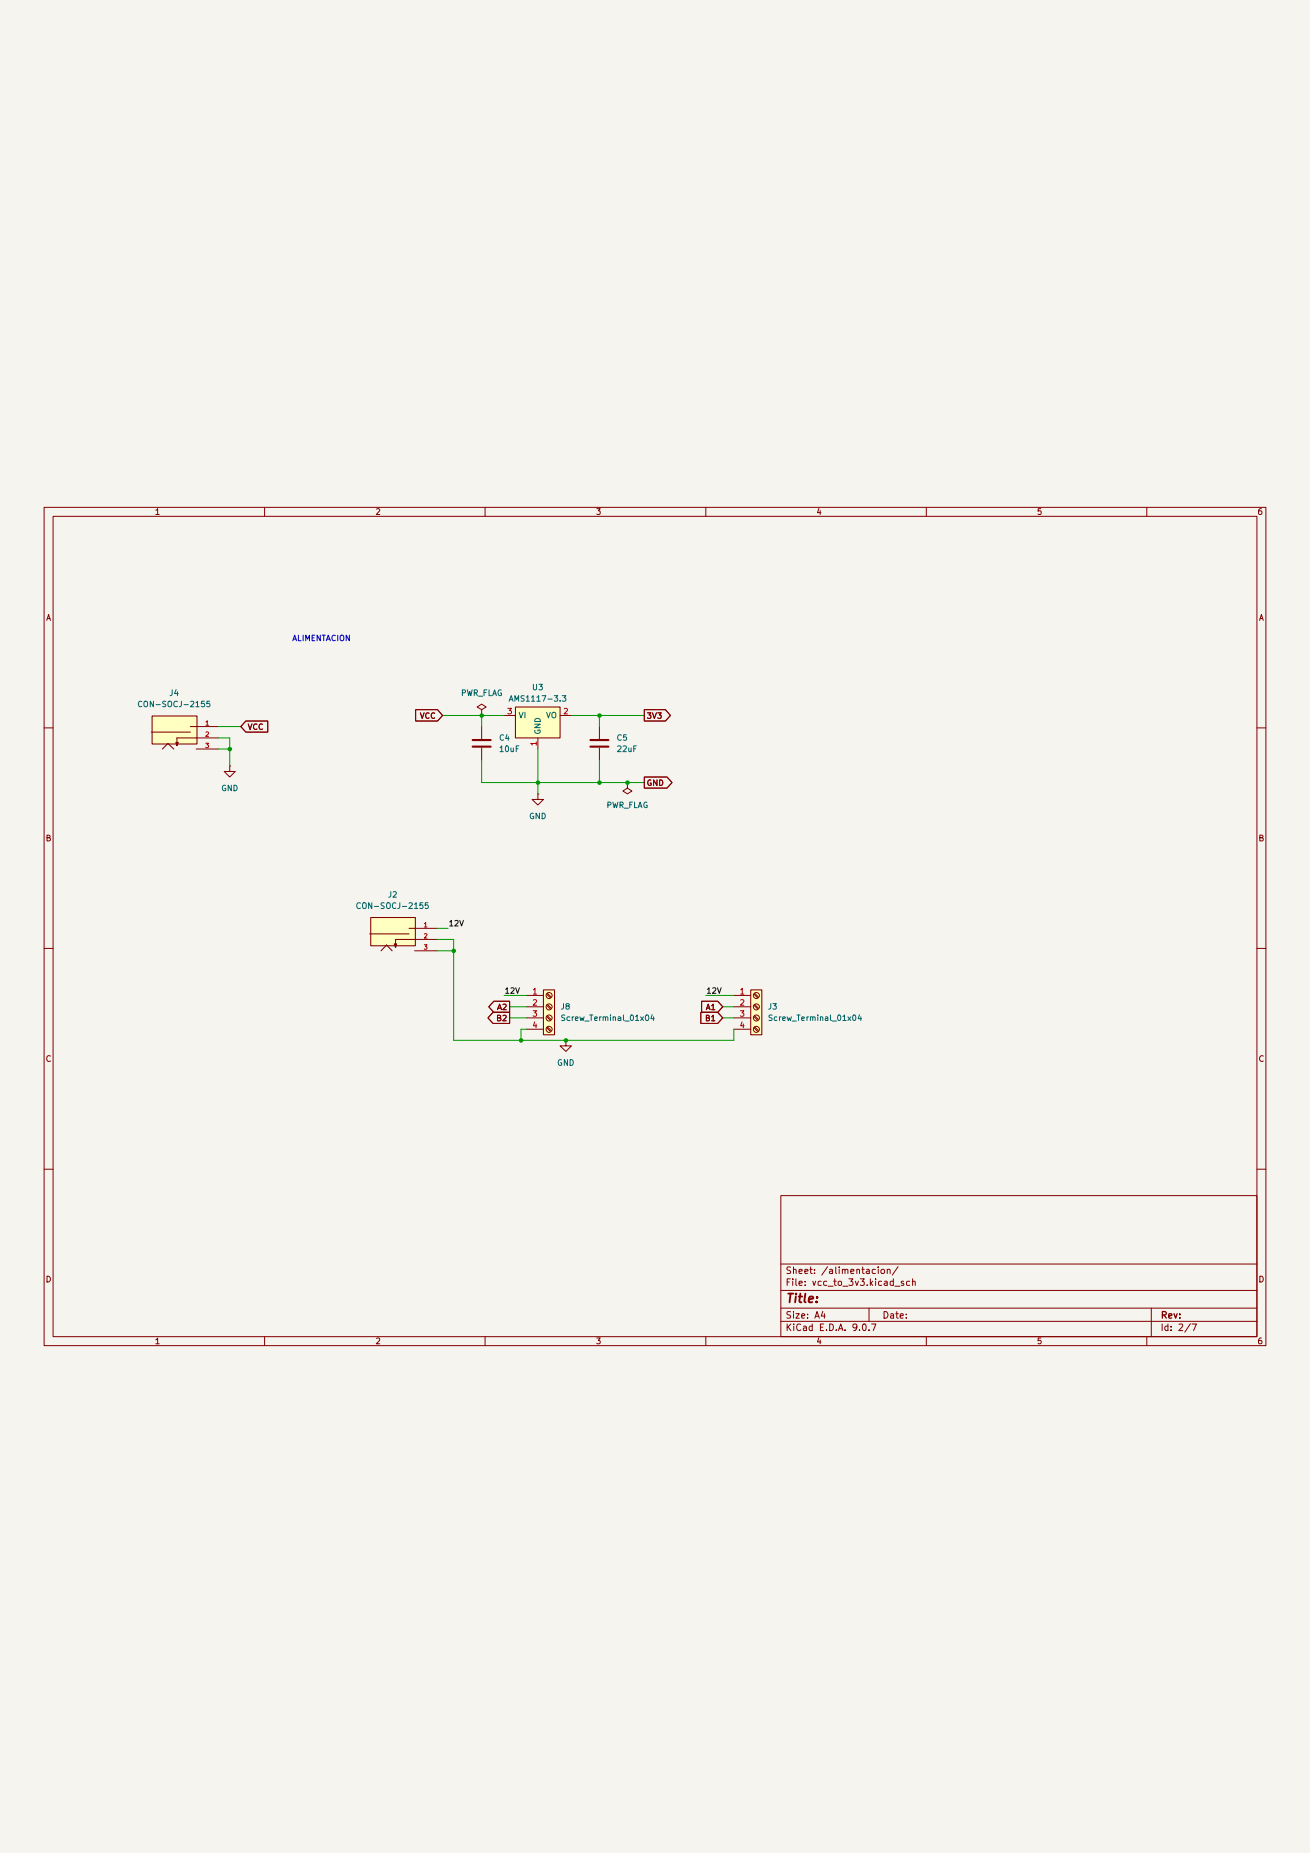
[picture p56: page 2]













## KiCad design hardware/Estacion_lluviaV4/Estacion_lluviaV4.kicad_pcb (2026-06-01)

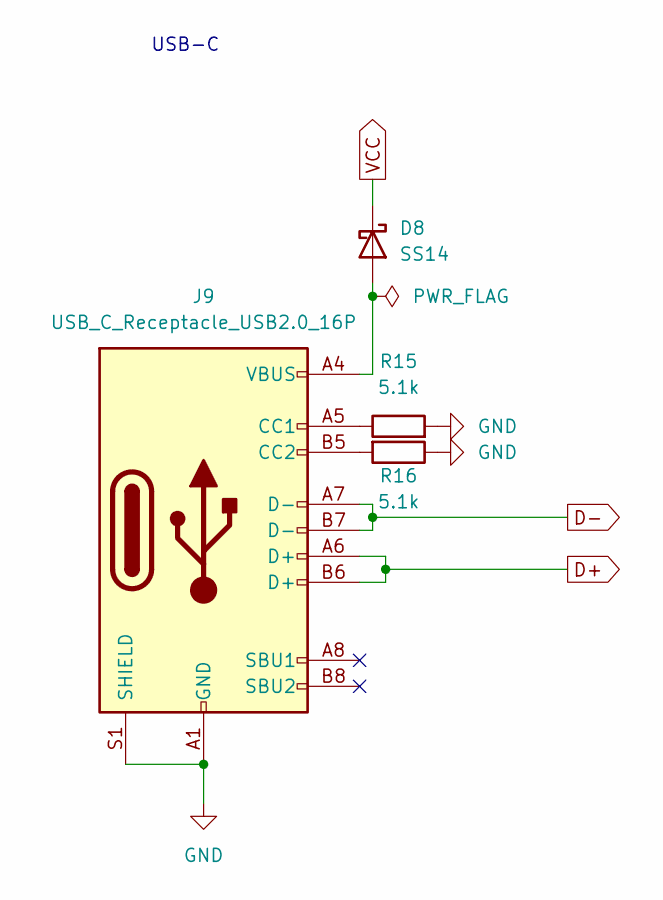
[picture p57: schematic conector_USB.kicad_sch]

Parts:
D8: SS14; D_SMA
J9: USB_C_Receptacle_USB2.0_16P; USB_C_Receptacle_Palconn_UTC16-G
R15, R16: 5.1k; R_0805_2012Metric_Pad1.20x1.40mm_HandSolder

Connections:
D+: J9.A6 (D+), J9.B6 (D+); also elsewhere on the board
D-: J9.A7 (D-), J9.B7 (D-); also elsewhere on the board
GND: J9.A1 (GND), J9.A12 (GND), J9.B1 (GND), J9.B12 (GND), J9.S1 (SHIELD), R15.2, R16.1; also elsewhere on the board
unnamed: D8.2 (A), J9.A4 (VBUS), J9.A9 (VBUS), J9.B4 (VBUS), J9.B9 (VBUS)
unnamed: J9.A5 (CC1), R15.1
unnamed: J9.B5 (CC2), R16.2
VCC: D8.1 (K); also elsewhere on the board

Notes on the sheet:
USB-C

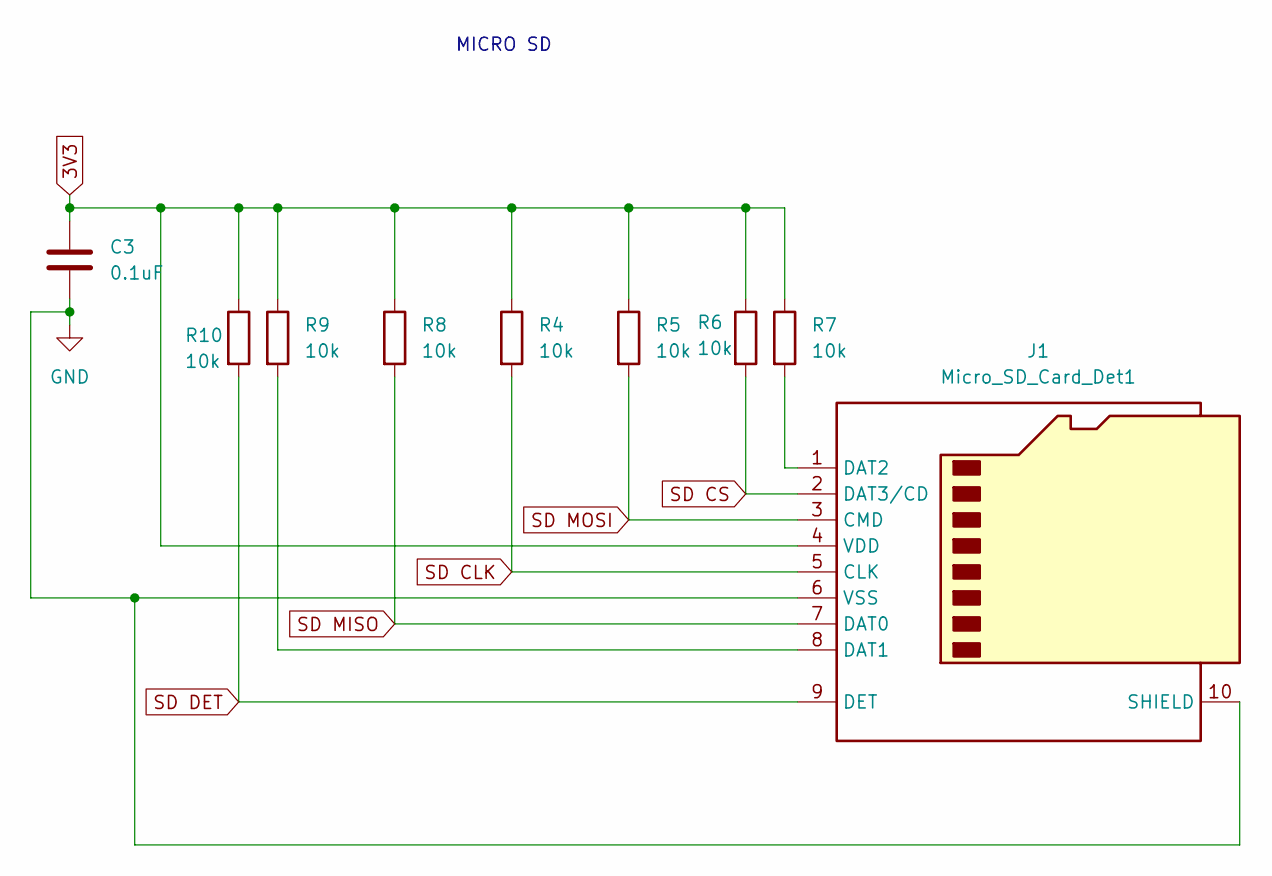
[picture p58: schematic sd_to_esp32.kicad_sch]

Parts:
C3: 0.1uF; C_0805_2012Metric_Pad1.18x1.45mm_HandSolder
J1: Micro_SD_Card_Det1; microSD_HC_Molex_104031-0811
R4, R5, R6, R7, R8, R9, R10: 10k; R_0805_2012Metric_Pad1.20x1.40mm_HandSolder

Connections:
3V3: C3.2, J1.4 (VDD), R4.1, R5.1, R6.1, R7.1, R8.1, R9.1, R10.1; also elsewhere on the board
GND: C3.1, J1.6 (VSS), J1.10 (SHIELD); also elsewhere on the board
unnamed: J1.8 (DAT1), R9.2
unnamed: J1.1 (DAT2), R7.2
SD CLK: J1.5 (CLK), R4.2; also elsewhere on the board
SD CS: J1.2 (DAT3/CD), R6.2; also elsewhere on the board
SD DET: J1.9 (DET), R10.2; also elsewhere on the board
SD MISO: J1.7 (DAT0), R8.2; also elsewhere on the board
SD MOSI: J1.3 (CMD), R5.2; also elsewhere on the board

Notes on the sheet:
MICRO SD

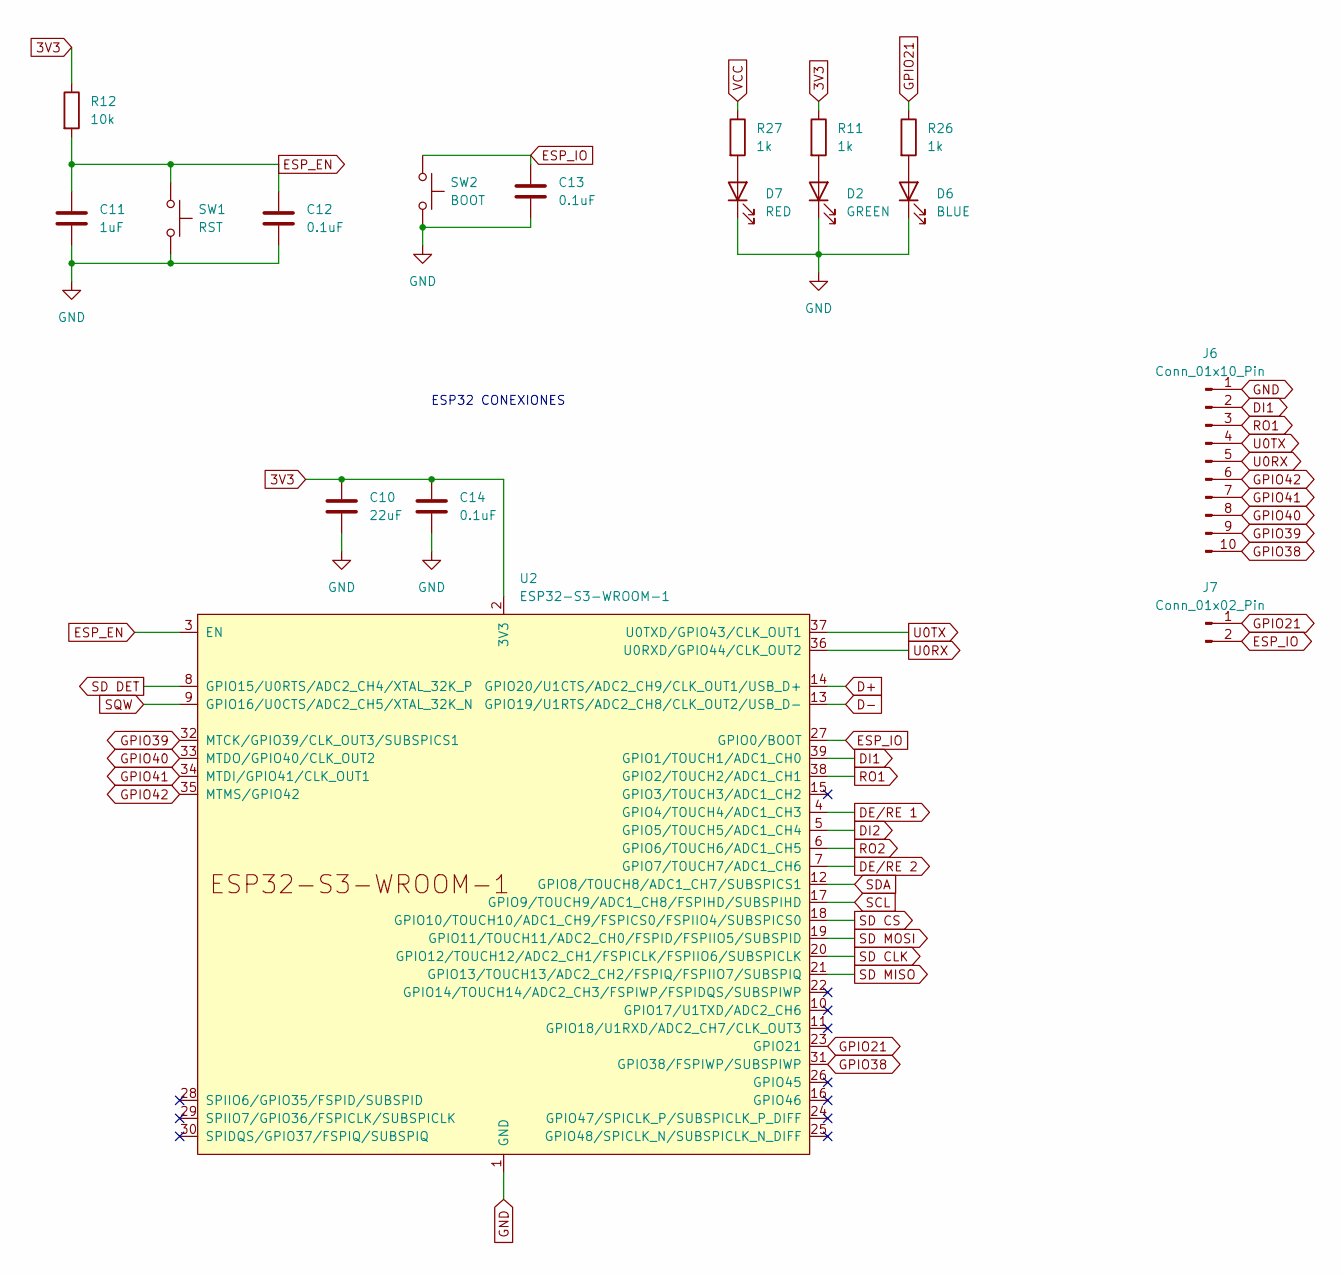
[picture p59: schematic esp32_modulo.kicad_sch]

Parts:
C10: 22uF; C_0805_2012Metric_Pad1.18x1.45mm_HandSolder
C11: 1uF; C_0805_2012Metric_Pad1.18x1.45mm_HandSolder
C12, C13, C14: 0.1uF; C_0805_2012Metric_Pad1.18x1.45mm_HandSolder
D2: GREEN; LED_0805_2012Metric_Pad1.15x1.40mm_HandSolder
D6: BLUE; LED_0805_2012Metric_Pad1.15x1.40mm_HandSolder
D7: RED; LED_0805_2012Metric_Pad1.15x1.40mm_HandSolder
J6: Conn_01x10_Pin; PinHeader_1x10_P2.54mm_Vertical
J7: Conn_01x02_Pin; PinHeader_1x02_P2.54mm_Vertical
R11, R26, R27: 1k; R_0805_2012Metric_Pad1.20x1.40mm_HandSolder
R12: 10k; R_0805_2012Metric_Pad1.20x1.40mm_HandSolder
SW1: RST; SW_Push_1P1T_NO_CK_KMR2
SW2: BOOT; SW_Push_1P1T_NO_CK_KMR2
U2: ESP32-S3-WROOM-1

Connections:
3V3: C10.2, C14.2, R11.1, R12.1, U2.2 (3V3); also elsewhere on the board
D+: U2.14 (GPIO20/U1CTS/ADC2_CH9/CLK_OUT1/USB_D+); also elsewhere on the board
D-: U2.13 (GPIO19/U1RTS/ADC2_CH8/CLK_OUT2/USB_D-); also elsewhere on the board
DE/RE 1: U2.4 (GPIO4/TOUCH4/ADC1_CH3); also elsewhere on the board
DE/RE 2: U2.7 (GPIO7/TOUCH7/ADC1_CH6); also elsewhere on the board
DI1: J6.2, U2.39 (GPIO1/TOUCH1/ADC1_CH0); also elsewhere on the board
DI2: U2.5 (GPIO5/TOUCH5/ADC1_CH4); also elsewhere on the board
ESP_EN: C11.2, C12.2, R12.2, SW1.1, U2.3 (EN)
ESP_IO: C13.2, J7.2, SW2.1, U2.27 (GPIO0/BOOT)
GND: C10.1, C11.1, C12.1, C13.1, C14.1, D2.1 (K), D6.1 (K), D7.1 (K), J6.1, SW1.2, SW2.2, U2.1 (GND), U2.40 (GND), U2.41 (GND); also elsewhere on the board
GPIO21: J7.1, R26.1, U2.23 (GPIO21)
GPIO38: J6.10, U2.31 (GPIO38/FSPIWP/SUBSPIWP)
GPIO39: J6.9, U2.32 (MTCK/GPIO39/CLK_OUT3/SUBSPICS1)
GPIO40: J6.8, U2.33 (MTDO/GPIO40/CLK_OUT2)
GPIO41: J6.7, U2.34 (MTDI/GPIO41/CLK_OUT1)
GPIO42: J6.6, U2.35 (MTMS/GPIO42)
unnamed: D2.2 (A), R11.2
unnamed: D6.2 (A), R26.2
unnamed: D7.2 (A), R27.2
RO1: J6.3, U2.38 (GPIO2/TOUCH2/ADC1_CH1); also elsewhere on the board
RO2: U2.6 (GPIO6/TOUCH6/ADC1_CH5); also elsewhere on the board
SCL: U2.17 (GPIO9/TOUCH9/ADC1_CH8/FSPIHD/SUBSPIHD); also elsewhere on the board
SD CLK: U2.20 (GPIO12/TOUCH12/ADC2_CH1/FSPICLK/FSPIIO6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); also elsewhere on the board
SD CS: U2.18 (GPIO10/TOUCH10/ADC1_CH9/FSPICS0/FSPIIO4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); also elsewhere on the board
SD DET: U2.8 (GPIO15/U0RTS/ADC2_CH4/XTAL_32K_P); also elsewhere on the board
SD MISO: U2.21 (GPIO13/TOUCH13/ADC2_CH2/FSPIQ/FSPIIO7/S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); also elsewhere on the board
SD MOSI: U2.19 (GPIO11/TOUCH11/ADC2_CH0/FSPID/FSPIIO5/S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); also elsewhere on the board
SDA: U2.12 (GPIO8/TOUCH8/ADC1_CH7/SUBSPICS1); also elsewhere on the board
SQW: U2.9 (GPIO16/U0CTS/ADC2_CH5/XTAL_32K_N); also elsewhere on the board
U0RX: J6.5, U2.36 (U0RXD/GPIO44/CLK_OUT2)
U0TX: J6.4, U2.37 (U0TXD/GPIO43/CLK_OUT1)
VCC: R27.1; also elsewhere on the board

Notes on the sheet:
ESP32 CONEXIONES

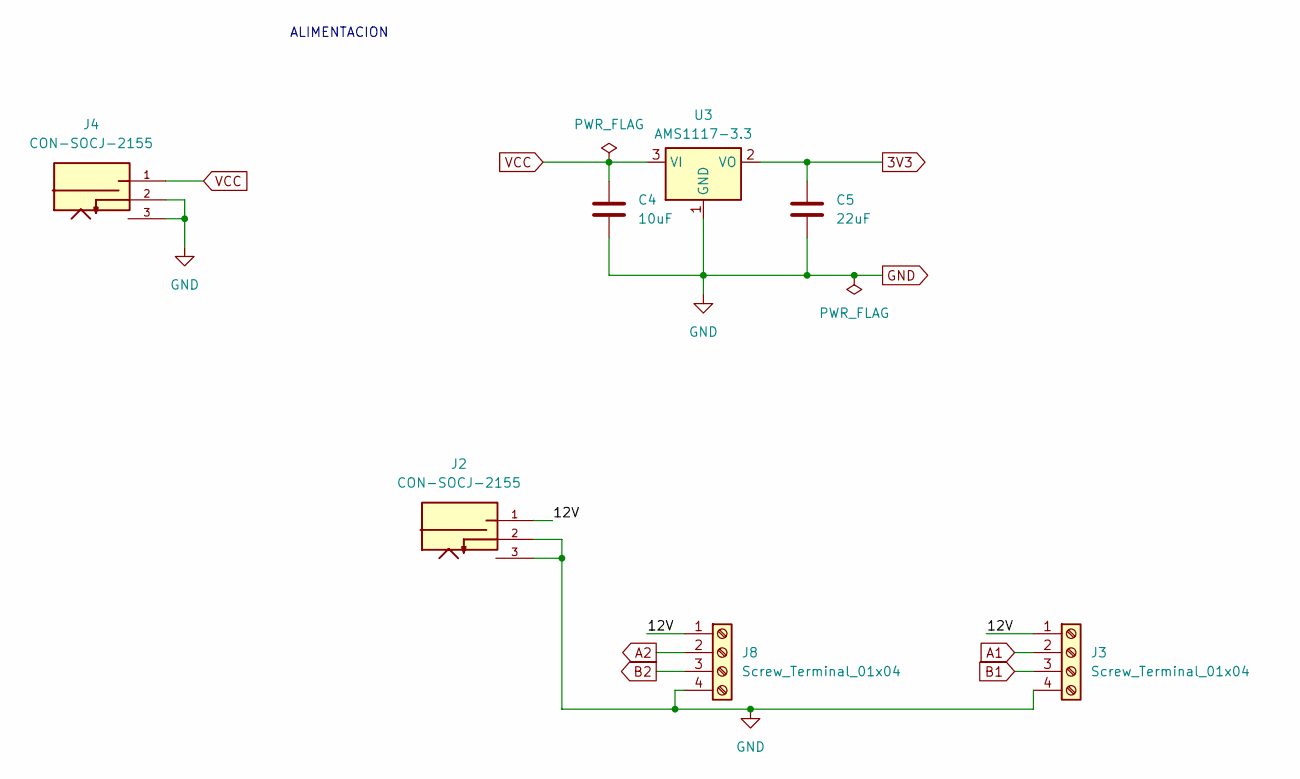
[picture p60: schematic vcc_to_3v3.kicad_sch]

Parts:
C4: 10uF; C_0805_2012Metric_Pad1.18x1.45mm_HandSolder
C5: 22uF; C_0805_2012Metric_Pad1.18x1.45mm_HandSolder
J2, J4: CON-SOCJ-2155; PARTREV NA
J3, J8: Screw_Terminal_01x04; TerminalBlock_MaiXu_MX126-5.0-04P_1x04_P5.00mm
U3: AMS1117-3.3; SOT-223-3_TabPin2

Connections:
3V3: C5.2, U3.2 (VO); also elsewhere on the board
/alimentacion/12V: J2.1, J3.1, J8.1
A1: J3.2; also elsewhere on the board
A2: J8.2; also elsewhere on the board
B1: J3.3; also elsewhere on the board
B2: J8.3; also elsewhere on the board
GND: C4.1, C5.1, J2.2, J2.3, J3.4, J4.2, J4.3, J8.4, U3.1 (GND); also elsewhere on the board
VCC: C4.2, J4.1, U3.3 (VI); also elsewhere on the board

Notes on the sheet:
ALIMENTACION

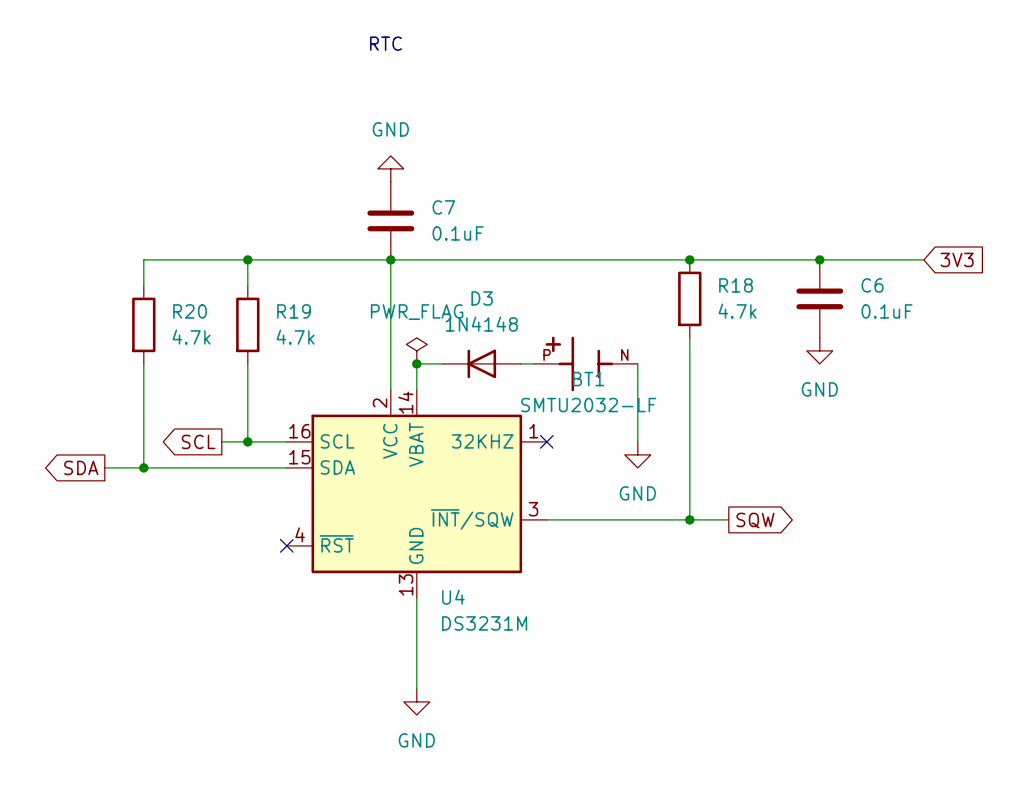
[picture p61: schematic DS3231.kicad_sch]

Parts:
BT1: SMTU2032-LF; BAT_SMTU2032-LF; PARTREV 3
C6, C7: 0.1uF; C_0805_2012Metric_Pad1.18x1.45mm_HandSolder
D3: 1N4148; D_SOD-123
R18, R19, R20: 4.7k; R_0805_2012Metric_Pad1.20x1.40mm_HandSolder
U4: DS3231M; SOIC-16W_7.5x10.3mm_P1.27mm

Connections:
3V3: C6.2, C7.1, R18.1, R19.1, R20.1, U4.2 (VCC); also elsewhere on the board
GND: BT1.N, C6.1, C7.2, U4.5 (GND), U4.6 (GND), U4.7 (GND), U4.8 (GND), U4.9 (GND), U4.10 (GND), U4.11 (GND), U4.12 (GND), U4.13 (GND); also elsewhere on the board
unnamed: BT1.P, D3.2 (A)
unnamed: D3.1 (K), U4.14 (VBAT)
SCL: R19.2, U4.16 (SCL); also elsewhere on the board
SDA: R20.2, U4.15 (SDA); also elsewhere on the board
SQW: R18.2, U4.3 (~INT/SQW); also elsewhere on the board

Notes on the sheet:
RTC

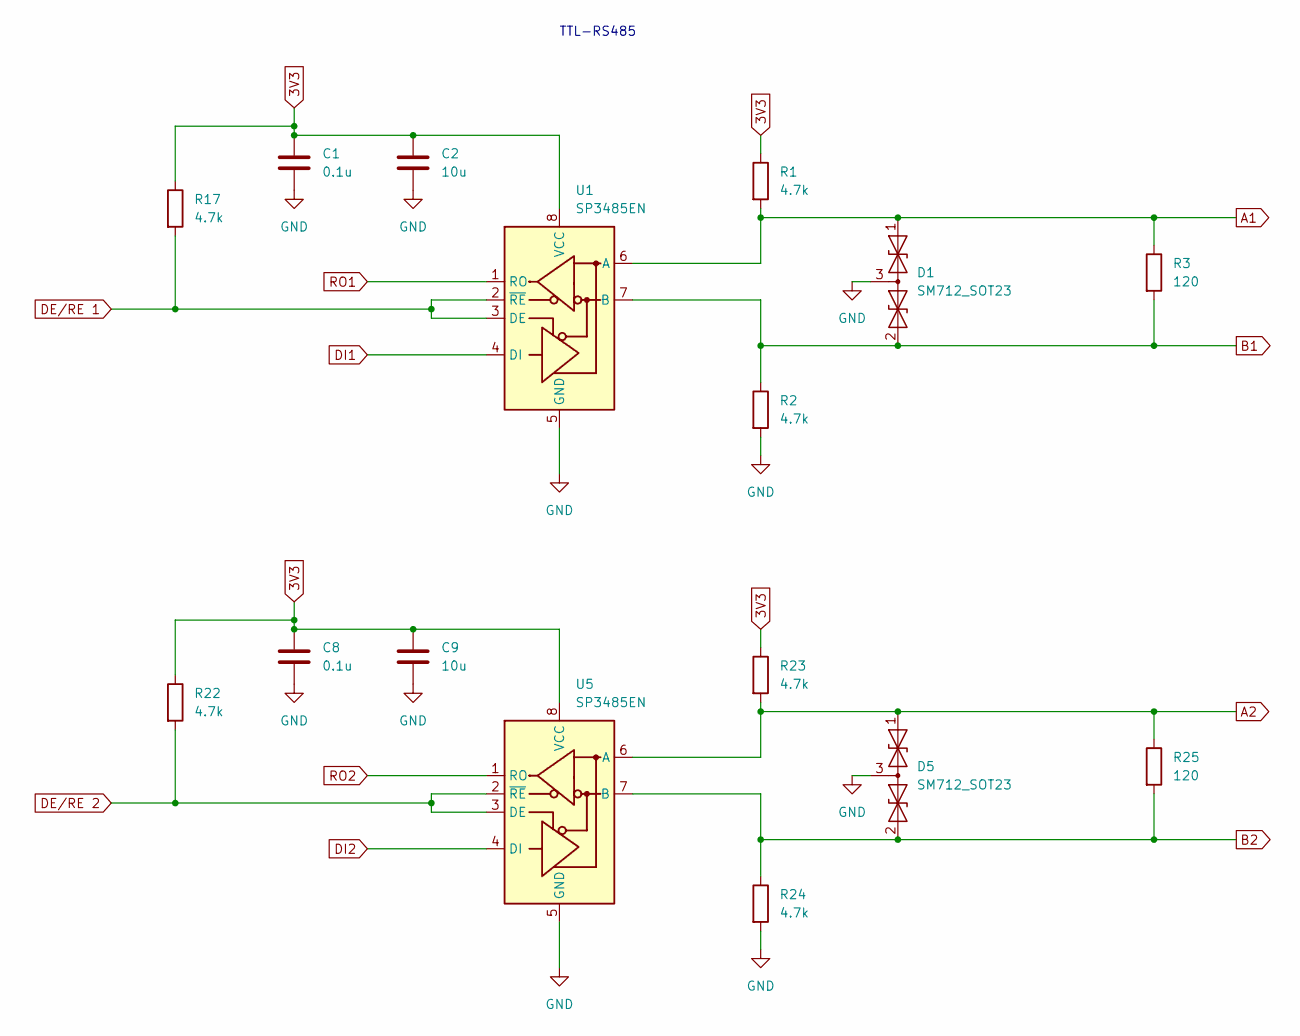
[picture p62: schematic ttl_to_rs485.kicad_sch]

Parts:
C1, C8: 0.1u; C_0805_2012Metric_Pad1.18x1.45mm_HandSolder
C2, C9: 10u; C_0805_2012Metric_Pad1.18x1.45mm_HandSolder
D1, D5: SM712_SOT23; SOT-23
R1, R2, R17, R22, R23, R24: 4.7k; R_0805_2012Metric_Pad1.20x1.40mm_HandSolder
R3, R25: 120; R_0805_2012Metric_Pad1.20x1.40mm_HandSolder
U1, U5: SP3485EN; SOIC-8_3.9x4.9mm_P1.27mm

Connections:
3V3: C1.1, C2.1, C8.1, C9.1, R1.1, R17.1, R22.1, R23.1, U1.8 (VCC), U5.8 (VCC); also elsewhere on the board
A1: D1.1 (A1), R1.2, R3.1, U1.6 (A); also elsewhere on the board
A2: D5.1 (A1), R23.2, R25.1, U5.6 (A); also elsewhere on the board
B1: D1.2 (A2), R2.1, R3.2, U1.7 (B); also elsewhere on the board
B2: D5.2 (A2), R24.1, R25.2, U5.7 (B); also elsewhere on the board
DE/RE 1: R17.2, U1.2 (~RE), U1.3 (DE); also elsewhere on the board
DE/RE 2: R22.2, U5.2 (~RE), U5.3 (DE); also elsewhere on the board
DI1: U1.4 (DI); also elsewhere on the board
DI2: U5.4 (DI); also elsewhere on the board
GND: C1.2, C2.2, C8.2, C9.2, D1.3 (common), D5.3 (common), R2.2, R24.2, U1.5 (GND), U5.5 (GND); also elsewhere on the board
RO1: U1.1 (RO); also elsewhere on the board
RO2: U5.1 (RO); also elsewhere on the board

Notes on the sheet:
TTL-RS485

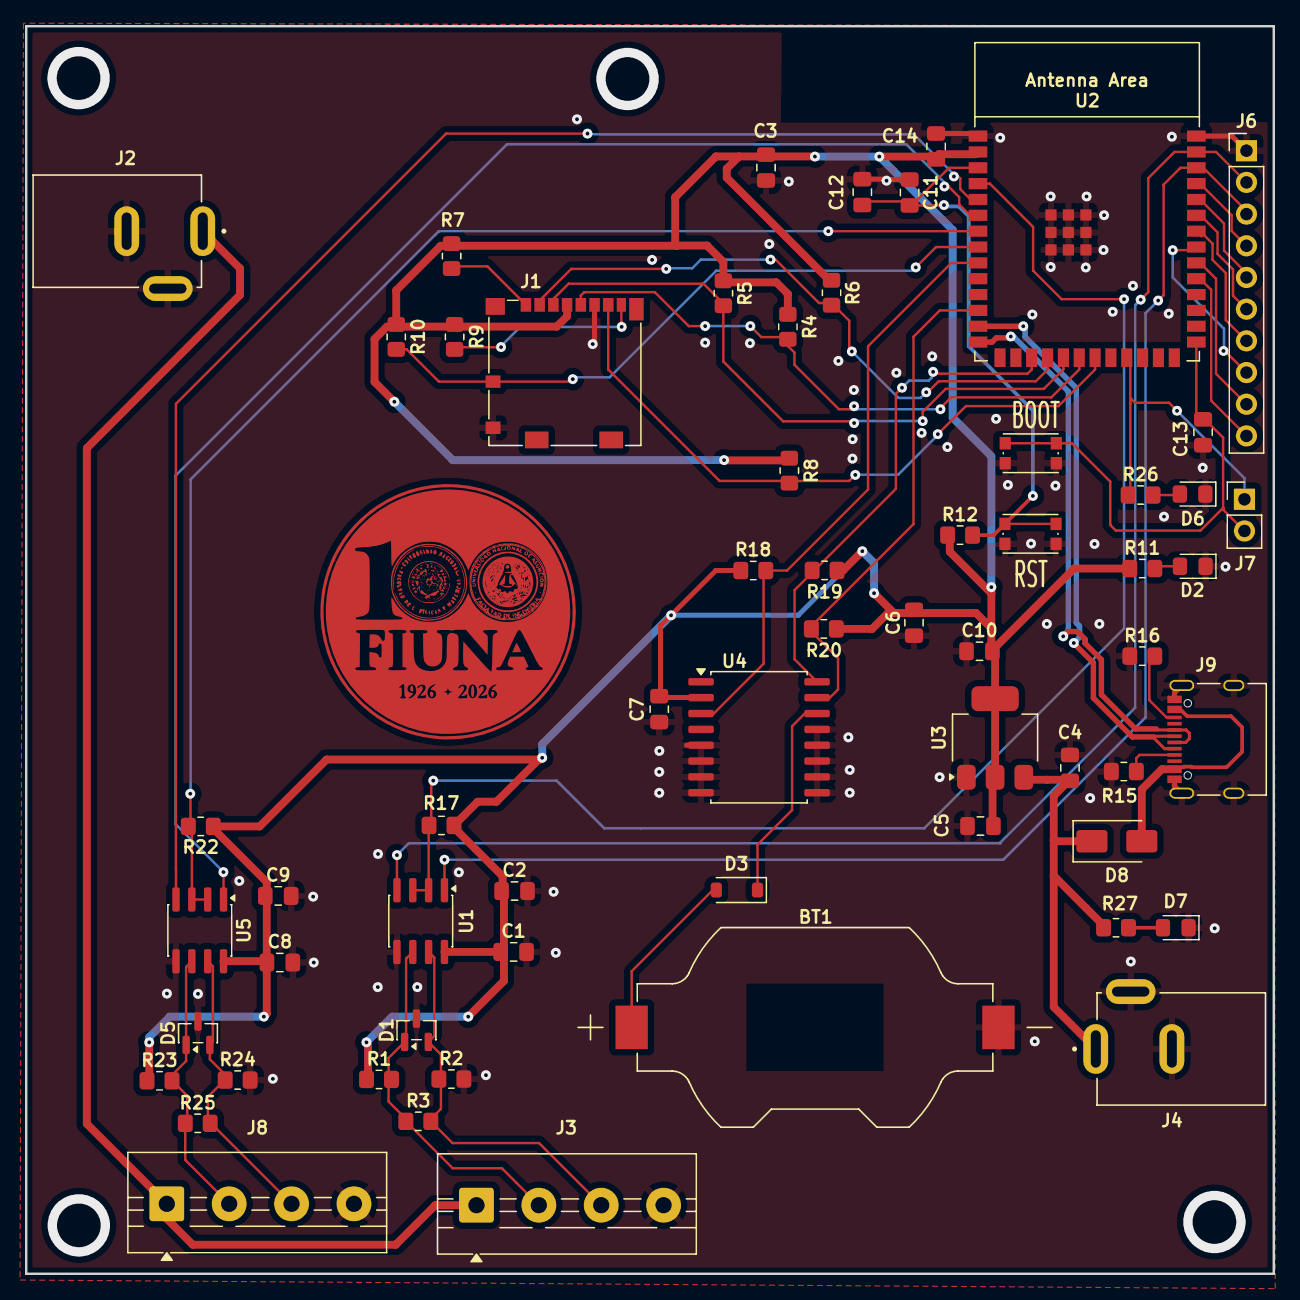
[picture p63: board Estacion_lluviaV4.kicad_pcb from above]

Board: 2 copper layers, 100.0 x 100.0 mm, 61 parts (0 on the bottom side), 44 nets.

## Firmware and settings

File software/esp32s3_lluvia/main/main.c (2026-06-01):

#include "freertos/FreeRTOS.h"
#include "freertos/task.h"
#include "esp_log.h"
#include "rtc.h"
#include "sdcard.h"
#include "modbus_rtu.h"
#include "dtu.h"
#include <string.h>
#include <stdio.h>

static const char *TAG = "MAIN";

#define MEASUREMENT_PERIOD_SEC      60
#define MAX_EXECUTION_LAG_SEC       2
#define QUEUE_RETRY_INTERVAL_MS     10000
#define LOOP_IDLE_MS                50

#define MAIN_LOG_FILE   "/datalog.csv"
#define TEMP_QUEUE_FILE "/temp.csv"
#define CSV_HEADER      "Timestamp,Lluvia_mm"

#define SERVER_TIME_OFFSET_SEC 10800

static uint32_t last_slot_epoch  = 0;
static uint32_t last_queue_retry = 0;

static void format_timestamp(const ds3231_datetime_t *dt, char *buf, size_t len)
{
    snprintf(buf, len, "20%02d-%02d-%02d %02d:%02d:%02d",
             dt->anio, dt->mes, dt->fecha,
             dt->horas, dt->minutos, dt->segundos);
}

static uint32_t rtc_to_epoch(const ds3231_datetime_t *dt)
{
    uint32_t days = dt->anio * 365 + dt->mes * 30 + dt->fecha;
    return days * 86400 + dt->horas * 3600 + dt->minutos * 60 + dt->segundos;
}

static bool is_measurement_due(const ds3231_datetime_t *dt, uint32_t *slot_out)
{
    uint32_t epoch = rtc_to_epoch(dt);
    uint32_t slot  = (epoch / MEASUREMENT_PERIOD_SEC) * MEASUREMENT_PERIOD_SEC;
    uint32_t delta = epoch - slot;

    if (delta > MAX_EXECUTION_LAG_SEC) return false;
    if (slot == last_slot_epoch)       return false;

    *slot_out = slot;
    return true;
}

static void build_csv_line(const char *timestamp, float rain_mm, char *buf, size_t len)
{
    snprintf(buf, len, "%s,%.1f", timestamp, rain_mm);
}

static uint32_t datetime_to_unix(const ds3231_datetime_t *dt)
{
    // Días desde epoch hasta 2000-01-01 = 10957
    uint16_t year = 2000 + dt->anio;
    uint16_t month = dt->mes;
    uint16_t day   = dt->fecha;

    // Algoritmo de días desde epoch
    if (month < 3) { year--; month += 12; }
    uint32_t days = 365 * year + year/4 - year/100 + year/400
                  + (153 * month - 457) / 5
                  + day - 719469;  // ajuste a epoch 1970

    return days * 86400
         + dt->horas   * 3600
         + dt->minutos * 60
         + dt->segundos;
}

static bool send_to_server(const char *timestamp, float rain_mm)
{
    ds3231_datetime_t dt = {0};

    sscanf(timestamp, "20%hhu-%hhu-%hhu %hhu:%hhu:%hhu",
           &dt.anio, &dt.mes, &dt.fecha,
           &dt.horas, &dt.minutos, &dt.segundos);

   
    uint32_t unix_ts = datetime_to_unix(&dt) + SERVER_TIME_OFFSET_SEC;

    char payload[64];
    snprintf(payload, sizeof(payload), "d=%lu,%.1f", unix_ts, rain_mm);

    char response[256] = {0};
    int bytes = dtu_send_and_receive(payload, response, sizeof(response));

    if (bytes <= 0) {
        ESP_LOGW(TAG, "Sin respuesta del DTU");
        return false;
    }

    if (strstr(response, "ERROR") || strstr(response, "FAIL")) {
        ESP_LOGW(TAG, "DTU respondio error: %s", response);
        return false;
    }

    ESP_LOGI(TAG, "DTU respuesta: %s", response);
    return true;
}

static void tomar_medicion(uint32_t slot)
{
    ESP_LOGI(TAG, "──────────────────────────────────");
    ESP_LOGI(TAG, "Iniciando medicion. Slot=%lu", slot);

    float rain_mm = 0.0f;
    esp_err_t ret = modbus_read_rain(&rain_mm);
    if (ret != ESP_OK) {
        ESP_LOGW(TAG, "Fallo lectura Modbus. Ciclo cancelado.");
        return;
    }

    ds3231_datetime_t dt;
    char timestamp[24] = {0};
    if (ds3231_get_datetime(&dt) == ESP_OK) {
        format_timestamp(&dt, timestamp, sizeof(timestamp));
    } else {
        snprintf(timestamp, sizeof(timestamp), "0000-00-00 00:00:00");
    }

    ESP_LOGI(TAG, "Medicion: %s → %.1f mm", timestamp, rain_mm);

    char csv_line[64];
    build_csv_line(timestamp, rain_mm, csv_line, sizeof(csv_line));
    sdcard_append_line(MAIN_LOG_FILE, csv_line);

    bool hay_pendientes = sdcard_count_records(TEMP_QUEUE_FILE) > 0;

    if (hay_pendientes) {
        ESP_LOGW(TAG, "Hay pendientes. Guardando en temp.csv.");
        sdcard_append_line(TEMP_QUEUE_FILE, csv_line);
    } else {
        bool sent = send_to_server(timestamp, rain_mm);
        if (!sent) {
            ESP_LOGW(TAG, "Fallo envio. Guardando en temp.csv.");
            sdcard_append_line(TEMP_QUEUE_FILE, csv_line);
        } else {
            ESP_LOGI(TAG, "Enviado correctamente.");
        }
    }

    ret = modbus_reset_rain();
    if (ret != ESP_OK) {
        ESP_LOGW(TAG, "No se pudo resetear registro de lluvia.");
    }
}

static void procesar_cola(void)
{
    if (sdcard_count_records(TEMP_QUEUE_FILE) == 0) return;

    char record[64] = {0};
    if (sdcard_read_first_record(TEMP_QUEUE_FILE, record, sizeof(record)) != ESP_OK) {
        ESP_LOGW(TAG, "No se pudo leer primer pendiente.");
        return;
    }

    ESP_LOGI(TAG, "Reintentando pendiente: %s", record);

    char timestamp[24] = {0};
    float rain_mm = 0.0f;
    int parsed = sscanf(record, "%23[^,],%f", timestamp, &rain_mm);

    if (parsed != 2) {
        ESP_LOGW(TAG, "Formato invalido en cola: %s", record);
        sdcard_remove_first_record(TEMP_QUEUE_FILE, CSV_HEADER);
        return;
    }

    bool sent = send_to_server(timestamp, rain_mm);
    if (sent) {
        ESP_LOGI(TAG, "Pendiente enviado. Eliminando de cola.");
        sdcard_remove_first_record(TEMP_QUEUE_FILE, CSV_HEADER);
    } else {
        ESP_LOGW(TAG, "Fallo reenvio. Cola intacta.");
    }
}

static void init_all(void)
{
    ESP_LOGI(TAG, "══════════════════════════════════");
    ESP_LOGI(TAG, "  Estacion de lluvia — v1.0");
    ESP_LOGI(TAG, "══════════════════════════════════");

    ESP_ERROR_CHECK(ds3231_init());
    ESP_ERROR_CHECK(ds3231_enable_sqw_1hz());

    ESP_ERROR_CHECK(sdcard_init());
    sdcard_ensure_file(MAIN_LOG_FILE, CSV_HEADER);
    sdcard_ensure_file(TEMP_QUEUE_FILE, CSV_HEADER);

    ESP_ERROR_CHECK(modbus_rtu_init());
    ESP_ERROR_CHECK(dtu_init());

    ds3231_datetime_t dt;
    if (ds3231_get_datetime(&dt) == ESP_OK) {
        char ts[24];
        format_timestamp(&dt, ts, sizeof(ts));
        ESP_LOGI(TAG, "Hora actual: %s", ts);
    }

    ESP_LOGI(TAG, "Pendientes en cola: %lu", sdcard_count_records(TEMP_QUEUE_FILE));
    ESP_LOGI(TAG, "Sistema listo.");
}

void app_main(void)
{
    init_all();

    while (1) {
        ds3231_datetime_t dt;
        if (ds3231_get_datetime(&dt) != ESP_OK) {
            vTaskDelay(pdMS_TO_TICKS(LOOP_IDLE_MS));
            continue;
        }

        uint32_t slot = 0;
        if (is_measurement_due(&dt, &slot)) {
            last_slot_epoch = slot;
            tomar_medicion(slot);
        } else {
            uint32_t now_ms = xTaskGetTickCount() * portTICK_PERIOD_MS;
            if (now_ms - last_queue_retry > QUEUE_RETRY_INTERVAL_MS) {
                procesar_cola();
                last_queue_retry = now_ms;
            }
        }

        vTaskDelay(pdMS_TO_TICKS(LOOP_IDLE_MS));
    }
}

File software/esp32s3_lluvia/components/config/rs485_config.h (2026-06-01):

#pragma once

#include "driver/uart.h"
#include "driver/gpio.h"

/************************************************************
 * RS485 — Sensor de lluvia
 ************************************************************/

#define SENSOR_UART_PORT              UART_NUM_1
#define SENSOR_UART_TX                GPIO_NUM_1
#define SENSOR_UART_RX                GPIO_NUM_2
#define SENSOR_UART_DE_RE             GPIO_NUM_4

#define SENSOR_BAUD_RATE              9600
#define SENSOR_BUF_SIZE               256

// Modbus RTU — Sensor de lluvia
#define RAIN_SLAVE_ID                 1
#define RAIN_REGISTER_ACCUMULATED     0x006F
#define RAIN_SCALE_FACTOR_MM          10.0f

/************************************************************
 * RS485 — DTU / Modem
 ************************************************************/

#define DTU_UART_PORT                 UART_NUM_2
#define DTU_UART_TX                   GPIO_NUM_5
#define DTU_UART_RX                   GPIO_NUM_6
#define DTU_UART_DE_RE                GPIO_NUM_7

#define DTU_BAUD_RATE                 9600
#define DTU_BUF_SIZE                  256

/************************************************************
 * I2C — RTC DS3231M
 ************************************************************/

#define RTC_I2C_SDA                   GPIO_NUM_8
#define RTC_I2C_SCL                   GPIO_NUM_9

#define RTC_SQW_INT                   GPIO_NUM_16

/************************************************************
 * SPI — MicroSD
 ************************************************************/

#define SD_SPI_CS                     GPIO_NUM_10
#define SD_SPI_MOSI                   GPIO_NUM_11
#define SD_SPI_CLK                    GPIO_NUM_12
#define SD_SPI_MISO                   GPIO_NUM_13

#define SD_DETECT                     GPIO_NUM_15

/************************************************************
 * Debug
 ************************************************************/

#define LED_DBG                       GPIO_NUM_21

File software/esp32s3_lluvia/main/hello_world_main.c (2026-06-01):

#include <stdio.h>
#include "freertos/FreeRTOS.h"
#include "freertos/task.h"
#include "driver/gpio.h"

#define LED_GPIO GPIO_NUM_21

void app_main(void)
{
    // Configurar GPIO21 como salida
    gpio_reset_pin(LED_GPIO);
    gpio_set_direction(LED_GPIO, GPIO_MODE_OUTPUT);

    while (1)
    {
        // Encender LED
        gpio_set_level(LED_GPIO, 1);
        printf("LED ON\n");

        vTaskDelay(pdMS_TO_TICKS(1000));

        // Apagar LED
        gpio_set_level(LED_GPIO, 0);
        printf("LED OFF\n");

        vTaskDelay(pdMS_TO_TICKS(1000));
    }
}

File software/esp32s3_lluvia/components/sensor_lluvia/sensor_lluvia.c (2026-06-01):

#include "sensor_lluvia.h"

#include <string.h>
#include "esp_log.h"
#include "esp_err.h"
#include "rs485.h"
#include "rs485_config.h"

static const char *TAG = "SENSOR_LLUVIA";

static uint16_t modbus_crc16(const uint8_t *data, size_t len)
{
    uint16_t crc = 0xFFFF;

    for (size_t i = 0; i < len; i++) {
        crc ^= data[i];

        for (int j = 0; j < 8; j++) {
            if (crc & 0x0001) {
                crc = (crc >> 1) ^ 0xA001;
            } else {
                crc >>= 1;
            }
        }
    }

    return crc;
}

esp_err_t sensor_lluvia_init(void)
{
    rs485_config_t cfg = {
        .uart_port = SENSOR_UART_PORT,
        .tx_pin = SENSOR_UART_TX,
        .rx_pin = SENSOR_UART_RX,
        .de_re_pin = SENSOR_UART_DE_RE,
        .baud_rate = SENSOR_BAUD_RATE,
    };

    esp_err_t err = rs485_init(&cfg);

    if (err == ESP_OK) {
        ESP_LOGI(TAG, "Sensor lluvia RS485 inicializado. Slave ID=%d", RAIN_SLAVE_ID);
    } else {
        ESP_LOGE(TAG, "Error inicializando RS485 lluvia");
    }

    return err;
}

esp_err_t sensor_lluvia_leer_acumulado(float *rain_mm)
{
    if (rain_mm == NULL) {
        return ESP_ERR_INVALID_ARG;
    }

    uint8_t request[8];

    request[0] = RAIN_SLAVE_ID;
    request[1] = 0x03;
    request[2] = (RAIN_REGISTER_ACCUMULATED >> 8) & 0xFF;
    request[3] = RAIN_REGISTER_ACCUMULATED & 0xFF;
    request[4] = 0x00;
    request[5] = 0x01;

    uint16_t crc = modbus_crc16(request, 6);
    request[6] = crc & 0xFF;
    request[7] = (crc >> 8) & 0xFF;

    uint8_t response[RS485_BUF_SIZE] = {0};

    rs485_send(SENSOR_UART_PORT, SENSOR_UART_DE_RE, request, sizeof(request));

    int len = rs485_receive(
        SENSOR_UART_PORT,
        response,
        sizeof(response),
        pdMS_TO_TICKS(1000)
    );

    if (len < 7) {
        ESP_LOGW(TAG, "Respuesta Modbus incompleta. Len=%d", len);
        return ESP_FAIL;
    }

    uint16_t crc_rx = response[len - 2] | (response[len - 1] << 8);
    uint16_t crc_calc = modbus_crc16(response, len - 2);

    if (crc_rx != crc_calc) {
        ESP_LOGW(TAG, "CRC invalido. RX=0x%04X CALC=0x%04X", crc_rx, crc_calc);
        return ESP_FAIL;
    }

    if (response[0] != RAIN_SLAVE_ID || response[1] != 0x03 || response[2] != 0x02) {
        ESP_LOGW(TAG, "Respuesta Modbus inesperada");
        return ESP_FAIL;
    }

    uint16_t raw = ((uint16_t)response[3] << 8) | response[4];

    *rain_mm = raw / RAIN_SCALE_FACTOR_MM;

    ESP_LOGI(TAG, "Lluvia acumulada raw=%u -> %.2f mm", raw, *rain_mm);

    return ESP_OK;
}

esp_err_t sensor_lluvia_reset_acumulado(void)
{
    uint8_t request[8];

    request[0] = RAIN_SLAVE_ID;
    request[1] = 0x06;
    request[2] = (RAIN_REGISTER_ACCUMULATED >> 8) & 0xFF;
    request[3] = RAIN_REGISTER_ACCUMULATED & 0xFF;
    request[4] = 0x00;
    request[5] = 0x00;

    uint16_t crc = modbus_crc16(request, 6);
    request[6] = crc & 0xFF;
    request[7] = (crc >> 8) & 0xFF;

    uint8_t response[RS485_BUF_SIZE] = {0};

    rs485_send(SENSOR_UART_PORT, SENSOR_UART_DE_RE, request, sizeof(request));

    int len = rs485_receive(
        SENSOR_UART_PORT,
        response,
        sizeof(response),
        pdMS_TO_TICKS(1000)
    );

    if (len < 8) {
        ESP_LOGW(TAG, "Respuesta incompleta al reset. Len=%d", len);
        return ESP_FAIL;
    }

    uint16_t crc_rx = response[len - 2] | (response[len - 1] << 8);
    uint16_t crc_calc = modbus_crc16(response, len - 2);

    if (crc_rx != crc_calc) {
        ESP_LOGW(TAG, "CRC invalido en reset. RX=0x%04X CALC=0x%04X", crc_rx, crc_calc);
        return ESP_FAIL;
    }

    if (memcmp(request, response, 6) != 0) {
        ESP_LOGW(TAG, "Eco de reset Modbus inesperado");
        return ESP_FAIL;
    }

    ESP_LOGI(TAG, "Registro lluvia 0x%04X reiniciado correctamente", RAIN_REGISTER_ACCUMULATED);

    return ESP_OK;
}

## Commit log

2026-03-24 Voy a subir los archivos
    [DS3231.kicad_sch, Estacion_lluvia.kicad_pcb, Estacion_lluvia.kicad_sch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]
2026-03-25 Se agregaron nuevos archivos
    [DS3231.kicad_sch, Estacion_lluvia.kicad_pcb, Estacion_lluviaV2.kicad_pcb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]
2026-06-01 station code + tests /
    [Estacion_lluviaV2.step]
2026-06-01 mechanis changes
    [Caja_P4.SLDPRT, Soporte_Sensor_P4.SLDPRT, Tapa_P4.SLDPRT]
2026-06-01 changes on operation flow
2026-06-01 Initial commit - hardware, software, mechanical and docs structure
    [BOM_Estacion_lluviaV4.xlsx, Caja_P4.SLDPRT, DS3231.kicad_sch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]
2026-06-01 Add soldered board photo
